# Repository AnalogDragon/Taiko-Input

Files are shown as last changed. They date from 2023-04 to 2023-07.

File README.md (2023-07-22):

# Taiko Input

太鼓输入硬件，usb为HID设备，可以连接2个鼓和8通道的数字量输入。  
文中所提到的太鼓-虹相关的软件，皆下载自互联网。

- [English Version](./README_EN.md)

## [硬件工程](./HW/)
## [USB 单片机](./USB-MCU/)
## [采样单片机](./Sampling-MCU/)
## [上位机](./QT-APP/)
## [文档](./TEXT/)

## 工程结构：
```
|—— HW
    |—— taiko-io
    |—— taiko-io-mini
|—— USB-MCU
    |—— TK_usb_CH552
    |—— TK_usb_CH552_mini
|—— Sampling-MCU
    |—— 8chV3_WithCH552
|—— QT-APP
    |—— APP1_Taiko_IO_Setting
|—— TEXT
```

## HW 硬件工程

硬件工程位于此目录下。  

`taiko-io/`目录内的是双鼓的工程，可用于两个鼓的使用环境（街机），工程使用KICAD设计。  
此项目硬件包含8路模拟输入和8路数字量输入，板载配置接口，单usb供电。  

`taiko-io-mini/`目录内的是单鼓的工程，一般用于一个鼓的使用环境，工程使用LCEDA设计。  
此项目硬件包含4路模拟输入和4个按键，需要测试点配置，单usb供电。  

## USB-MCU USB单片机

USB单片机的软件工程位于此目录下。包含两个软件，根据硬件不同，适配的软件工程也不同。  
使用的单片机为 CH552/CH554，是一款USB 8位单片机。  

`TK_usb_CH552/`目录内的软件适配双鼓硬件（街机），能枚举成为一个USB-HID键盘。  

`TK_usb_CH552_mini/`目录内的软件适配单鼓硬件，可以枚举成不同的USB设备。比如说USB-HID键盘或n******o switch适用的手柄设备。  

软件使用keil 4编译，编译前根据宏可以关闭/打开相关的软件功能。  

## Sampling-MCU 采样单片机

采样单片机的软件工程位于此目录下。软件使用宏区分两款硬件。  
使用的单片机为 STM32G030。  

软件使用keil 5编译，编译前根据宏可以关闭/打开相关的软件功能，切换硬件版本。  

## QT-APP 上位机

上位机的软件工程位于此目录下。上位机可以用于配置硬件的相关参数。  

使用的UI框架为QT 5  

## TEXT 文档

一些中间文档和输出文档位于此目录下。  

# 系统框图
详见[硬件工程](./HW/)  

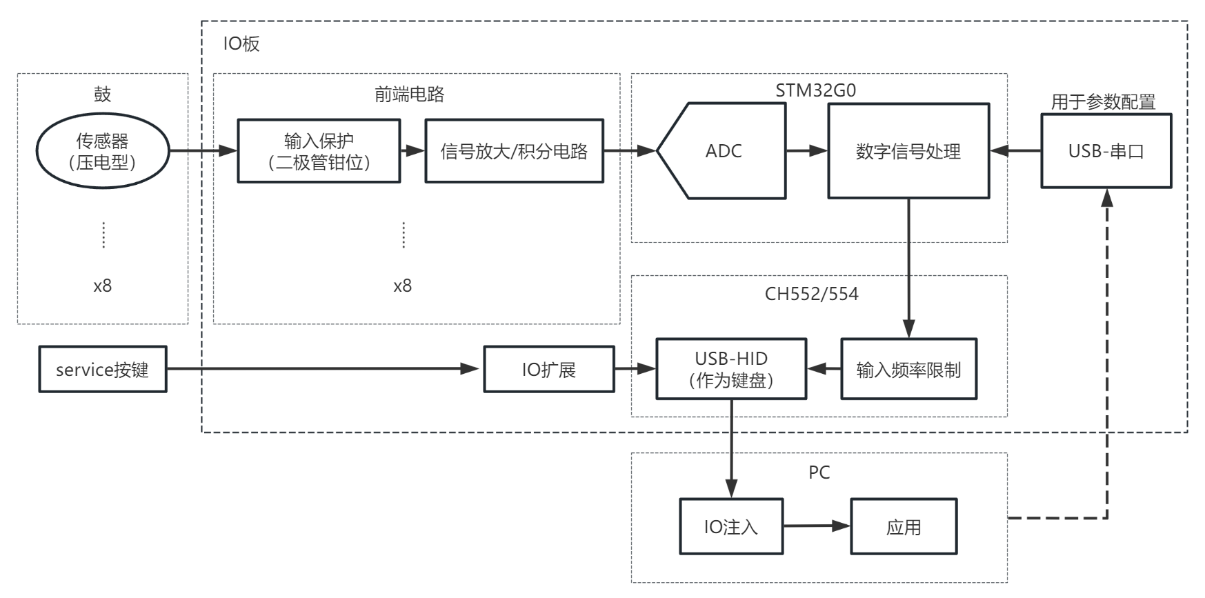
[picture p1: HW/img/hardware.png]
系统框图
  
系统框图  

# 做的一些裂开设计

    主要是通过观察游戏运行的特征，去做体验上的优化。可能合理也可能不合理。

## 游戏软件运行的观察
- 输入频率限制：ns平台的游戏与虹均有输入频率限制。经过测试，每个player独立的。同一个玩家，单个通道限制最高30次每秒，四个通道一起限制60次每秒。超过这个频率的输入会被扔掉。  
也就是说如果只敲左咚或者右咚，则最多30打每秒，而如果左右咚交替输入，能提高到60打每秒。  

- ns平台本身的硬件限制：按键输入会有一个很长的滤波，且按下与松开均需要保持一段时间才能生效。  
在ns游戏内，这个一段时间需要大于20ms。但是主页上则要远大于20ms甚至要到100ms，可能是ns支持可变滤波时间。  

- 虹的数据注入：

## 输出交叉分配

功能实现放在了[USB 单片机](./USB-MCU/)

由于机能或软件运行方式，不同的软件支持的输入最大频率不同，分配输出主要原因是为了能使输入频率达到这台设备的上限。  
表现就是在触发频率高的时候，同一个通道的输入会分配到另一个通道，不同的设备采取的方案不相同。  
- ns：按键消抖做的比较激进，直接在有高频输入的时候，优先分配给同侧的两个按键。
- 虹：游戏软件限制了全局输入的最高频率和单个通道输入的最高频率，可能是为了方便计算图像，这边限制了单一个通道的输入频率，且将同为“咚”的输入分配给空闲的通道。
- PC的其他应用（比如说Open Taiko等）：软件没有做输入频率限制，所以不需要做分配。  

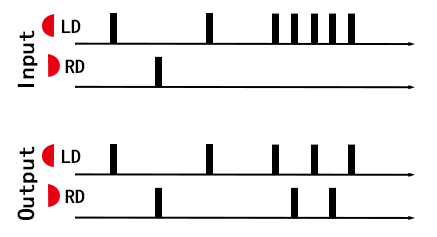
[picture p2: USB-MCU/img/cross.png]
交叉分配
  
适配虹的交叉分配示意图  

## 信号触发与串音检测

多路信号同时输入的时候，会选择触发幅值更高的通道。  
鼓的传感器被固定在几块相对独立的木板上。通常情况下，直接敲击木板得到的信号，强度是远大于受震动干扰或串扰带来的信号。  

这里的做法是，在首次触发后做微小的延时等待其他通道触发。如果在这期间有多个通道被触发，则输出这里面最强信号的通道。  

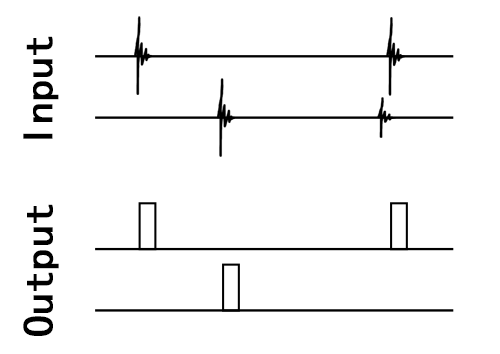
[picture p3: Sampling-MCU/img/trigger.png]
触发

触发示意图  

    如果怎么调都会串音，需要考虑是鼓的结构导致的。检查鼓是不是传感器脱落，木板是不是调节的高度不合适等。

# 外观

详见[硬件工程](./HW/) 

## 双鼓硬件（街机/两个鼓场景）

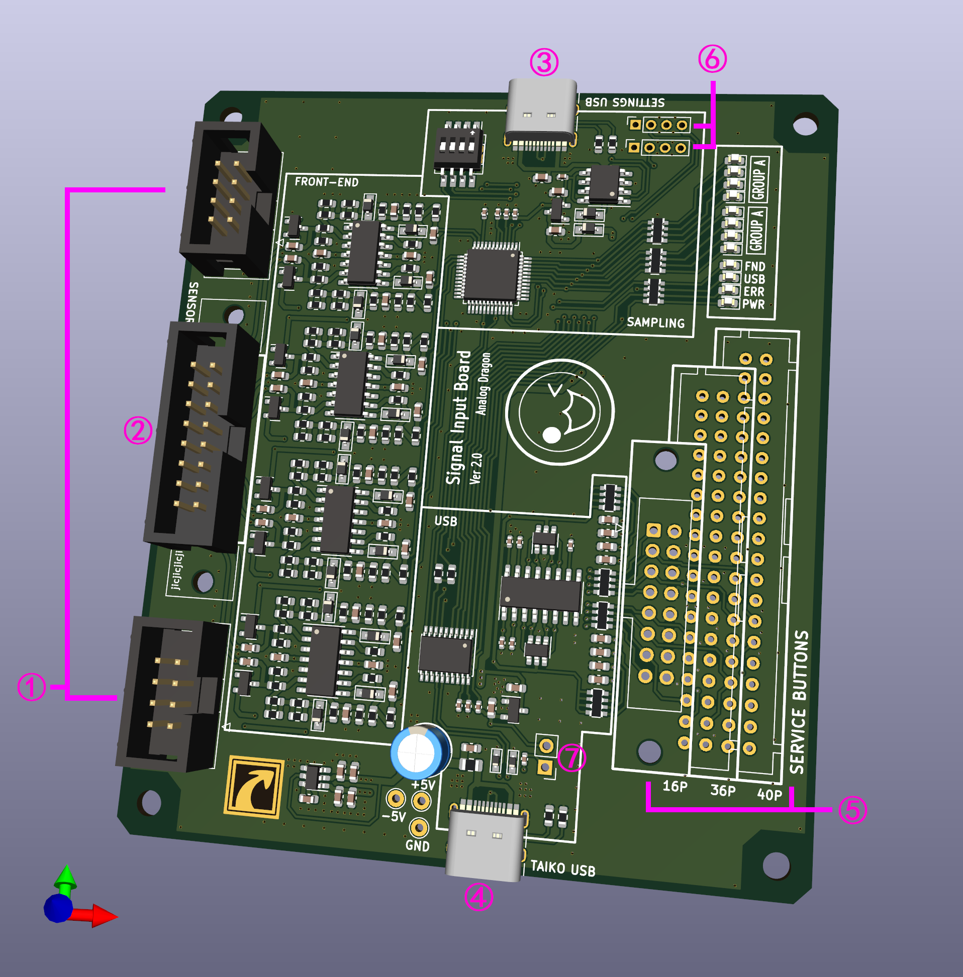
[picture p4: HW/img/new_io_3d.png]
双鼓的硬件3d图

双鼓的硬件3d图  

## 单鼓硬件（自己玩）

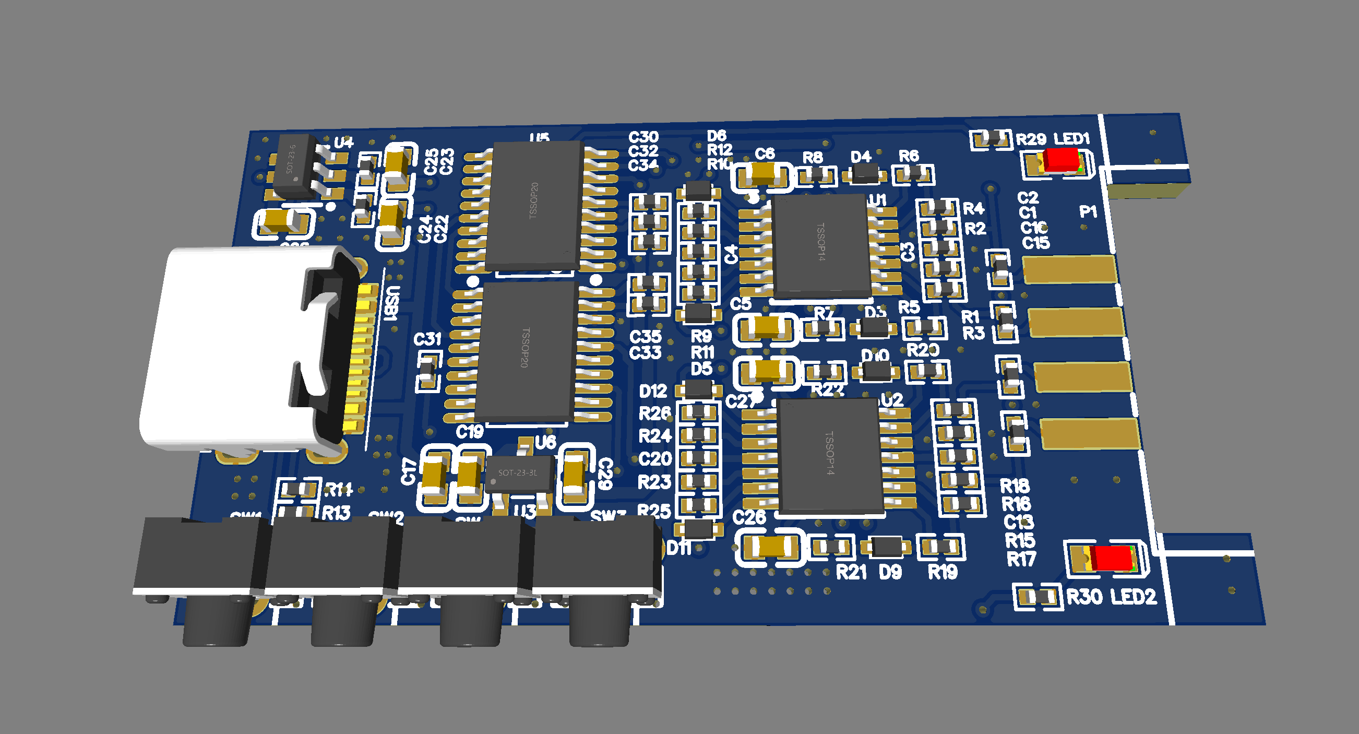
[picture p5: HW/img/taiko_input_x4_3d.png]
单鼓的硬件3d图
  
单鼓的硬件3d图

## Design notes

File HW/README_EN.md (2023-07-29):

# Taiko Input Hardware

Taiko Input Hardware

There are dual taiko and single taiko hardware options. The dual taiko design is intended for arcade or two-taiko setups, while the single taiko hardware is a simplified version of the dual taiko hardware with half of the input frontend removed. There are no significant differences between the two in terms of hardware.

[中文版](./README.md)

[Home](../)

## Hardware Structure

The entire system is composed of sensors (taiko), frontend, sampling, USB, and PC. The frontend, sampling, and USB are located on the input hardware. In addition, there are other components such as power supply and filtering circuitry not shown in the structural diagram.

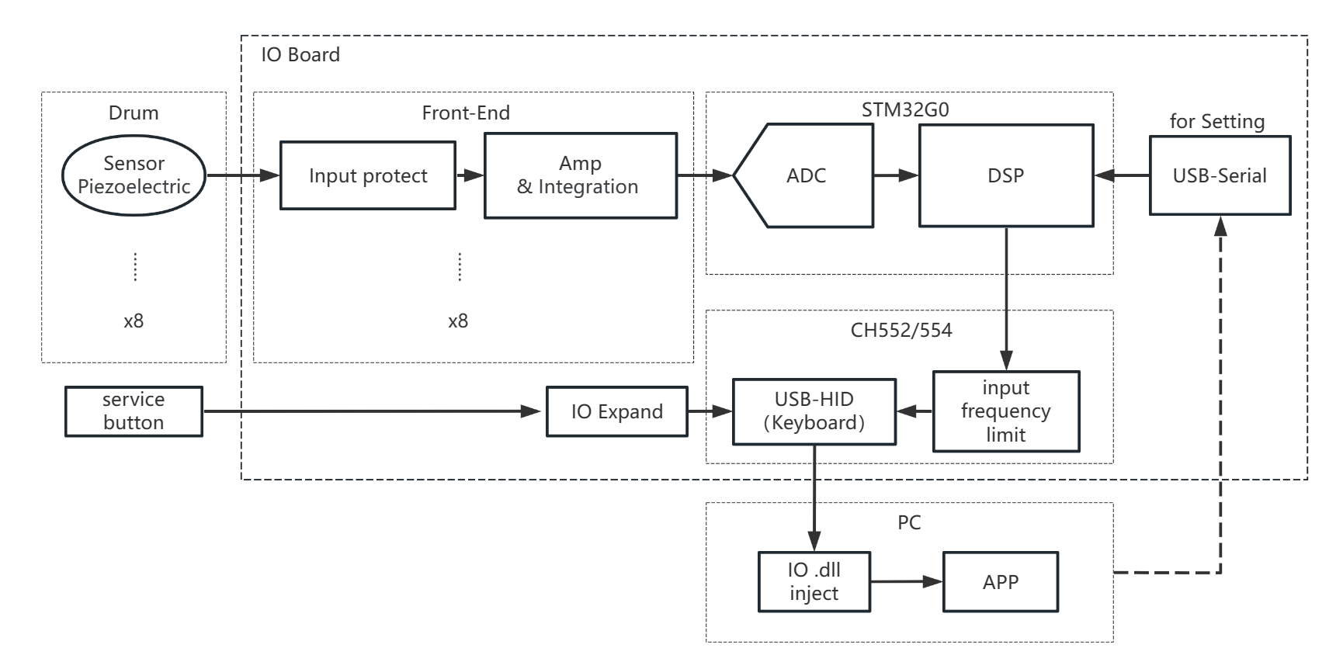
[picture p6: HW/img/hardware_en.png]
Hardware Structure Diagram

Hardware Structure

## Frontend Circuitry

The frontend circuitry adopts a design similar to the SIF Board, amplifying and integrating the signal before limiting the output.

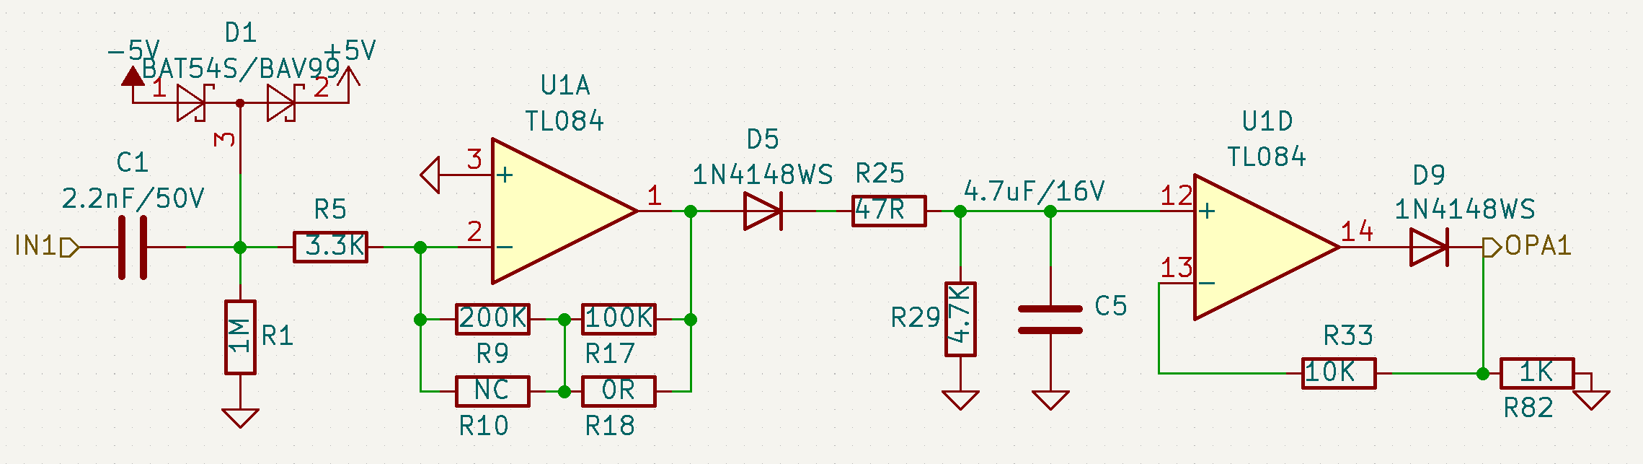
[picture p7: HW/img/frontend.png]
Frontend Circuitry

One of the frontend circuitry paths

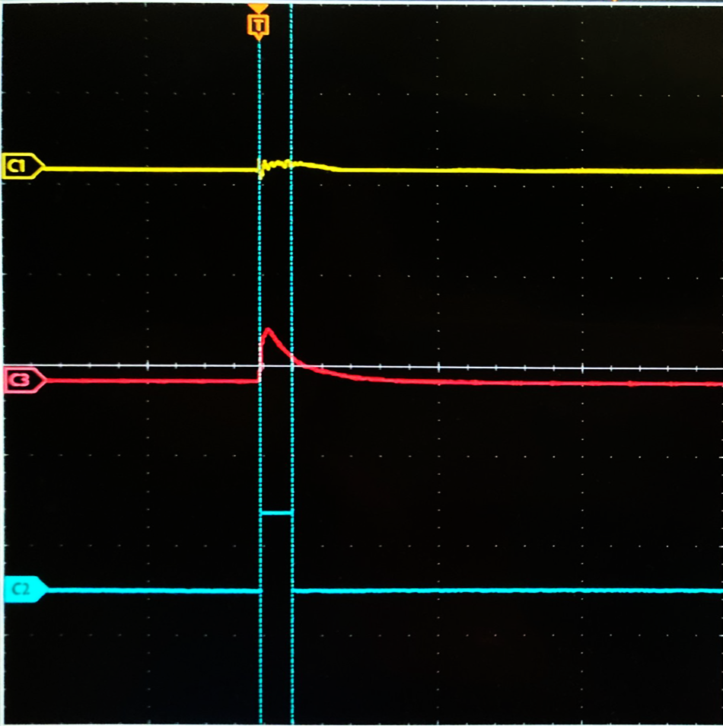
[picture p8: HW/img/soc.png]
Frontend Circuitry Test Signal

Signal waveform

Due to the high bandwidth and small signal amplitude from the piezoelectric sensors, direct sampling is not suitable. The frontend circuitry processes the input signal into a form that is suitable for sampling. In the oscilloscope screenshot, C1 (yellow) represents the sensor output, C3 (red) represents the signal after frontend processing, and C2 (blue) represents the output after program recognition.

# Hardware

The hardware consists of dual taiko hardware and single taiko hardware. The dual taiko hardware is the complete version, suitable for arcade environments. The single taiko hardware is a modified version of the dual taiko hardware with half of the input circuit removed, and it is compatible with more single-player scenarios in software.

## Dual Taiko Hardware

[Hardware Engineering](./taiko-io/)
[Schematic](./taiko-io/new_io.pdf)

3D View of Dual Taiko Hardware
3D view of dual taiko hardware

### Interfaces

- 1 Two single taiko input interfaces, with interface definitions inspired by Taiko Force.
- 2 One dual taiko input interface that can be soldered with an IDC-16P ribbon connector or an XAD connector (B16B-XADSS-N) to accommodate different interfaces of dual taiko.
- 3 Configuration USB interface for configuring the sampling microcontroller.
- 4 Taiko USB interface, when plugged into a computer, it enumerates as a USB-HID keyboard device for receiving taiko data.
- 5 Service button input, soldered with an XAD or IDC connector to connect different button panels. The 16P interface is for custom connections, 36P is for the old(12th) IO board interface(B36B-XADSS-N), and 40P is for newer the frame's IO board interface(B40B-XADSS-N). It can connect up to 8 buttons with common ground.
- 6 STM32 burning interface and configuration serial port.
- 7 CH552/CH554 boot selection switch.

## Single Taiko Hardware
[Hardware Engineering](./taiko-io-mini/)
[Schematic](./taiko-io-mini/Taiko_input_x4.pdf)

3D View of Single Taiko Hardware 3D View of Single Drum Hardware
3D view of single taiko hardware

### Interfaces

- Can only connect 4-channel sensors for a single taiko, with interface definitions inspired by Taiko Force.
- Four buttons for mode selection and other functions.

# Assembly

## Dual Taiko Hardware

The dual taiko hardware does not have an external enclosure. It is assembled directly using screws, following the assembly approach commonly used in arcades.

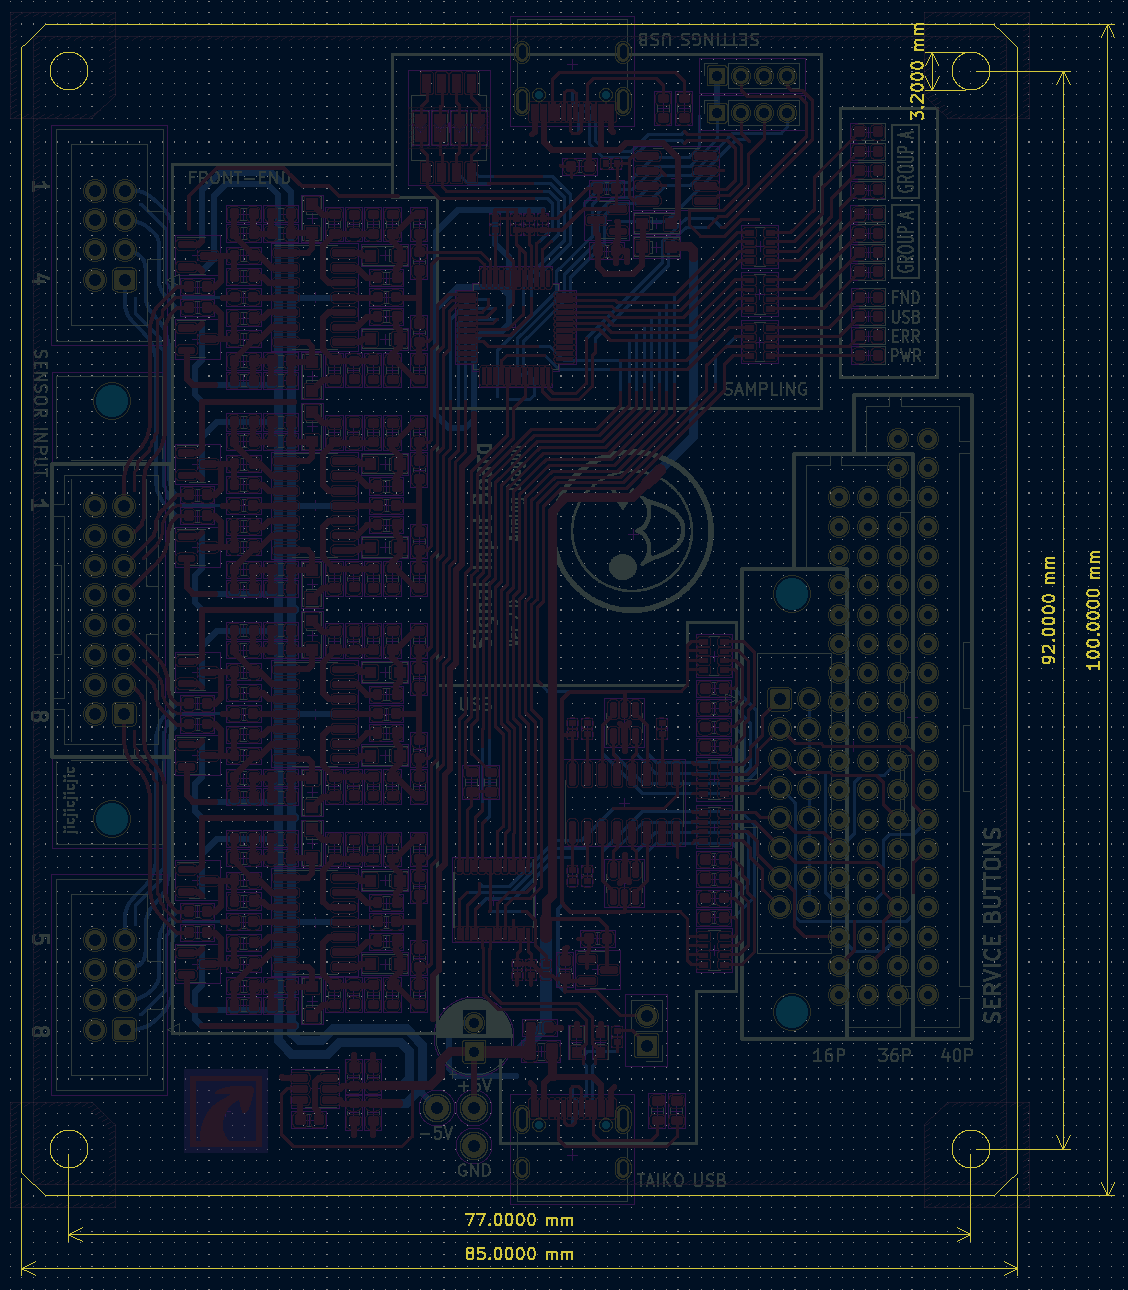
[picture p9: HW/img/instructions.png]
Assembly Dimension Diagram

Assembly Dimension Diagram

## Single Taiko Hardware

The single taiko hardware uses a more common and portable casing, making it easier to carry and connect.

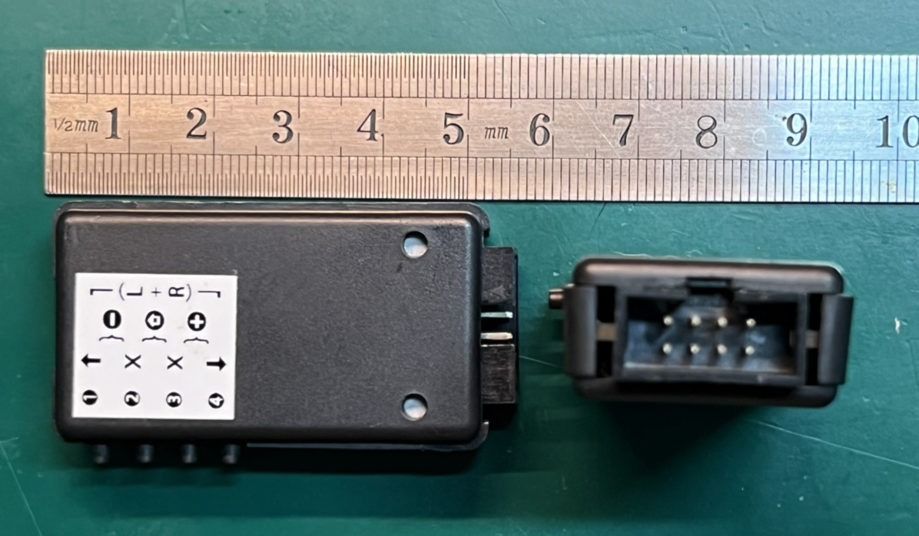
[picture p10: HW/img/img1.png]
Assembly Illustration 1

Assembly Illustration 1  

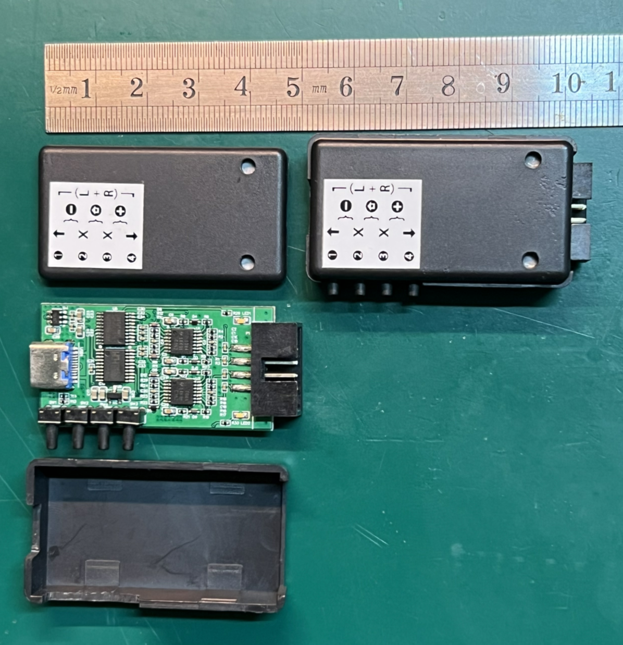
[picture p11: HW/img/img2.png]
Assembly Illustration 2

Assembly Illustration 2  

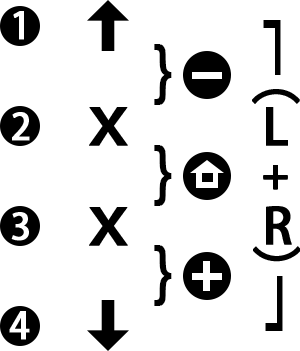
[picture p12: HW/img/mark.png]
tag
  
tag

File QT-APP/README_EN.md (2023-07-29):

# Host Computer
    QT, WIN64
    The host computer software is used to configure the parameters of the sampling microcontroller.

[中文版](./README.md)

[Home](../)

## Instructions

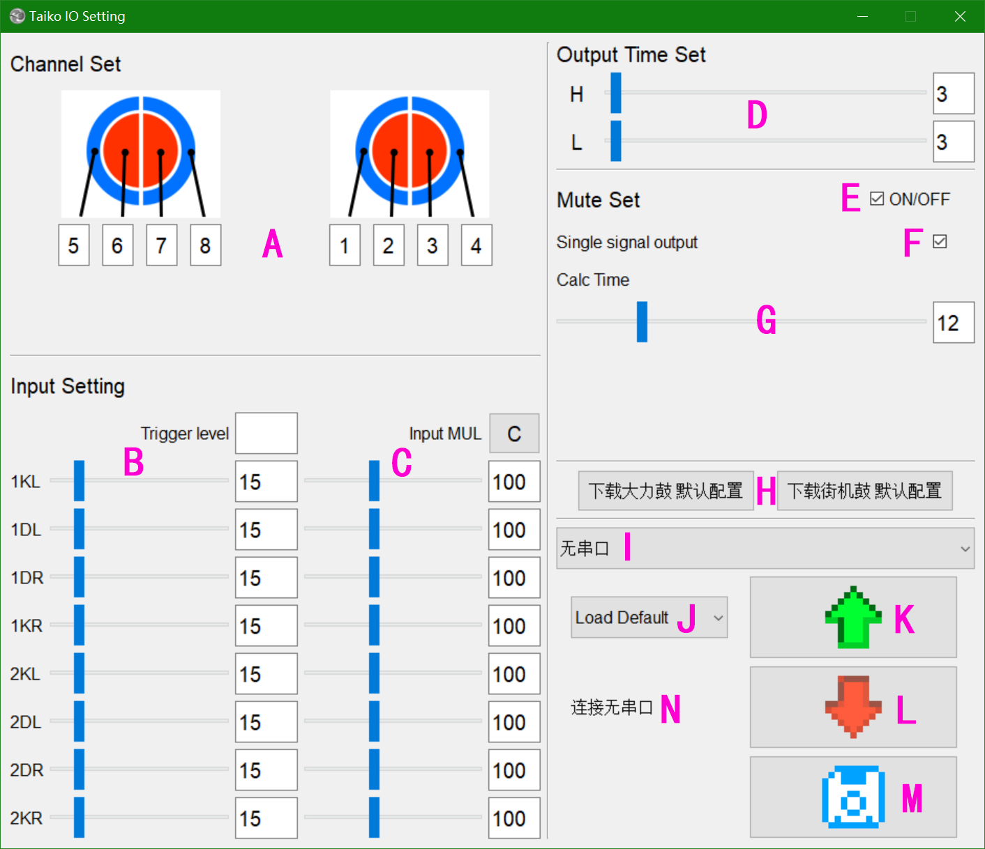
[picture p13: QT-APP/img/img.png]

Screenshot  

### Software Interface

- A-Taiko sensor channel sequence configuration
- B-Input configuration-Trigger threshold (triggering is done in hardware, no obvious effect in software configuration)
- C-Input configuration-Multiplication factor (configure this when a certain sensor is exceptionally sensitive or insensitive, C for reset)
- D-Output time configuration, H for hold time when pressing, L for hold time when releasing, no response to other inputs during hold time
- E-Shielding configuration (used to calculate crosstalk caused by the physical structure of the taiko)
- F-Shielding configuration-Single response (selecting this will trigger only one sensor each time)
- G-Shielding configuration-Calculate rounds (set to 0 to disable calculation, directly trigger according to the fastest speed)
- H-Some default parameters (for Taiko Force and arcade taiko)
- I-Serial port selection
- J-Select the parameter group on the upload board
- K-Upload parameter button
- L-Download parameter button (this step does not store data, data will be lost when the microcontroller is reset)
- M-Save parameter button
- N-Software status

### Configuration Process

- 1 Select the serial port, click upload, and the status will be displayed as `Success` (used to determine if the connection is successful)
- 2 Reset the preset parameters according to your needs or upload old parameters
    - For modifications based on the old parameters, select `Load Saved`, and then press the upload parameter button
    - For modifications based on the default configuration, click the desired default configuration button (the two default configurations only differ in taiko mapping)
- 3 After making modifications, click the download parameter button and confirm if the parameters are reasonable on the taiko
- 4 Click the save parameter button

## Other Instructions
- When using single taiko hardware, the parameters for the second taiko are meaningless
- Default configurations may have issues; you can make fine adjustments based on the default parameters to suit your taiko
- The sensor wire sequence of the taiko can be remapped through this APP.

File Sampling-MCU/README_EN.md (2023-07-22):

# Sampling MCU Project
    Sampling Microcontroller Software
    MCU: stm32g030, IDE: KEIL 5

[中文版](./README.md)  

[Home](../)  

## Dual Taiko Version and Single Taiko Version

Differentiate the software between dual taiko and single taiko hardware using macros in /main.h/.  
It is important to note that the software compiled for single taiko hardware cannot be used on dual taiko hardware due to differences in initialization.  

Single Taiko Version:
```
...
#define IS_4CH_MODE 
...
```

Dual Taiko Version (comment out this line of code):
```
...
//#define IS_4CH_MODE 
...
```

## Digital Signal Processing

Digital signal processing mainly involves trigger handling, debouncing, and determining if there is signal crosstalk.  
Since the taiko contains a physical structure, vibrations can cause signal misfires. Therefore, it is necessary to determine and output the signals received at the same time.  

### Processing Flowchart

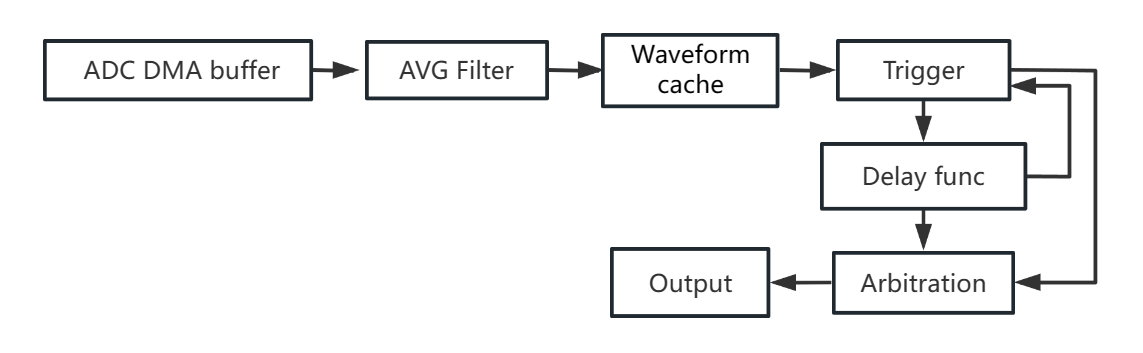
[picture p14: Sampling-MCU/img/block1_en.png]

Data flow diagram  

After the signal is sampled, it is recorded as a waveform array, and a trigger function is used to determine if there is a signal with the expected strength.  
The delayed output ensures that when a signal arrives, it does not miss the trigger of other sensors. If other channels are triggered during the delay, the triggered values will also be recorded.  
The arbitration function determines the maximum strength among the triggered channels during the delay, and then reset the states of other functions.  
The output signal is sent to the USB microcontroller by the output device.  

### Signal Triggering and Crosstalk Detection

When multiple signals are input simultaneously, the channel with the higher amplitude will be triggered.  
The taiko sensors are fixed on several relatively independent boards. Typically, the signal obtained by directly striking the board has a much higher strength than the signals caused by vibration interference or crosstalk.  

The approach here is to wait for a small delay after the initial trigger to allow other channels to trigger. If multiple channels are triggered during this period, then the channel with the strongest signal among them is output.  

Triggering
Triggering illustration  

## Software Flowchart

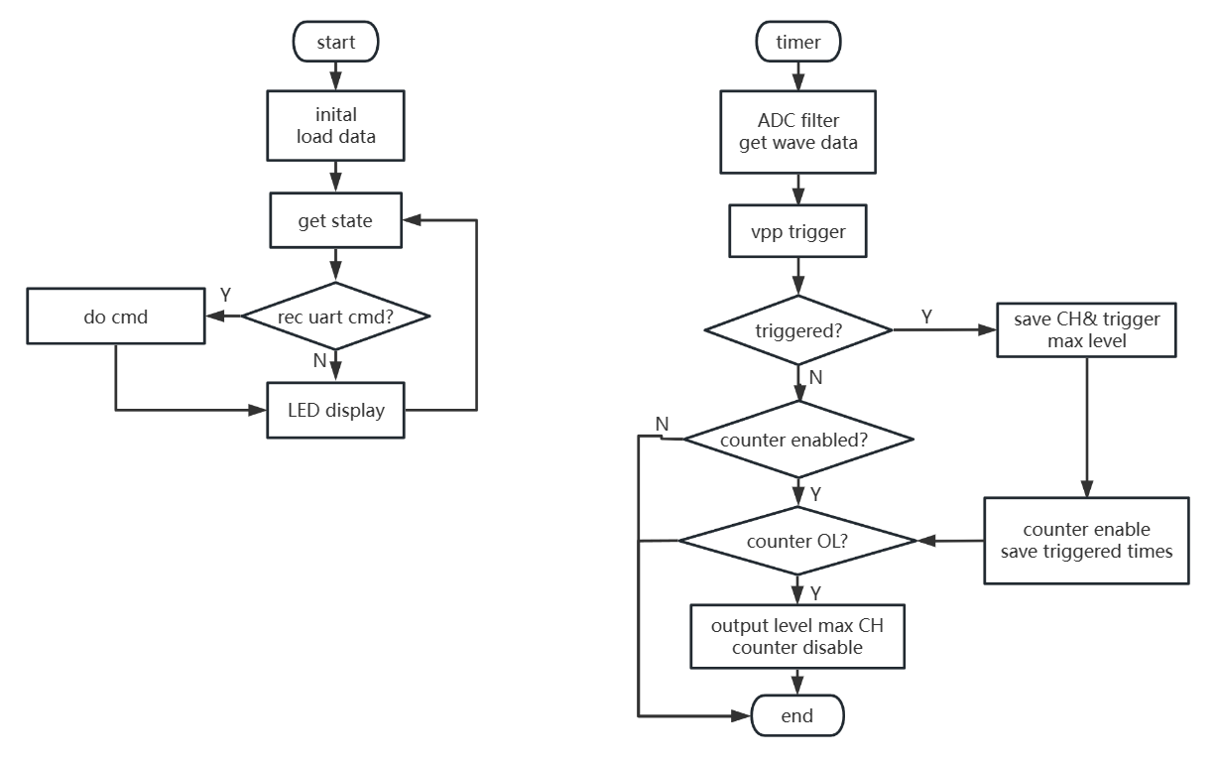
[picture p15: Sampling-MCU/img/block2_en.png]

Data flow diagram  

The software can be configured for speed-priority triggering (setting the period to 0) or maximum peak triggering.  
The longer the number of cycles, the longer the calculated period. When the number of cycles is set to 0, triggering is performed in a speed-priority manner.  

## Configuring Sampling Parameters

Sampling parameters are configured through the upper computer software  

[Upper Computer Software](../QT-APP/)  

## Data Output

Data is sent to the computer using a USB microcontroller  

[USB MCU Software](../USB-MCU/)

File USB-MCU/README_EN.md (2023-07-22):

# USB-MCU Project

[中文版](./README.md)  

[Homepage](../)  

MCU: CH552, IDE: KEIL 4  
Microcontroller's official website: [WCH CH552](https://www.wch.cn/products/CH552.html)  

## Software Flow
The software runs according to the following flow:

```
Input -> Output Frequency Limitation -> Output Assignment -> Key Mapping -> USB
```

### Output Frequency Limitation
The output frequency limitation is mainly due to the hardware or program that receives the data. When it receives data that exceeds its processing capability, packet loss may occur.  
After multiple tests, the software input limitation for ニジイロ is a maximum input frequency of 60Hz for all channels and 30Hz for signals of the one channel.  
The n******o switch limits the input signal filter to 20ms (both press and release are around 20ms; values smaller than this may result in sticky inputs).  
Other game software running on different computers usually doesn't have this convenient limitation, but there is usually a filtering of around 10ms on the selection page.  

### Output Assignment
Due to different device capabilities or software running methods, different software support different maximum input frequencies. The purpose of allocating the output channels is to achieve the input frequency limit of the particular device.  
The behavior observed is that when the triggering frequency is high, inputs from the same channel will be allocated to another channel. Different devices adopt different approaches:
- ns: Aggressive debouncing is performed, and when there are high-frequency inputs, they are allocated primarily to the two adjacent keys on the same side.
- ニジイロ: The game software limits the maximum global input frequency and the maximum input frequency for a single channel. This may be for the convenience of calculating images. Here, the input frequency for a single channel is limited, and inputs of the same type (e.g., same "dong") are allocated to idle channels.
- Other applications on PC (such as Open Taiko): These software programs do not have input frequency limitations, so no allocation is needed.

Cross Assignment  
Cross assignment diagram for compatibility with ニジイロ  

### Key Mapping
- For dual-taiko hardware, taiko inputs are mapped to keyboard inputs DFJK ZXCV, and service key inputs are mapped to keyboard inputs 12345678.
- For single-taiko hardware, there are two modes: NS mode and keyboard mode. For NS mode, the input keys are shown in the image below. For keyboard mode, you can set the inputs as DFJK or ZXCV through the buttons, with DFJK being the default.

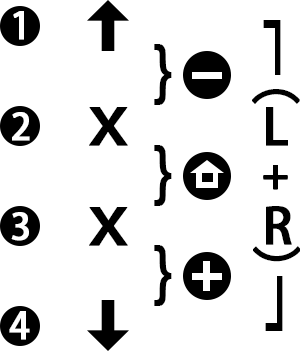
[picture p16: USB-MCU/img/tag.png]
Tags
  
Tags for single-taiko hardware  

## Modifying the Program

### Dual-taiko Software

- To disable the output assignment feature, modify the `WITHOUT_OUTPUT_ASSIGN` macro inside `CompatibilityHID.C` by uncommenting it.
- To modify the parameters related to output frequency limitation, modify the `EXCHANGE_DATA` macro inside `CompatibilityHID.C`.
- To change the key values, modify the array inside the `Enp2BlukIn` function in `CompatibilityHID.C`.

### Single-taiko Software
The single-taiko software integrates three modes: NS mode (using HORI's PID/VID, where NS only verifies the PID/VID without any further encryption); keyboard mode compatible with ニジイロ (60Hz input lock); and keyboard mode compatible with other taiko taiko software (unlock the limitations and disable the output assignment).

- To change the default startup mode, modify the `MODE_STARTUP` macro inside `CompatibilityHID.C`.
- To switch modes during startup within 1 second, use the following button combinations:
```
...
if(!KEY1)start_up_mode = MODE_NS_GP;
if(!KEY2)start_up_mode = MODE_KEYBOARD;
if(!KEY3)start_up_mode = MODE_KB_LMT;
if(!KEY4)start_up_mode = MODE_STARTUP;
...
```
- During runtime, holding down buttons 1 to 4 will trigger a reset, allowing you to switch modes again.

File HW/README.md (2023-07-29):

# Taiko Input 硬件

Taiko Input 硬件

分为双鼓与单鼓硬件，双鼓设计用于街机或两个鼓的场景，单鼓的硬件则是双鼓硬件简单地切去一半输入前端设计的，在硬件上两者并无很大的差异。

[English Version](./README_EN.md)  

[主页](../)  

## 硬件结构

    整体系统分为传感器（鼓）、前端、采样、USB、PC，其中前端、采样、USB三部分位于input硬件上。
    除此之外还，有电源、滤波电路等未在结构图中体现。

硬件结构图
硬件结构  

## 前端电路

    前端电路采用了与SIF Board近似的设计，先进行信号的放大与积分，再限制输出。

前端电路
其中一路前端电路    

前端电路测试信号
信号的波形

由于来自压电传感器的信号带宽高且信号幅值小，不宜直接进行采样。前端电路将输入信号处理成便于采样的信号。  
在示波器截图中，C1(黄色)为传感器输出，C3（红色）为经过前端电路处理后的信号，C2（蓝色）为程序识别后的输出。  

# 硬件

    硬件分为双鼓硬件和单鼓硬件，双鼓硬件为完整版的硬件，可以用于街机环境。  
    单鼓硬件为双鼓硬件删去一半输入电路的硬件，软件上兼容了更多的单人应用场景。  

## 双鼓硬件

[硬件工程](./taiko-io/)  
[原理图](./taiko-io/new_io.pdf)  

双鼓的硬件3d图  
双鼓的硬件3d图  

### 接口

- ① 两个单鼓输入的接口，接口定义借鉴了大力鼓（Taiko Force）。
- ② 一个双鼓的输入接口，可以焊接IDC-16P牛角连接器，或者焊接XAD连接器（B16B-XADSS-N）以兼容不同接口的双太鼓。
- ③ 配置USB接口，用于配置采样单片机。
- ④ 太鼓usb接口，插入电脑会枚举成一个USB-HID键盘设备，用于接收太鼓的数据。
- ⑤ service按键输入，焊接XAD连接器或IDC连接器，以连接不同的按键面板。其中16P接口用于自定义的连接，36P用于12亚的IO板接口（B36B-XADSS-N），40P用于更新框体的IO板接口（B40B-XADSS-N）。可以连接最多8个接地始能的按键。
- ⑥ stm32烧录接口和配置串口。
- ⑦ CH552/CH554的boot选择开关。

## 单鼓硬件
[硬件工程](./taiko-io-mini/)  
[原理图](./taiko-io-mini/Taiko_input_x4.pdf)  

单鼓的硬件3d图  
单鼓的硬件3d图  

### 接口

- 只能连接一个鼓的4路传感器，接口定义借鉴了大力鼓（Taiko Force）的接口。
- 四个按键用于启动的模式选择和其他按键。

# 装配

## 双鼓硬件

    双鼓硬件不设计外盒，借鉴街机的装配方式为使用螺柱直接装配。

装配尺寸图  
装配尺寸图  

## 单鼓硬件

    单鼓的硬件使用了一款较通用的胶盒，可以较为方便的携带和连接。

装配示意图1  
装配示意图1  

装配示意图2  
装配示意图2  

标签  
标签

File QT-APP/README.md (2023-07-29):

# 上位机
    QT，WIN64  
    上位机软件用于配置采样单片机的参数。  

[English Version](./README_EN.md)  

[主页](../)  

## 使用说明

软件截图
软件截图  

### 软件界面

- A-鼓传感器通道顺序配置
- B-输入配置-触发阈值（硬件上做了触发，软件配置这里没有很明显的效果）
- C-输入配置-倍率（当某一路传感器异常灵敏或不灵敏时配置这里，C为复位）
- D-输出时间配置，H为按下保持时间，L为松开保持时间，保持时间内不响应其他输入
- E-屏蔽配置（用于计算鼓的物理结构带来的串音影响）
- F-屏蔽配置-单次响应（选择后每次只会触发一个传感器）
- G-屏蔽配置-计算回合数（设置为0时不计算，直接按照速度最快触发）
- H-一些默认参数（大力鼓和街机鼓）
- I-串口选择
- J-选择上载板上的参数组
- K-上载参数键
- L-下载参数键（这一步不会存储，复位单片机会丢失数据）
- M-保存参数键
- N-软件状态

### 配置流程

- 1 选择串口，点击上载后，显示状态为`Success`（用于判断是否连接成功）
- 2 根据需求重置预设参数，或上载旧的参数
    - 需要在旧参数的基础上修改的，选择`Load Saved`，再按上载参数键
    - 需要在默认配置基础上修改的，直接点按需要的默认配置按钮（两种默认配置只有鼓的映射不同）
- 3 修改后，点击下载参数键后，在鼓上确认参数是否合理
- 4 点击保存参数键

## 其他说明
- 使用单鼓硬件时，第二套鼓的参数无意义
- 默认配置可能会存在问题，可以在默认参数的基础上进行微调以适应你的鼓
- 鼓的传感器线顺序可以通过本上位机进行重映射

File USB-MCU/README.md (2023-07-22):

# USB-MCU工程

[English Version](./README_EN.md)  

[主页](../)  

MCU：CH552，IDE：KEIL 4  
单片机官网：[沁恒CH552](https://www.wch.cn/products/CH552.html)  

## 软件流程
软件按照如下流程运行  

```
输入 -> 输出频率限制 -> 分配输出 -> 键值映射 -> USB
```

### 输出频率限制
对输出进行频率限制主要是因为接收数据的硬件或程序，收到了超过其处理能力的数据时，会产生丢包的现象。  
经过多次测试，虹的软件输入限制为所有通道输入频率最高为60Hz，相同颜色的信号最高为30Hz。  
n******o switch限制输入信号的时间为20ms（按下与抬起都为20ms左右，小于这个值可能会导致输入与上一个输入粘连）  
其他电脑上运行的自治软件，通常无这方便的限制，但是在选择页面会有10ms左右的滤波。  

### 分配输出
由于机能或软件运行方式，不同的软件支持的输入最大频率不同，分配输出主要原因是为了能使输入频率达到这台设备的上限。  
表现就是在触发频率高的时候，同一个通道的输入会分配到另一个通道，不同的设备采取的方案不相同。  
- ns：按键消抖做的比较激进，直接在有高频输入的时候，优先分配给同侧的两个按键。
- 虹：游戏软件限制了全局输入的最高频率和单个通道输入的最高频率，可能是为了方便计算图像，这边限制了单一个通道的输入频率，且将同为“咚”的输入分配给空闲的通道。
- PC的其他应用（比如说Open Taiko等）：软件没有做输入频率限制，所以不需要做分配。  

交叉分配  
适配虹的交叉分配示意图  

### 键值映射
- 双鼓硬件，鼓的输入映射为键盘输入的DFJK ZXCV，服务按键映射为键盘输入的12345678。
- 单鼓硬件，分为ns和键盘输入，其中ns输入键位见下图，键盘输入可以通过按键设置为DFJK或ZXCV，默认为DFJK。

标签  
单鼓硬件的标签  

## 程序的修改

### 双鼓软件

- 关闭分配输出功能，则需修改将位于`CompatibilityHID.C`内的宏`WITHOUT_OUTPUT_ASSIGN`取消注释。
- 修改输出频率限制相关的参数，修改位于`CompatibilityHID.C`内的宏`EXCHANGE_DATA`。
- 修改键值，则修改位于`CompatibilityHID.C`内的`Enp2BlukIn`函数的数组。

### 单鼓软件
单鼓软件内，集成了三种模式，分别是ns模式（借用了HORI的PID/VID，ns只校验了PID/VID，没做其他加密），适配虹的键盘模式（输出锁60Hz输入），适配其他太鼓软件的键盘模式（解锁限制并关闭分配输出）三种。  

- 修改`CompatibilityHID.C`内的宏`MODE_STARTUP`，则可以修改启动时候默认的模式。  
- 启动前1s内按如下按键，则可以切换模式
```
...
if(!KEY1)start_up_mode = MODE_NS_GP;
if(!KEY2)start_up_mode = MODE_KEYBOARD;
if(!KEY3)start_up_mode = MODE_KB_LMT;
if(!KEY4)start_up_mode = MODE_STARTUP;
...
```
- 运行时，按住1~4所有的按键，则可以进行复位，以重新切换模式。

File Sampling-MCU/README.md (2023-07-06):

# Sampling MCU工程
    采样单片机软件
    MCU：stm32g030，IDE：KEIL 5

[English Version](./README_EN.md)  

[主页](../)  

## 双鼓版本与单鼓版本

根据/main.h/内的宏区分软件双鼓与单鼓硬件。  
值得注意的是编译为单鼓的软件放在双鼓的硬件上是不能使用的，原因是初始化不相同。  

单鼓版本：
```
…
#define IS_4CH_MODE 
…
```

双鼓版本（注释这一行代码）：
```
…
//#define IS_4CH_MODE 
…
```

## 数字信号处理

数字信号处理主要需要处理触发、消抖和判断是否信号串扰。  
由于鼓是包含物理结构的，震动的串扰可以导致信号被误触发。所以需要对同一时间收到的信号进行判断再输出。  

### 处理框图

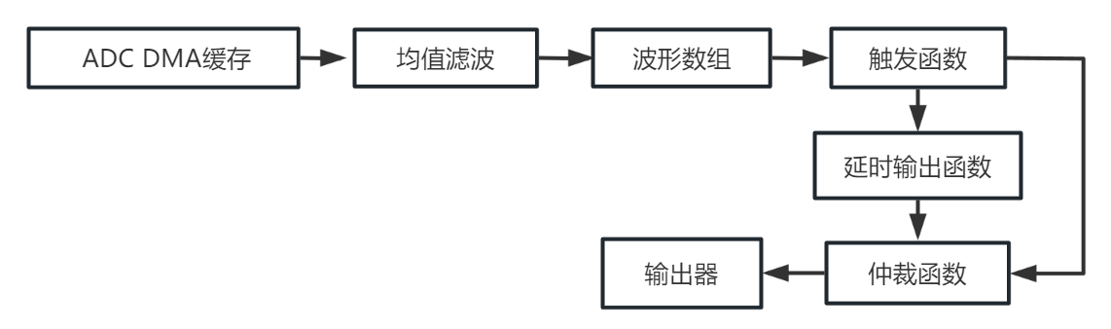
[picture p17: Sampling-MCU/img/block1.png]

数据流向图  

信号被采样后，记录成一个波形数组，通过触发函数来判断是否有符合预期强度的信号。  
通过延时输出来确保信号到来时，不会漏掉其他传感器的触发。当有其他通道在延时期间被触发，则也会记录被触发的值。  
仲裁函数用来判断延时这段时间内，被触发的几个通道中强度最大的值。同时用于复位其他函数的状态。  
输出的信号由输出器输出给USB单片机。  

### 信号触发与串音检测

多路信号同时输入的时候，会选择触发幅值更高的通道。  
鼓的传感器被固定在几块相对独立的木板上。通常情况下，直接敲击木板得到的信号，强度是远大于受震动干扰或串扰带来的信号。  

这里的做法是，在首次触发后做微小的延时等待其他通道触发。如果在这期间有多个通道被触发，则输出这里面最强信号的通道。  

触发
触发示意图  

## 软件流程图

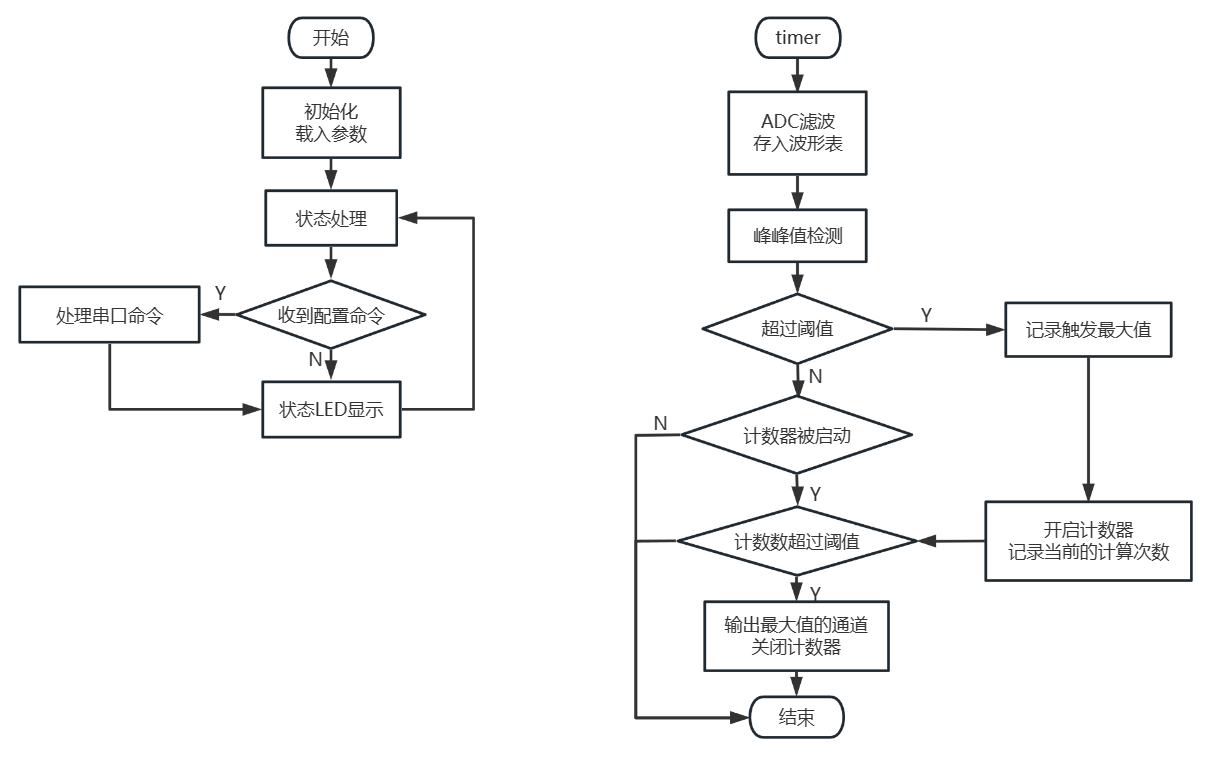
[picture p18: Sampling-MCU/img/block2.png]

数据流向图  

软件可以配置为速度优先触发（周期设置为0）或峰值最大触发。  
回合数越大，则计算的周期越长，当回合数设置为0时，则以速度优先的方式进行触发。  

## 配置采样参数

采样参数通过上位机配置  

[上位机软件](../QT-APP/)  

## 数据输出

数据通过USB单片机发送给电脑  

[USB MCU软件](../USB-MCU/)

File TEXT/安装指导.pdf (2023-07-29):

# 安装指导

### 1. 安装尺寸和出线：

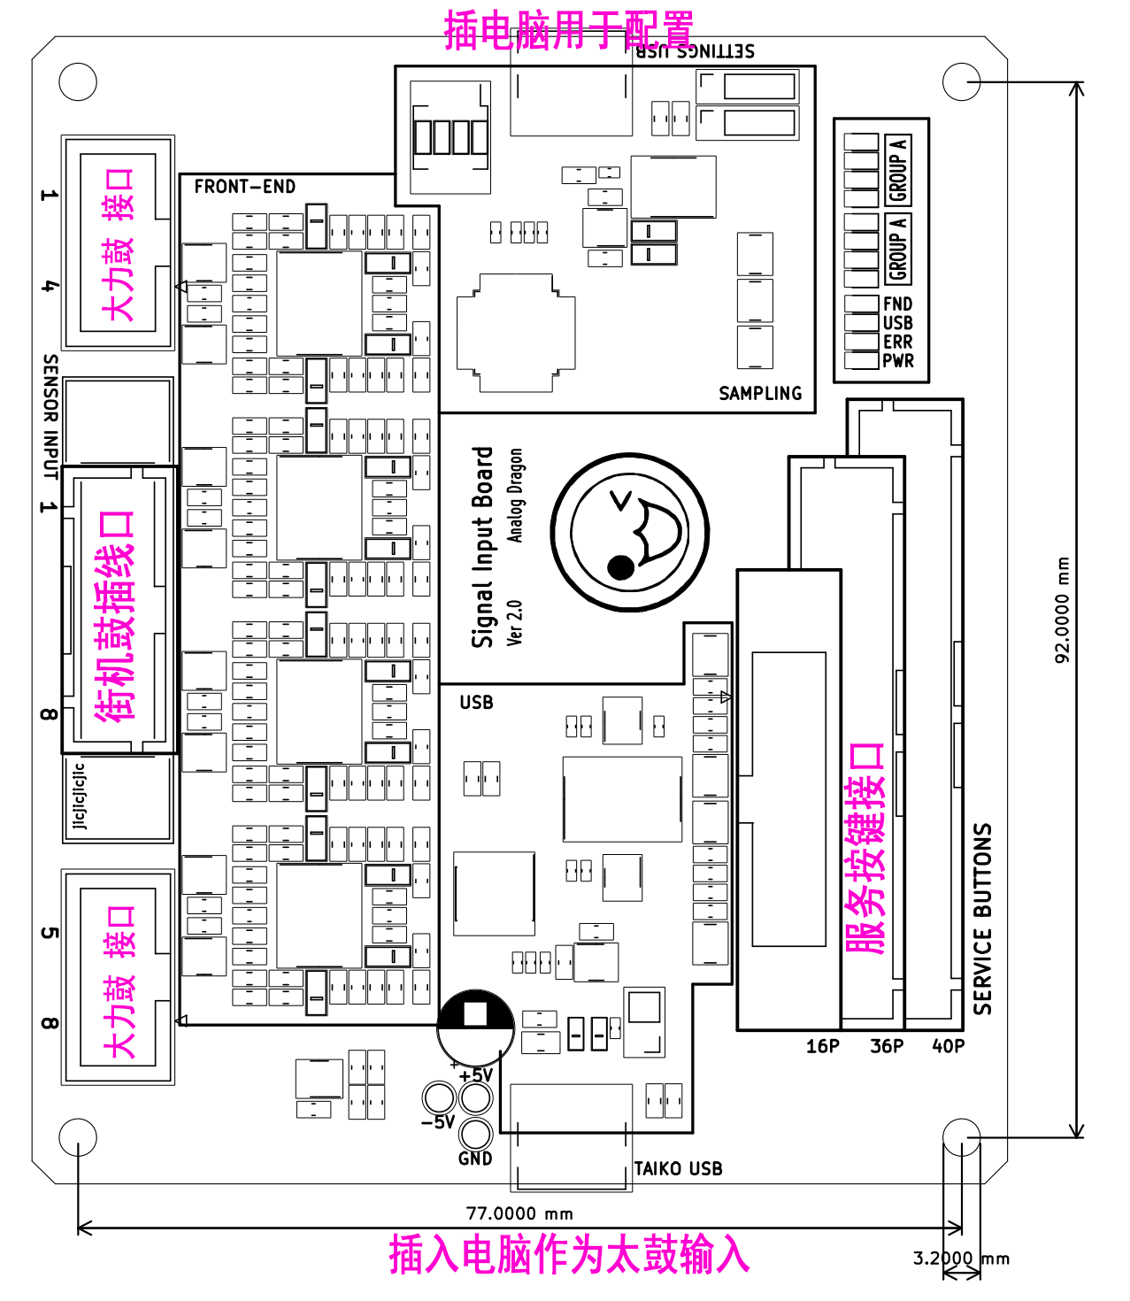
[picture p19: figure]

鼓的连接：
1、 大力鼓：个人使用可以直接将大力鼓线插在大力鼓插口上。
2、 街机鼓：将连接到放大板的鼓线连接到街机鼓接口。可以焊接 IDC-16P 或者 B16B-XADSS-N，以兼容不同的框体。
无论是哪种鼓，都需要配置输入通道后使用。

服务面板的连接：
1、 个人使用：通常无需安装此接口，如果需要使用面板，需要专门准备按键板。 2、 街机使用：12 亚 需要焊接 36P 的连接器（），新框需要焊接 40P 的连接器（），如果是 自制转接线，则焊接 16P 的 IDC 插头。连接后要在程序里设置按键映射，使数字 1~8 映 射到正确的功能。

### 2. 安装注意事项

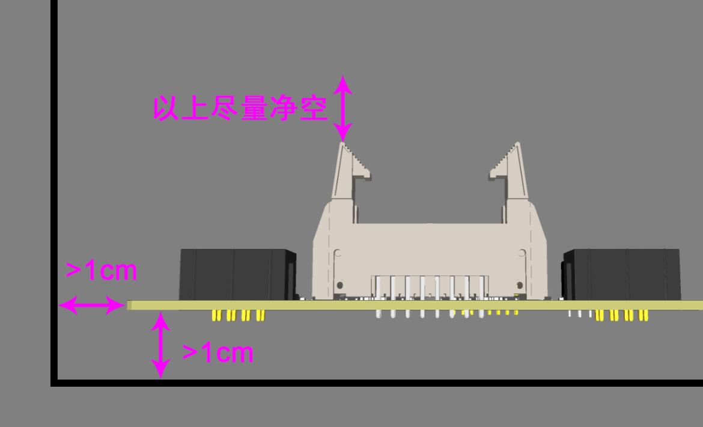
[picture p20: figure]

注意出线方向和净空，并尽量按照上图要求保留安全距离。

安装时不要用手或工具等硬物碰触板上的元器件。

实在没有安装条件时，可以使用纸盒保护（使用合适大小的飞机盒做保护，在盒子相应出线 位置开洞，将线缆伸出来后关闭盒盖即可）。

运行时有一定温度上升是正常现象，但是不要用手去摸。

### 3. 大力接口的注意事项

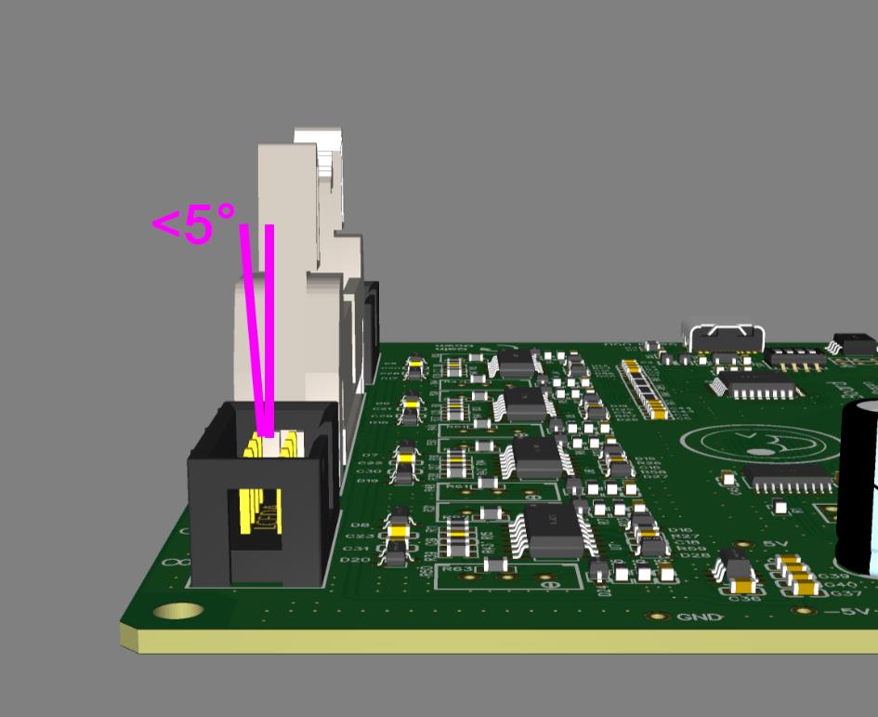
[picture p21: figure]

此接口并非牢固接口，安装后需要严格注意线缆的受力问题。

线缆安装后需要防止晃动，晃动角度不能大于±5°。并且长期处于晃动状态，会降低接口寿 命。
出线方向不能过于歪斜，减少线缆对 IO 板的力。

可以通过大力转接板防止出线应力问题。

# 使用说明

硬件

插入电脑后会枚举成 HID Keyboard，使用键盘模拟输入。 太鼓输入为字母 DFJK-ZXCV，服务按键为数字 1~8。

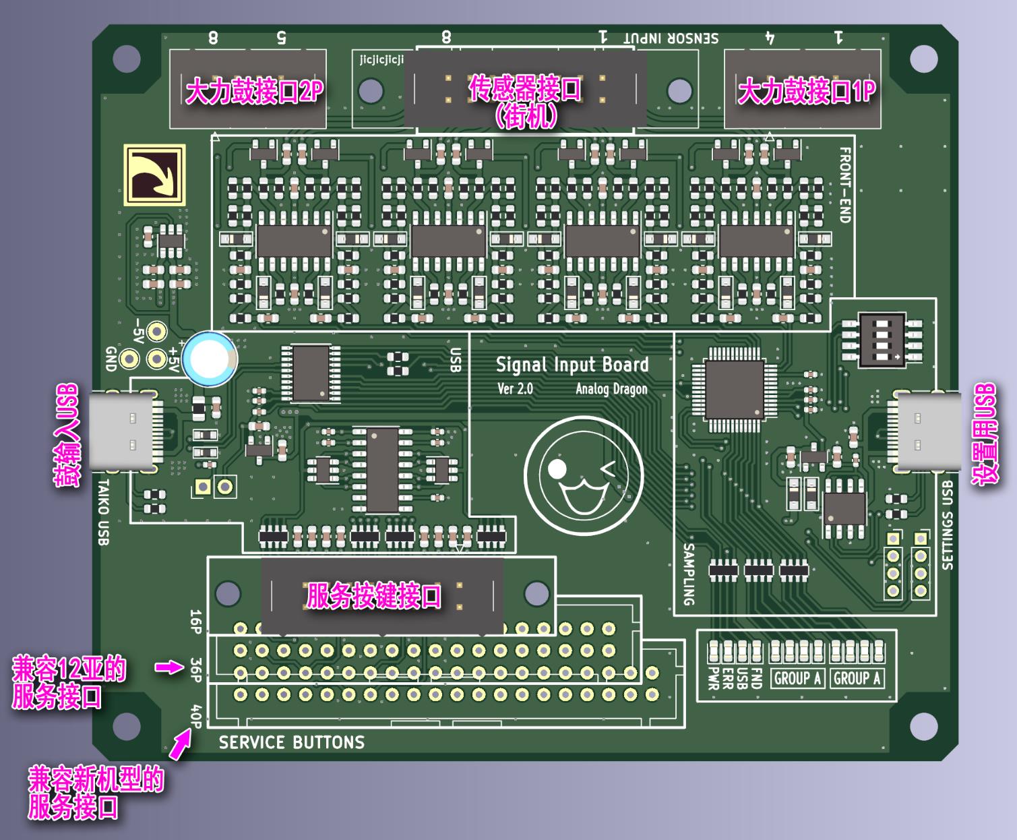
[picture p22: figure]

### 1. 连接传感器(鼓)

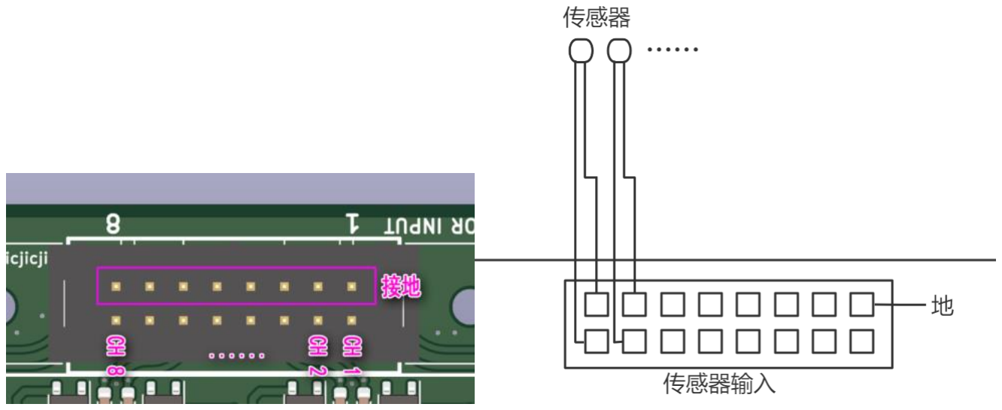
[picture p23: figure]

传感器接口用于连接鼓，接地端子接每个传感器的屏蔽层或者负极，CH1~8 接传感器输出 或者正极。

### 2. 连接服务按键 IO

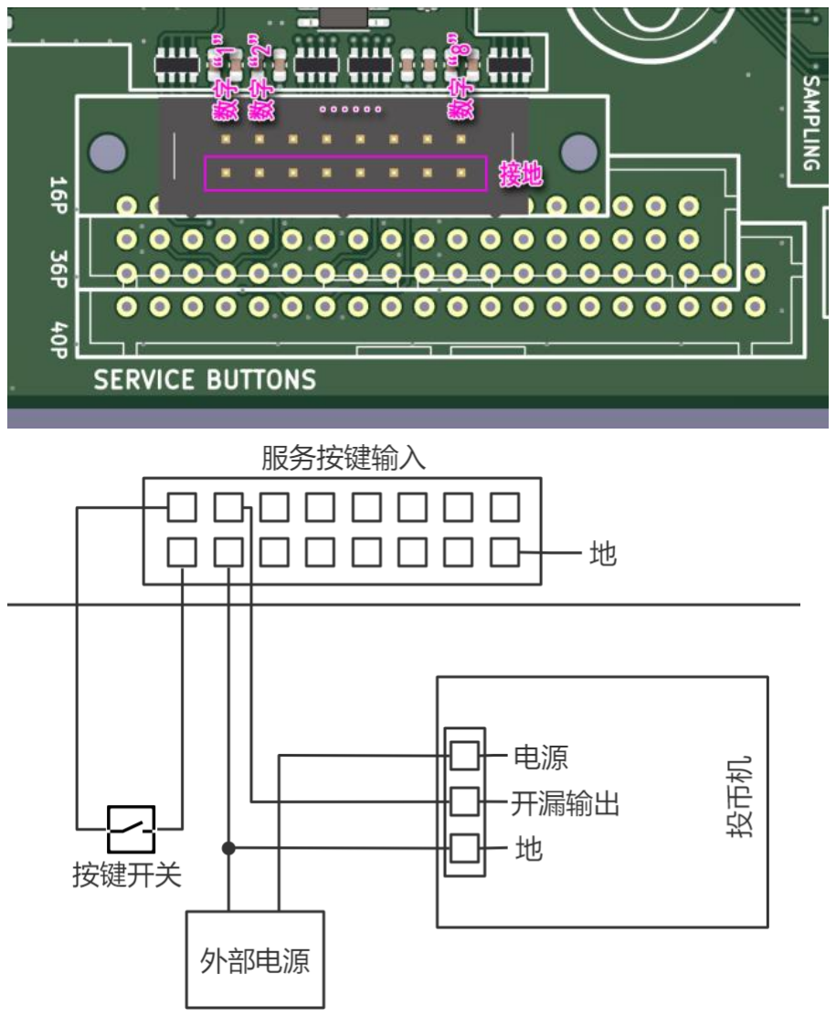
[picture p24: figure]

服务按键指的是 投币、进入设置、上下导航键等按键。

### 3. 连接电脑

准备 USB-A to USB-C 线，连接电脑；
连接电脑后，FND 闪烁，POW、USB 长亮。

设置

### 1. 软件界面


- A-鼓传感器通道顺序配置
- B-输入配置-触发阈值（硬件上做了触发，软件配置这里没有很明显的效果）
- C-输入配置-倍率（当某一路传感器异常灵敏或不灵敏时配置这里，C 为复位）
- D-输出时间配置，H 为按下保持时间，L 为松开保持时间，保持时间内不响应其他输入
- E-屏蔽配置（用于计算鼓的物理结构带来的串音影响）
- F-屏蔽配置-单次响应（选择后每次只会触发一个传感器）
- G-屏蔽配置-计算回合数（设置为 0 时不计算，直接按照速度最快触发）
- H-一些默认参数（大力鼓和街机鼓）
- I-串口选择
- J-选择上载板上的参数组
- K-上载参数键
- L-下载参数键（这一步不会存储，复位单片机会丢失数据）
- M-保存参数键
- N-软件状态

### 2. 配置流程

- 1 选择串口，点击上载后，显示状态为`Success`（用于判断是否连接成功）
- 2 根据需求重置预设参数，或上载旧的参数
- 需要在旧参数的基础上修改的，选择`Load Saved`，再按上载参数键
- 需要在默认配置基础上修改的，直接点按需要的默认配置按钮（两种默认配置只有鼓 的映射不同）
- 修改后，点击下载参数键后，在鼓上确认参数是否合理
- 点击保存参数键

### 3. 其他说明

- 使用单鼓硬件时，第二套鼓的参数无意义
- 默认配置可能会存在问题，可以在默认参数的基础上进行微调以适应你的鼓
- 鼓的传感器线顺序可以通过本上位机进行重映射
- IO 参数大多已经确定，开始配置前先调用默认配置，之后只需要配置传感器输入重映射即 可。

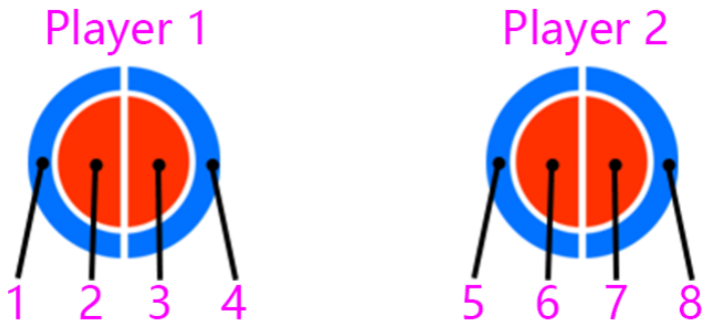
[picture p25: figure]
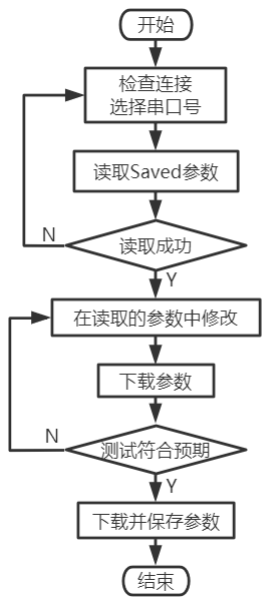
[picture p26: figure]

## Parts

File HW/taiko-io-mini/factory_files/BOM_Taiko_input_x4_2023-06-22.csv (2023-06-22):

ID | Name | Designator | Footprint | Quantity | Manufacturer Part | Manufacturer | Supplier | Supplier Part | Price
1 | 1k | R31,R32,R33,R34,R39,R40,R41,R42,R29,R30 | R0402 | 10
2 | BAT54SWFILM | D1,D8,D2,D7 | SOT-23-3_L2.9-W1.3-P1.90-LS2.4-BR | 4 | BAT54SWFILM | STMicroelectronics | LCSC | C472583 | 0.5158
3 | 10k | R27,R11,R12,R25,R26 | R0402 | 5
4 | NC | R28 | R0603 | 1
5 | 0.01u | C7,C8,C9,C10 | R0402 | 4
6 | 100nF | C31,C30,C33,C34,C35 | R0402 | 5
7 | K2-1109DE-C4SW-01 | SW1,SW2,SW3,SW4 | KEY-TH_K2-1109DE-CXXW-XX | 4 | K2-1109DE-C4SW-01 | HRO | LCSC | C136732 | 0.552
8 | 1N4148WS T4 | D3,D5,D10,D12,D4,D6,D9,D11 | SOD-523F_L1.2-W0.8-LS1.7-RD | 8 | 1N4148WS T4 | CJ | LCSC | C2128 | 0.0661
9 | LED-0603_R | LED1,LED2 | LED0603_RED | 2 | 19-217/R6C-AL1M2VY/3T | EVERLIGHT(台湾亿光) | LCSC | C72044 | 0.1041
10 | 47 | R7,R8,R21,R22 | R0402 | 4
11 | 222 | C1,C2,C15,C16 | R0402 | 4
12 | 100nF | C3,C4,C18,C20 | R0402 | 4 | 06035C104J4Z2A | AVX | LCSC | C597193 | 0.4363
13 | 4.7u | C5,C6,C26,C27,C28 | C0603 | 5
14 | 22u | C17,C19,C29 | C0603 | 3
15 | 10u | C22,C23 | C0603 | 2
16 | 0.1u | C24,C25 | R0402 | 2
17 | 1u | C32 | R0402 | 1
18 | 1M | R1,R2,R15,R16 | R0402 | 4
19 | 3K3 | R3,R4,R17,R18 | R0402 | 4
20 | 200K | R5,R6,R19,R20 | R0402 | 4
21 | 4.7k | R9,R10,R23,R24 | R0402 | 4
22 | 5.1k | R13,R14 | R0402 | 2
23 | TL084CN | U1,U2 | TSSOP-14_L5.0-W4.4-P0.65-LS6.4-TL | 2 | STMicroelectronics | TL084CN | LCSC | C5163 | 1.82
24 | XC6206P332MR | U3 | SOT-23-3_L2.9-W1.6-P1.90-LS2.8-BR | 1 | XC6206P332MR | TOREX | LCSC | C5446 | 0.6654
25 | SGM3204YN6G/TR | U4 | SOT-23-6_L2.9-W1.6-P0.95-LS2.8-BR | 1 | SGM3204YN6G/TR | SG Micro | LCSC | C194031 | 5.96
26 | STM32G030F6P6 | U5 | TSSOP-20_L6.5-W4.4-P0.65-LS6.4-BL | 1 | STM32G030F6P6 | STMicroelectronics | LCSC | C724040 | 3.18
27 | CH552T | U6 | TSSOP-20_L6.5-W4.4-P0.65-LS6.4-BL | 1 | CH552T | WCH | LCSC | C111367 | 3.6
28 | HDR-IDC-2.54-2X4P | P1 | IDC 8P | 1 | HDR-IDC-2.54-2X4P | EasyEDA | EasyEDA | E9135
29 | TYPE-C16PIN | USB1 | USB-C-SMD_TYPE-C16PIN | 1 | TYPE-C16PIN | SHOU HAN | LCSC | C393939 | 1.3293

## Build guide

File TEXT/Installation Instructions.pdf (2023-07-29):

# Installation Instructions

### 1. Installation dimensions and wiring:

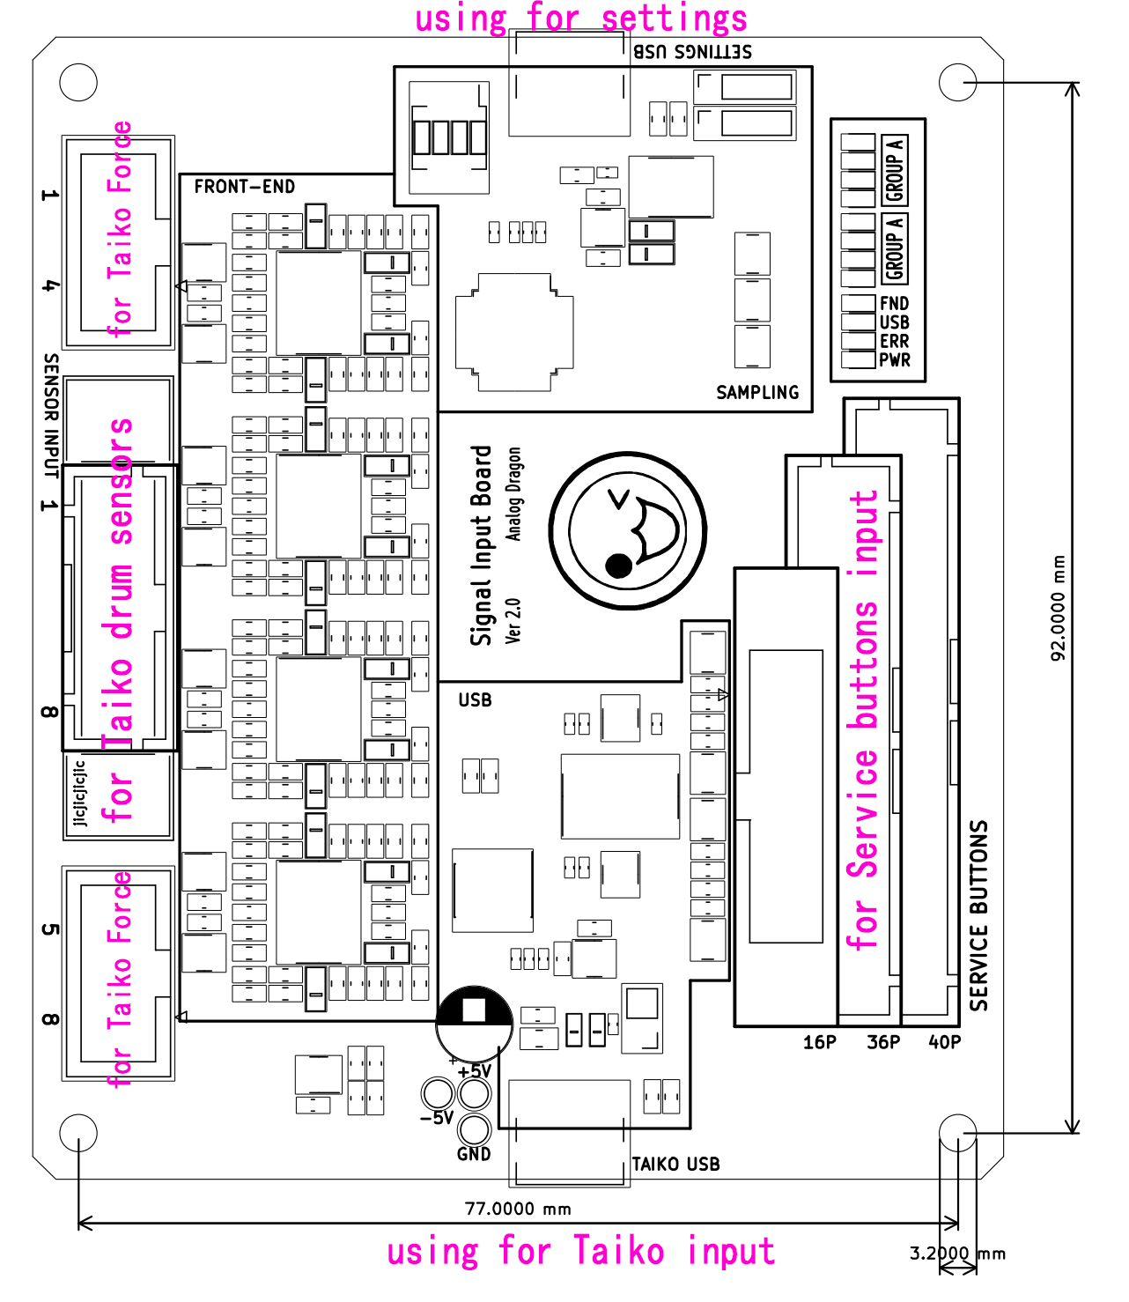
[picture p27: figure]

Drum connection:

Connection of the drums:
1. For Taiko Force: For personal use, you can directly plug the large drum cable into the Taiko Force port.
2. For arcade drums: Connect the drum cable, which is connected to the amplifier board, to the arcade drum interface. You can solder either an IDC-16P connector or a B16B-XADSS-N connector to ensure compatibility with different arcade.
Regardless of the type of Taiko, it is necessary to configure the input channel before using it.

Connection of the service panel:

1. For personal use: Usually, there is no need to install this interface. If you require a control panel, you will need to specifically prepare a button board.
2. For arcade use: For 12th, you need to solder a 36P connector (B36B-XADSS-N); for Newer, you need to solder a 40P connector (B40B-XADSS-N). If you are using a DIY adapter cable, solder a 16P IDC connector. After connecting the connector, you need to set the button mapping in the program to ensure that numbers 1 to 8 are mapped to the correct functions.

### 2. Installation precautions

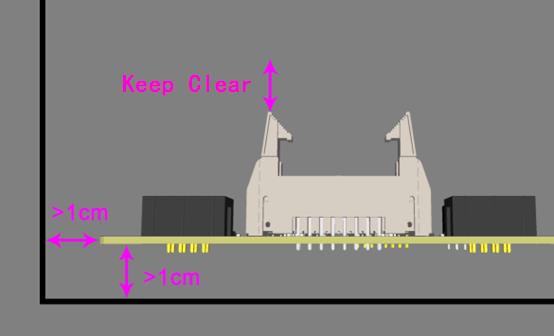
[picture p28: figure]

Pay attention to the direction of the wiring and ensure sufficient clearance, following the requirements shown in the diagram as much as possible.

When installing, do not touch the components on the board with your hands or tools.

If there are no installation conditions available, you can use a cardboard box for protection. (Use an appropriately sized box, create a hole at the corresponding outlet position, extend the cables out, and close the box cover.)

A certain temperature increase during operation is normal, but do not touch it with your hands.

### 3. Precautions for the Taiko Force interface


This interface is not a firm one, so strict attention should be paid to cable stress after installation.

After the cable is installed, it needs to be prevented from shaking. The shaking angle should not exceed ±5°. Prolonged shaking will reduce the interface's lifespan. The direction of the outlet should not be too skewed to reduce the force the cable exerts on the IO board.

You can use a Taiko Force adapter board to alleviate the stress on the cable.

# User Manual

## User Manual

When connected to a computer, the device will be recognized as an HID Keyboard and can be used for keyboard simulation input.

Drum input is mapped to the keys: DFJK-ZXCV. And the service buttons are mapped to the number 1 to 8 on the keyboard.

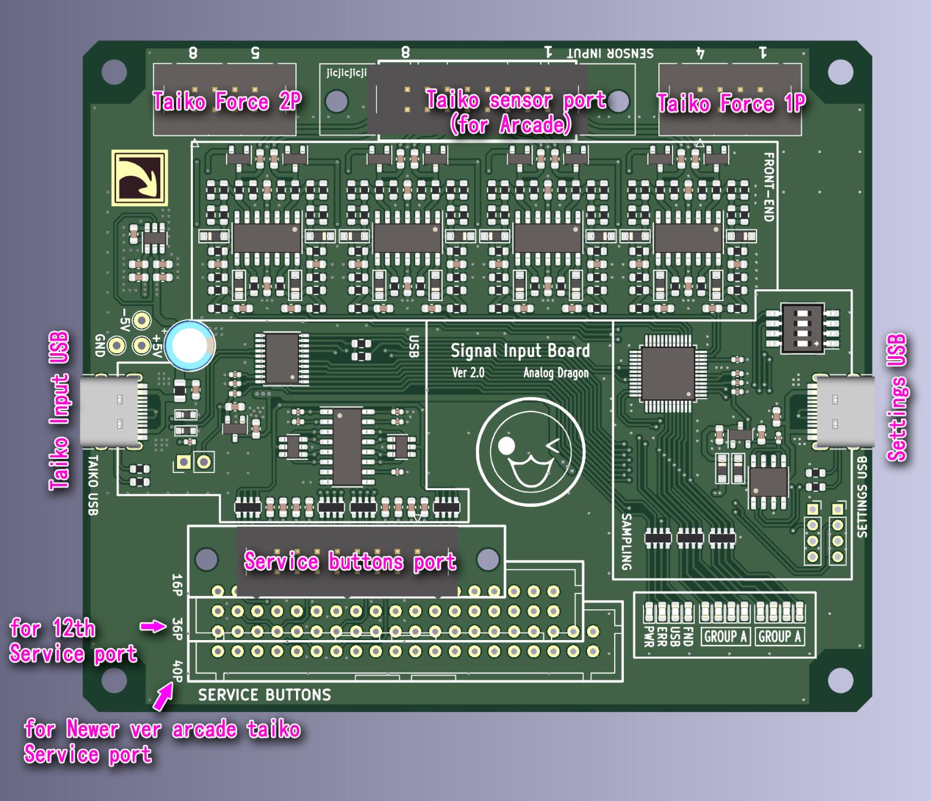
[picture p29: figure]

### 1. Connect to sensor (Taiko)

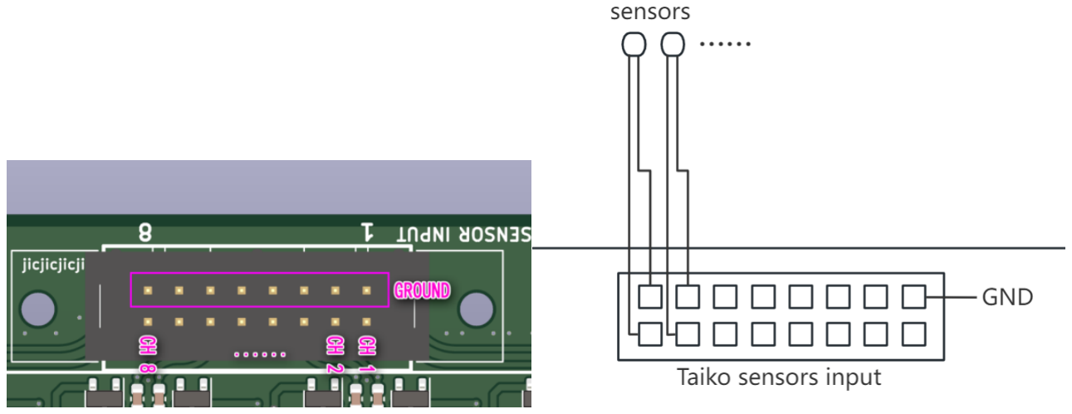
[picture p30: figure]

The sensor interface is used to connect the Taiko. The ground terminal should be connected to the shield layer or negative terminal of each sensor. CH1~CH8 should be connected to the sensor outputs or positive terminals.

### 2. Connect to Service Buttons

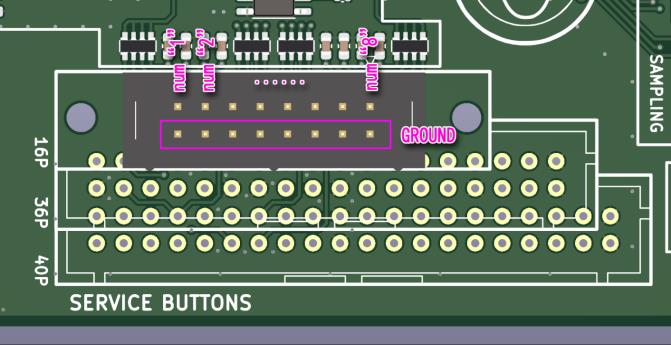
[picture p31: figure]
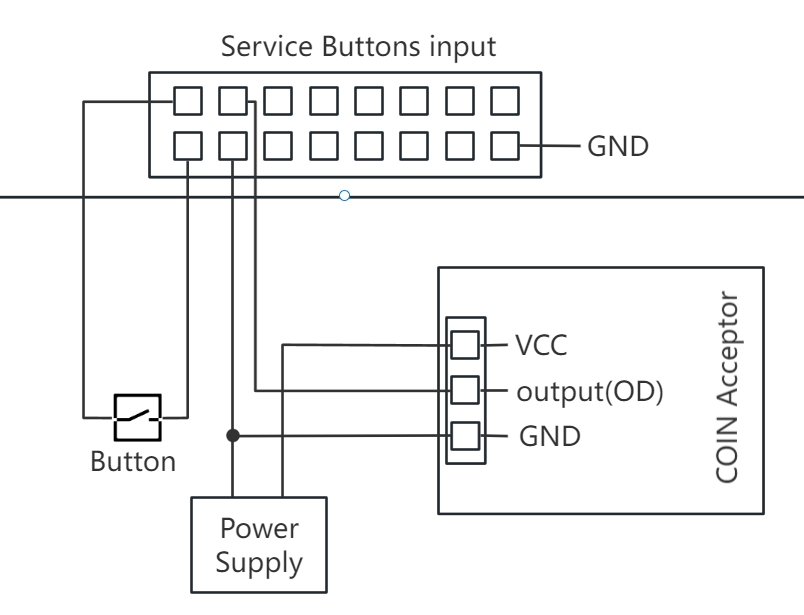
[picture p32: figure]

Service buttons means ”coin”, “test”, “service”, “up” and “down” buttons in arcade.

### 3. Connecting to your computer:

Prepare a USB-A to USB-C cable and connect it to your computer.

Once connected, the FND led will flash, the POW and USB led will keep bright.

## Settings

### 1. Software Interface


- A-Taiko sensor channel sequence configuration
- B-Input configuration-Trigger threshold (triggering is done in hardware, no obvious effect in software configuration)
- C-Input configuration-Multiplication factor (configure this when a certain sensor is exceptionally sensitive or insensitive, C for reset)
- D-Output time configuration, H for hold time when pressing, L for hold time when releasing, no response to other inputs during hold time
- E-Shielding configuration (used to calculate crosstalk caused by the physical structure of the taiko)
- F-Shielding configuration-Single response (selecting this will trigger only one sensor each time)
- G-Shielding configuration-Calculate rounds (set to 0 to disable calculation, directly trigger according to the fastest speed)
- H-Some default parameters (for Taiko Force and arcade taiko)
- I-Serial port selection

- J-Select the parameter group on the upload board
- K-Upload parameter button
- L-Download parameter button (this step does not store data, data will be lost when the microcontroller is reset)
- M-Save parameter button
- N-Software status

### 2. Configuration Process

- 1 Select the serial port, click upload, and the status will be displayed as `Success` (used to determine if the connection is successful)
- 2 Reset the preset parameters according to your needs or upload old parameters
- For modifications based on the old parameters, select `Load Saved`, and then press the upload parameter button
- For modifications based on the default configuration, click the desired default configuration button (the two default configurations only differ in taiko mapping)
- 3 After making modifications, click the download parameter button and confirm if the parameters are reasonable on the taiko
- 4 Click the save parameter button

### 3. Other Instructions

- When using single taiko hardware, the parameters for the second taiko are meaningless
- Default configurations may have issues; you can make fine adjustments based on the default parameters to suit your taiko
- The sensor wire sequence of the taiko can be remapped through this APP.
- Most of the IO parameters are already determined, It is recommended to first apply the default configuration before proceeding with the sensor input remapping. And then, you only need to configure the remapping of the sensor inputs.

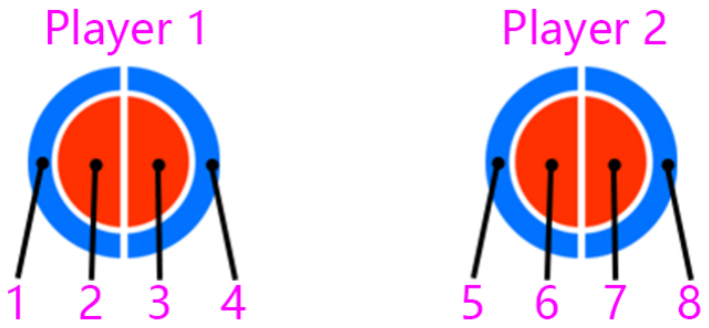
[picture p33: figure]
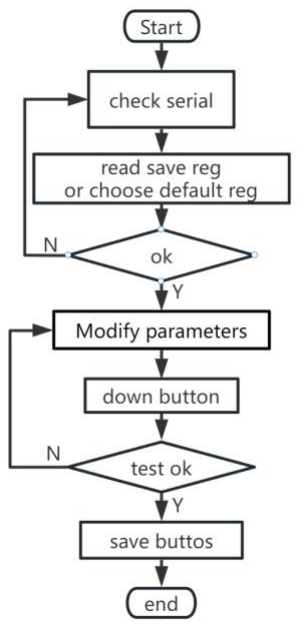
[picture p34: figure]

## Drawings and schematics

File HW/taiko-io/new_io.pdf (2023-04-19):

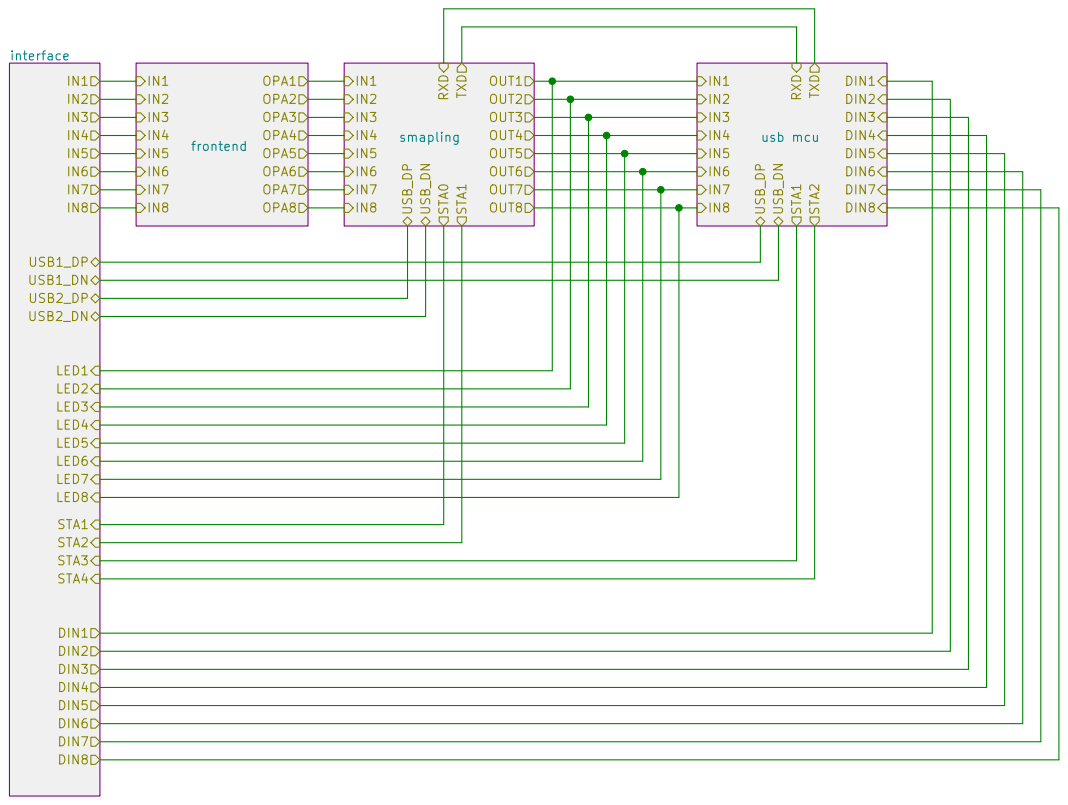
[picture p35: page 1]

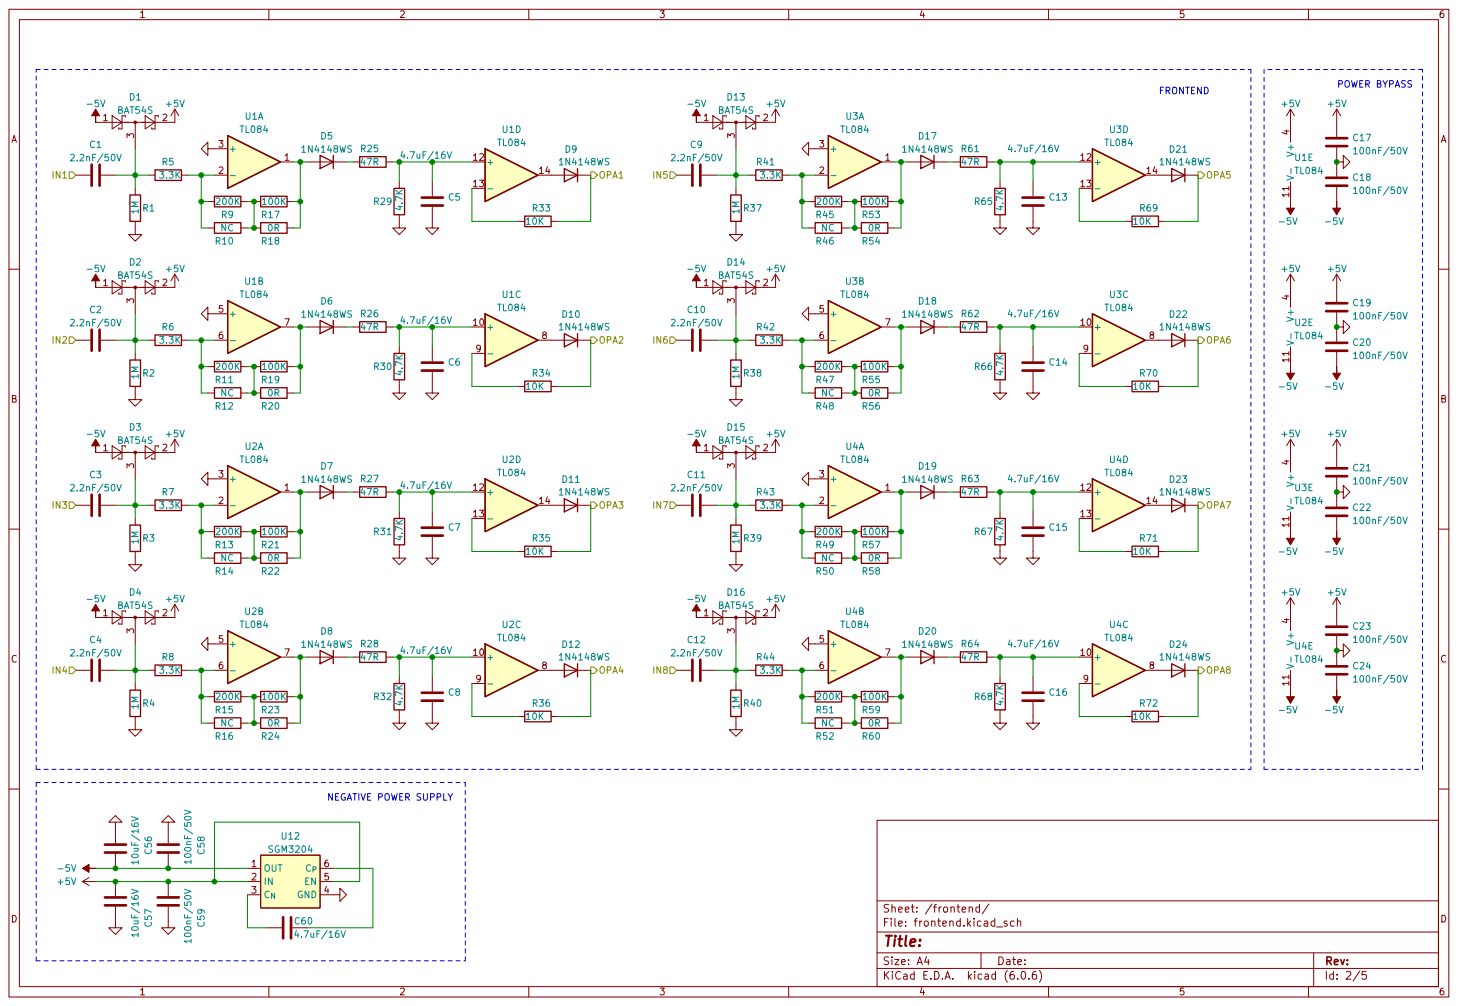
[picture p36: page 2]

File: frontend.kicad_sch Sheet: /frontend/
Id: 2/5 Title:

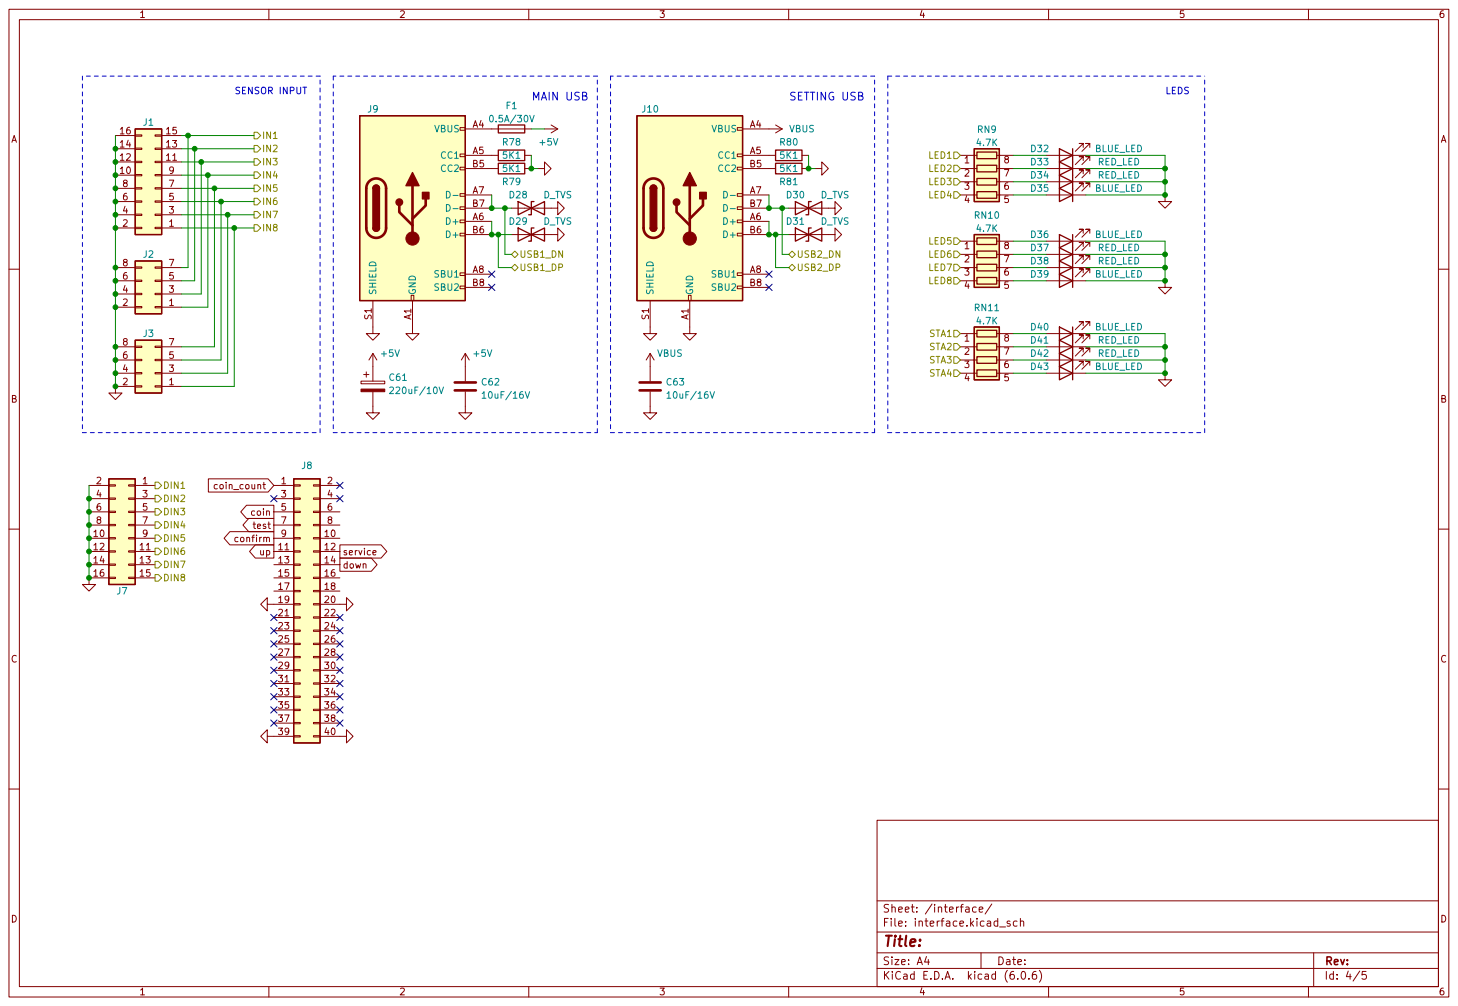
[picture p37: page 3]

D33 | RED_LED
7 D34 | RED_LED

D37 | RED_LED
7 D38 | RED_LED

File: interface.kicad_sch Sheet: /interface/
Id: 4/5 Title:

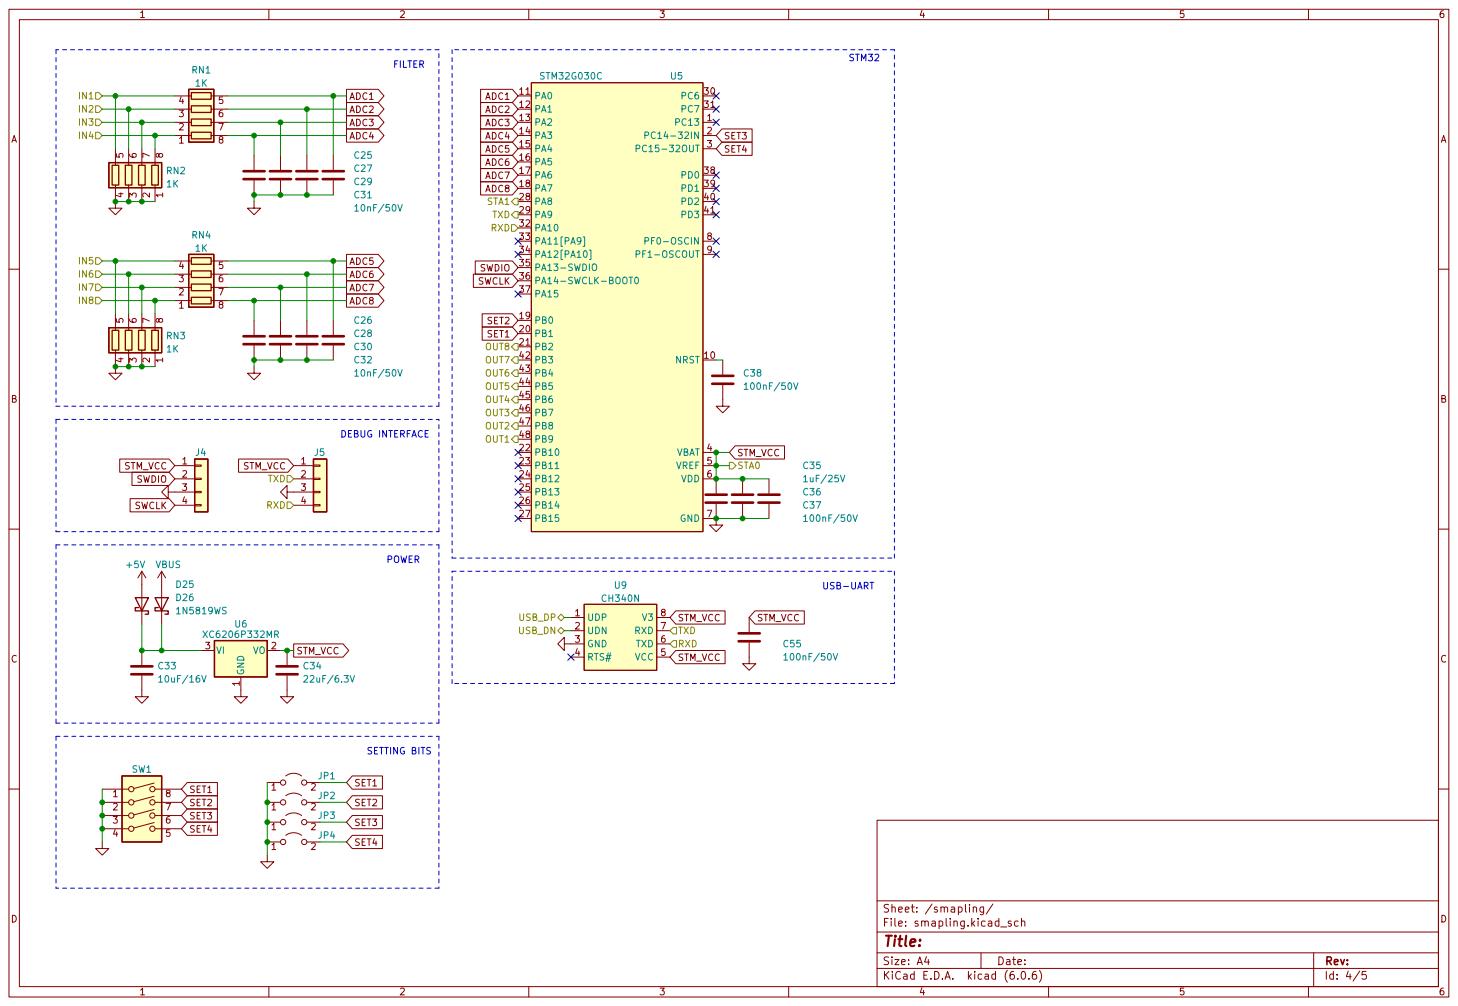
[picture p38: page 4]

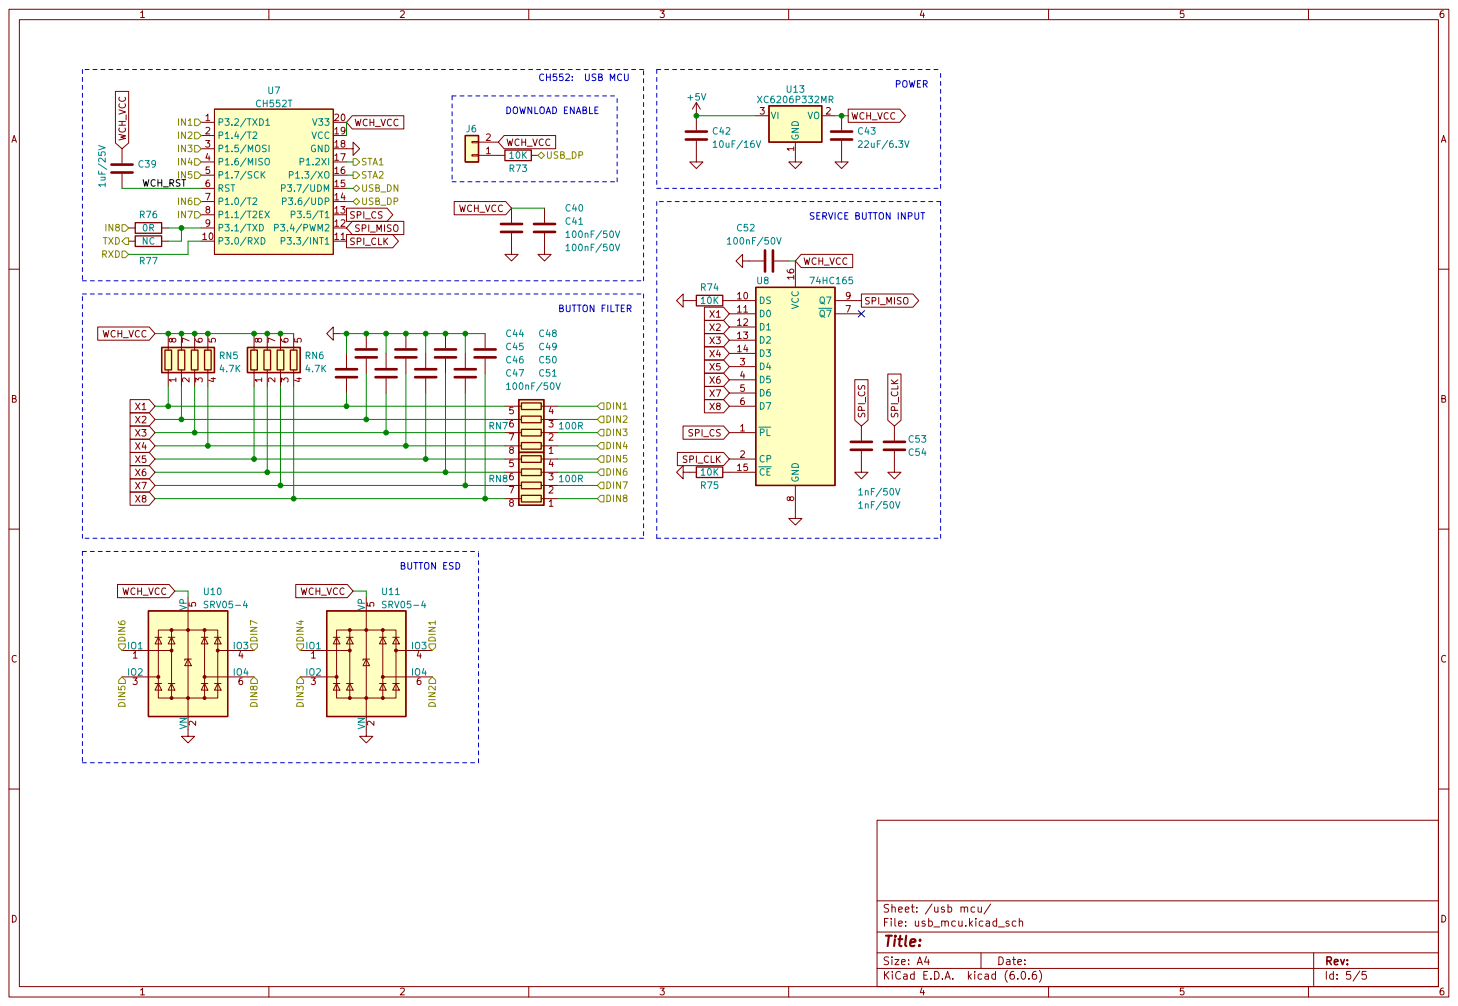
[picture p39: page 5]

SERVICE BUTTON INPUT BUTTON ESD

File: usb_mcu.kicad_sch Sheet: /usb mcu/
Id: 5/5 Title:

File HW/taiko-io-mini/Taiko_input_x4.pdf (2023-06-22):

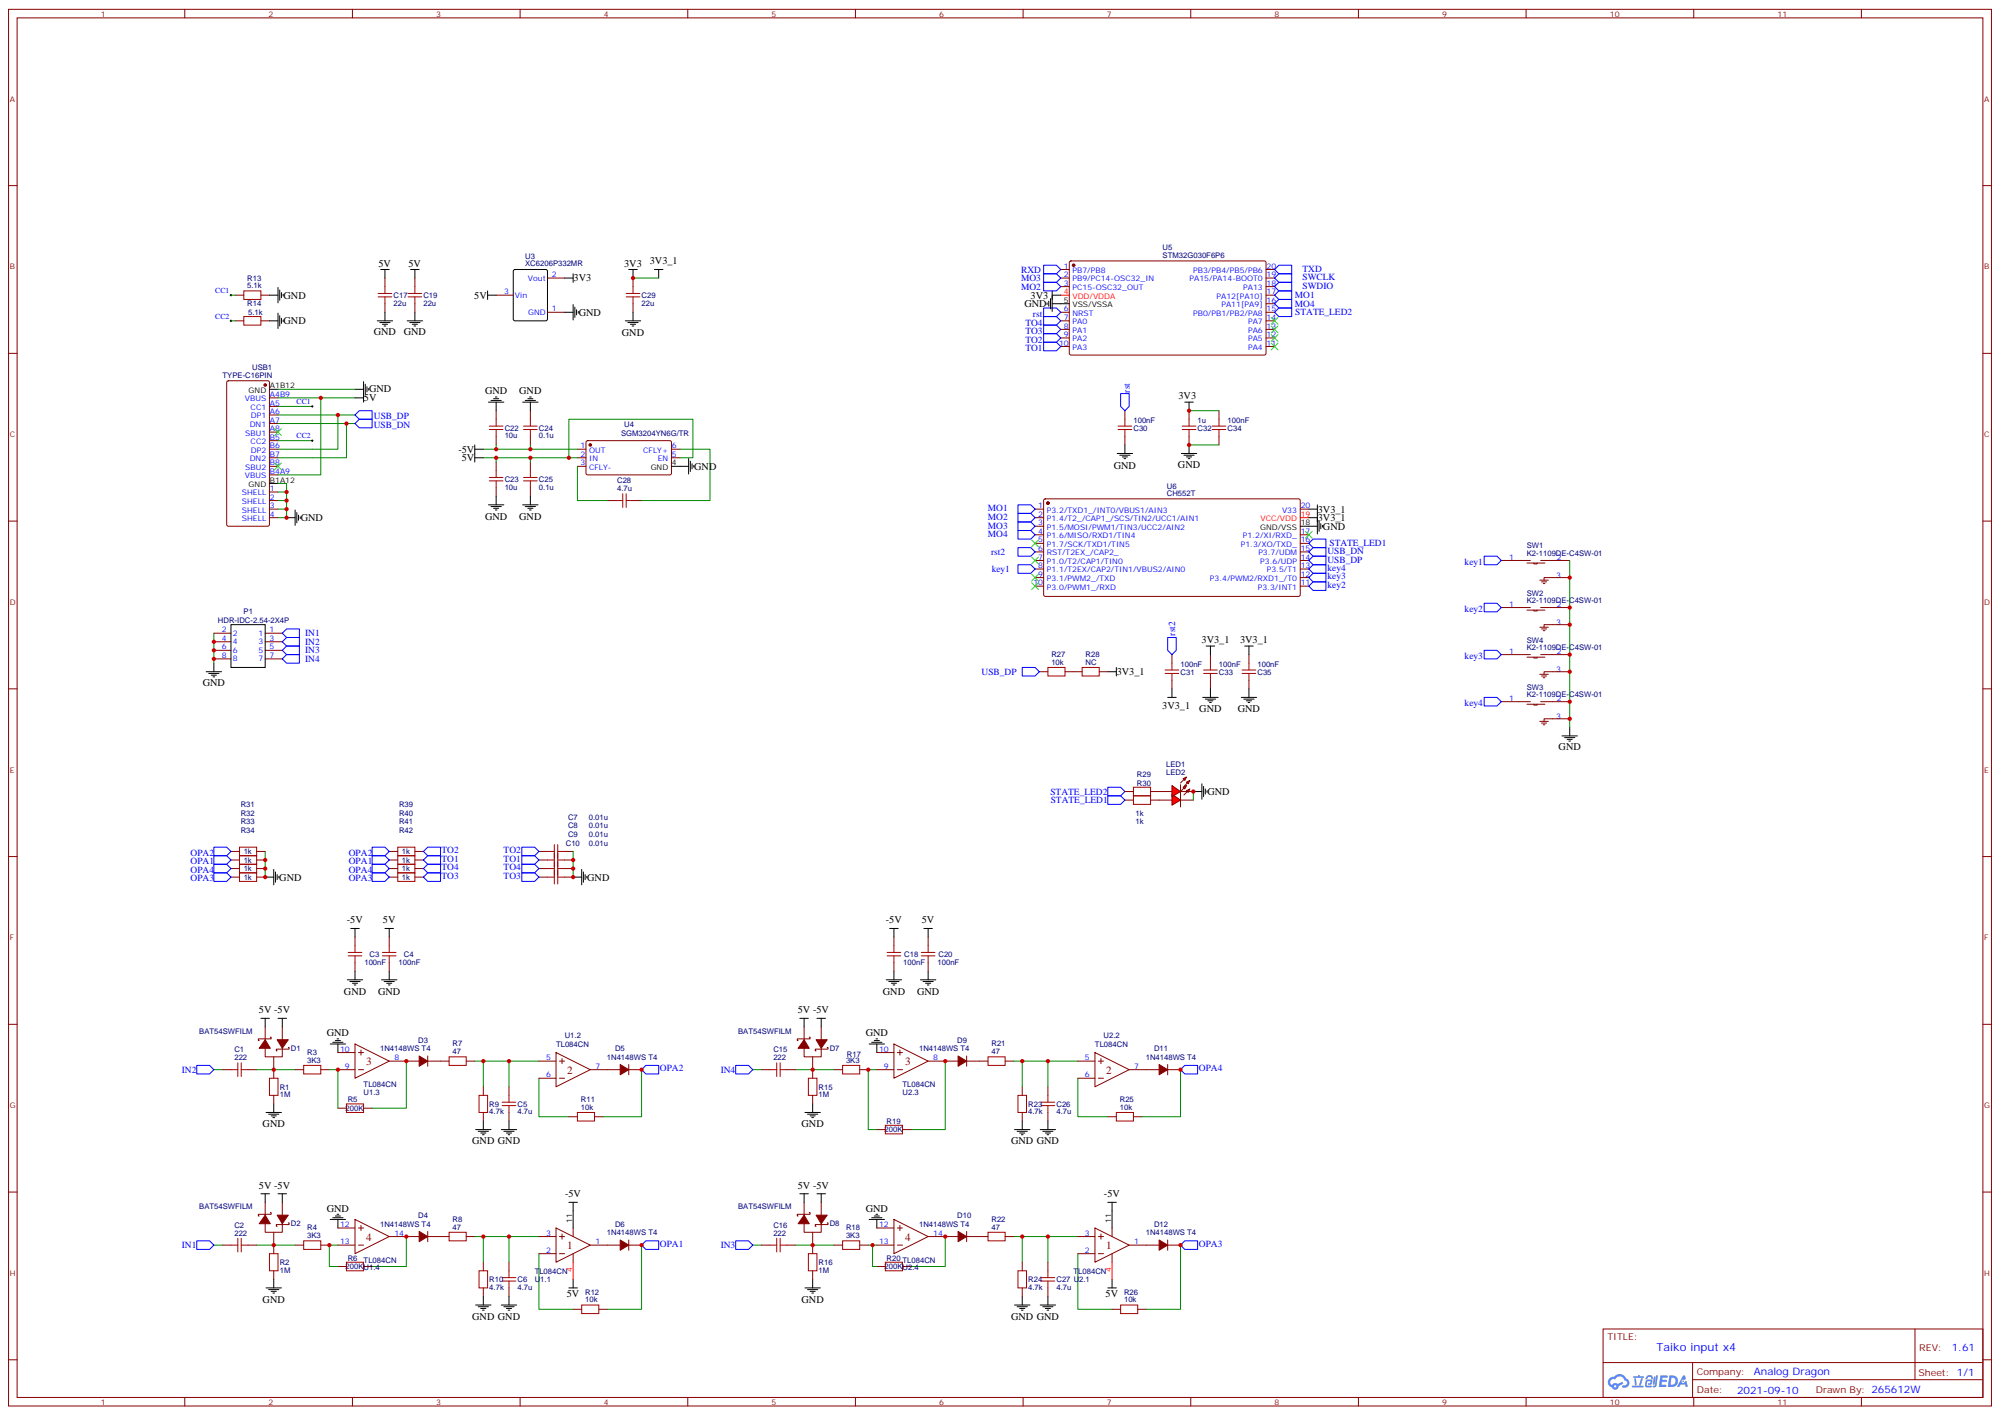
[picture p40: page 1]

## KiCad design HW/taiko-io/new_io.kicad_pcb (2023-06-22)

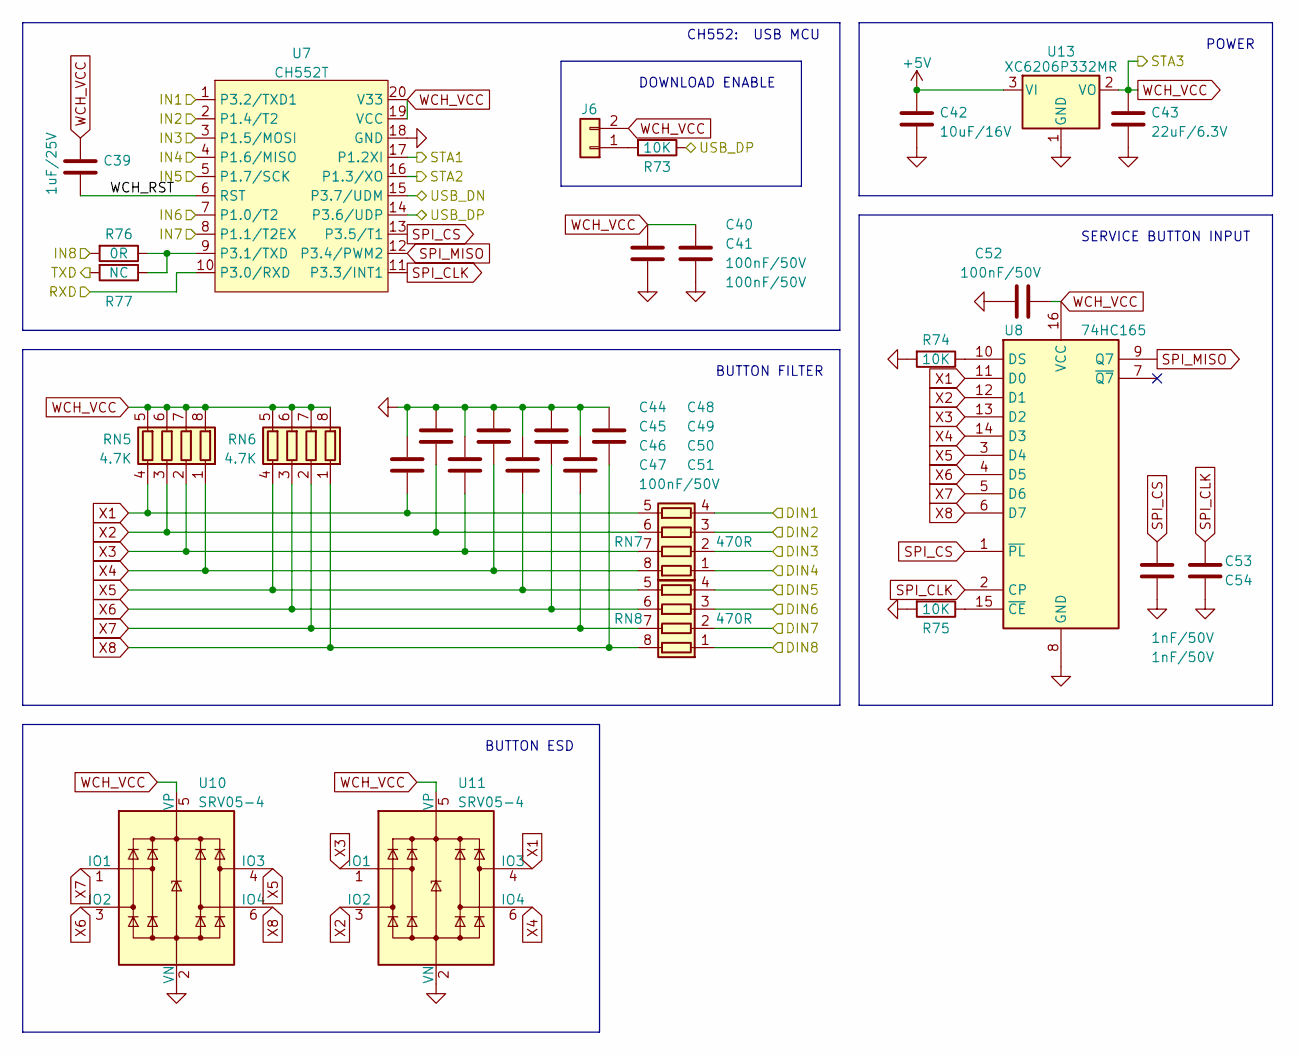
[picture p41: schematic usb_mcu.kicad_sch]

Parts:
C39: 1uF/25V; C_0402_1005Metric
C40, C41, C52: 100nF/50V; C_0402_1005Metric
C42: 10uF/16V; C_0603_1608Metric
C43: 22uF/6.3V; C_0603_1608Metric
C44, C45, C46, C47, C48, C49, C50, C51: 100nF/50V; C_0603_1608Metric
C53, C54: 1nF/50V; C_0402_1005Metric
J6: Conn_01x02; PinHeader_1x02_P2.54mm_Vertical
R73, R74, R75: 10K; C_0402_1005Metric
R76: 0R; R_0603_1608Metric
R77: NC; R_0603_1608Metric
RN5, RN6: 4.7K; R_Array_Convex_4x0603
RN7, RN8: 470R; R_Array_Convex_4x0603
U7: CH552T; SSOP-20_4.4x6.5mm_P0.65mm
U8: 74HC165; SOIC-16_3.9x9.9mm_P1.27mm
U10, U11: SRV05-4; SOT-23-6
U13: XC6206P332MR; SOT-23

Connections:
+5V: C42.1, U13.3 (VI); also elsewhere on the board
/interface/DIN1: RN7.4 (R4.1); also elsewhere on the board
/interface/DIN8: RN8.1 (R1.1); also elsewhere on the board
/interface/LED1: U7.1 (P3.2/TXD1); also elsewhere on the board
/interface/LED2: U7.2 (P1.4/T2); also elsewhere on the board
/interface/LED3: U7.3 (P1.5/MOSI); also elsewhere on the board
/interface/LED4: U7.4 (P1.6/MISO); also elsewhere on the board
/interface/LED5: U7.5 (P1.7/SCK); also elsewhere on the board
/interface/LED6: U7.7 (P1.0/T2); also elsewhere on the board
/interface/LED7: U7.8 (P1.1/T2EX); also elsewhere on the board
/interface/LED8: R76.2; also elsewhere on the board
/interface/STA2: U7.17 (P1.2XI); also elsewhere on the board
/interface/STA3: U7.16 (P1.3/XO); also elsewhere on the board
/interface/USB1_DN: U7.15 (P3.7/UDM); also elsewhere on the board
/interface/USB1_DP: R73.1, U7.14 (P3.6/UDP); also elsewhere on the board
/smapling/RXD: R77.2; also elsewhere on the board
/smapling/TXD: U7.10 (P3.0/RXD); also elsewhere on the board
/usb mcu/WCH_RST: C39.2, U7.6 (RST)
unnamed: J6.1, R73.2
unnamed: R76.1, R77.1, U7.9 (P3.1/TXD)
unnamed: R74.1, U8.10 (DS)
unnamed: R75.1, U8.15 (~CE)
SPI_CLK: C54.2, U7.11 (P3.3/INT1), U8.2 (CP)
SPI_CS: C53.2, U7.13 (P3.5/T1), U8.1 (~PL)
SPI_MISO: U7.12 (P3.4/PWM2), U8.9 (Q7)
WCH_VCC: C39.1, C40.1, C41.1, C43.1, C52.2, J6.2, RN5.5 (R4.2), RN5.6 (R3.2), RN5.7 (R2.2), RN5.8 (R1.2), RN6.5 (R4.2), RN6.6 (R3.2), RN6.7 (R2.2), RN6.8 (R1.2), U7.19 (VCC), U7.20 (V33), U8.16 (VCC), U10.5 (VP), U11.5 (VP), U13.2 (VO); also elsewhere on the board
X1: C44.2, RN5.4 (R4.1), RN7.5 (R4.2), U8.11 (D0), U11.4 (IO3)
X2: C45.2, RN5.3 (R3.1), RN7.6 (R3.2), U8.12 (D1), U11.3 (IO2)
X3: C46.2, RN5.2 (R2.1), RN7.7 (R2.2), U8.13 (D2), U11.1 (IO1)
X4: C47.2, RN5.1 (R1.1), RN7.8 (R1.2), U8.14 (D3), U11.6 (IO4)
X5: C48.2, RN6.4 (R4.1), RN8.5 (R4.2), U8.3 (D4), U10.4 (IO3)
X6: C49.2, RN6.3 (R3.1), RN8.6 (R3.2), U8.4 (D5), U10.3 (IO2)
X7: C50.2, RN6.2 (R2.1), RN8.7 (R2.2), U8.5 (D6), U10.1 (IO1)
X8: C51.2, RN6.1 (R1.1), RN8.8 (R1.2), U8.6 (D7), U10.6 (IO4)
coin: RN8.2 (R2.1); also elsewhere on the board
down: RN7.3 (R3.1); also elsewhere on the board
enter: RN8.4 (R4.1); also elsewhere on the board
service: RN7.1 (R1.1); also elsewhere on the board
test: RN8.3 (R3.1); also elsewhere on the board
up: RN7.2 (R2.1); also elsewhere on the board

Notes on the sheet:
SERVICE BUTTON INPUT
DOWNLOAD ENABLE
BUTTON FILTER
POWER
BUTTON ESD
CH552: USB MCU

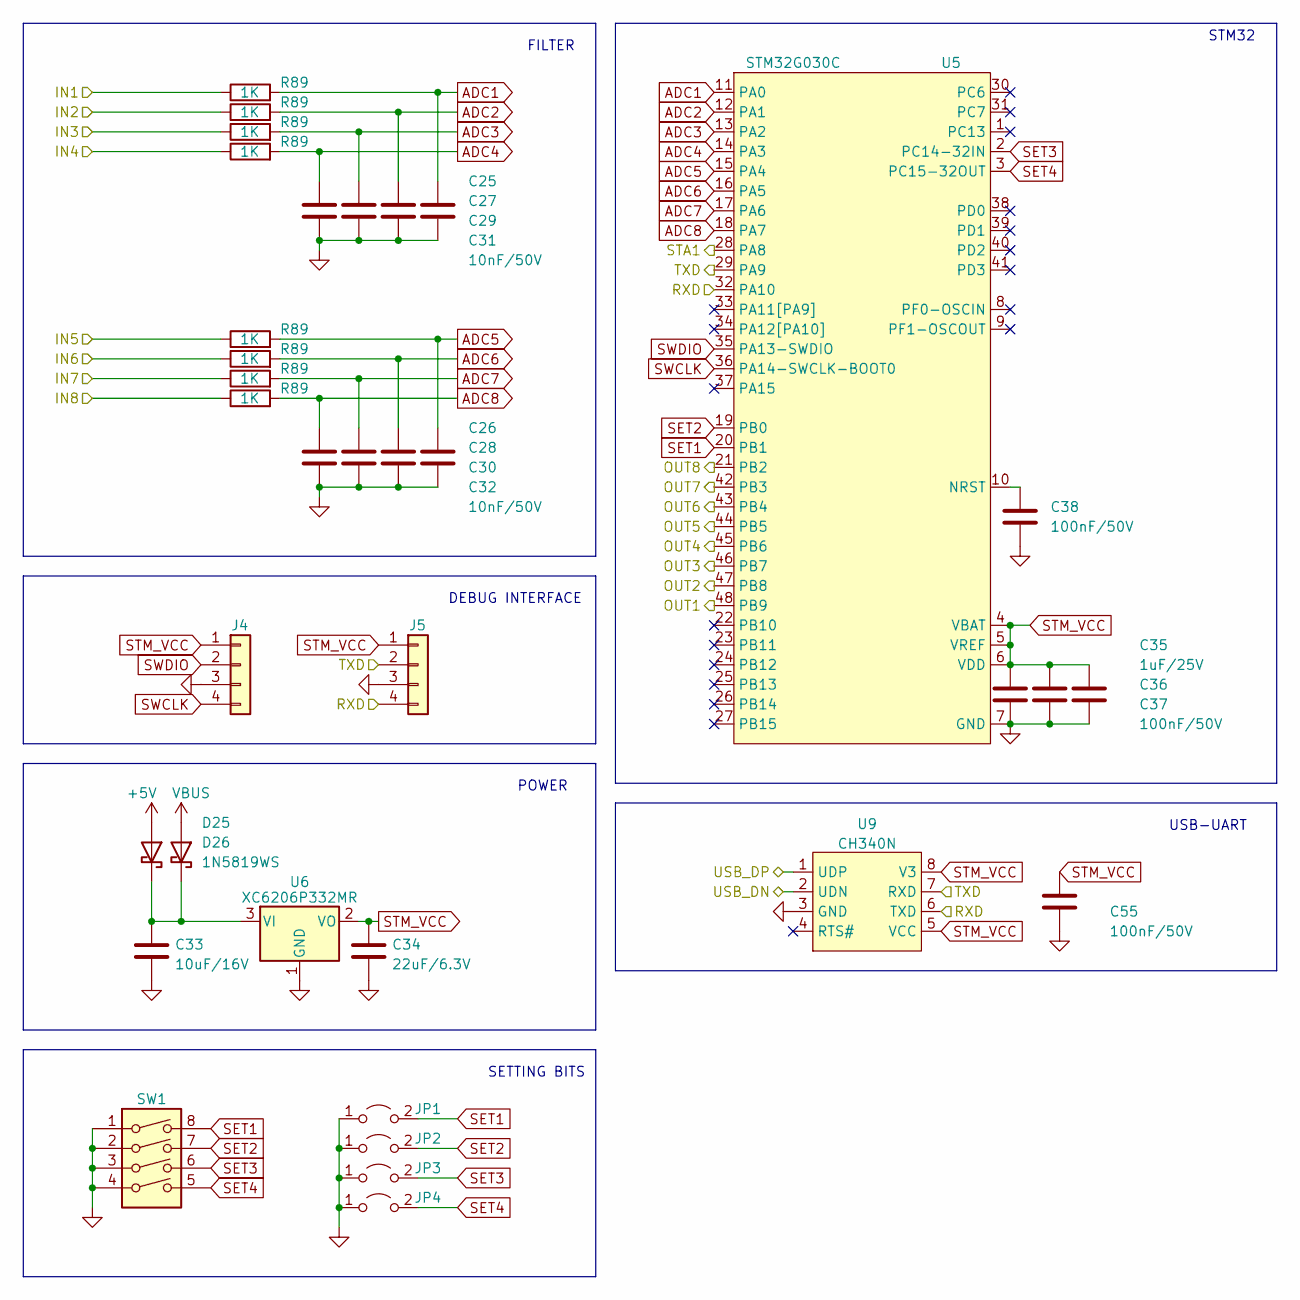
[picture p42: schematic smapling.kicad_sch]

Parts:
C25, C26, C27, C28, C29, C30, C31, C32: 10nF/50V; C_0603_1608Metric
C33: 10uF/16V; C_0603_1608Metric
C34: 22uF/6.3V; C_0603_1608Metric
C35: 1uF/25V; C_0402_1005Metric
C36, C37, C38, C55: 100nF/50V; C_0402_1005Metric
D25, D26: 1N5819WS; SOD_323_1
J4, J5: Conn_01x04; PinSocket_1x04_P2.00mm_Vertical
JP1, JP2, JP3, JP4: Jumper_2_Open; JP_0603
R89: 1K; R_0603_1608Metric
SW1: SW_DIP_x04; SW_DIP_SPSTx04_Slide_Copal_CHS-04B_W7.62mm_P1.27mm
U5: STM32G030C; LQFP-48_7x7mm_P0.5mm
U6: XC6206P332MR; SOT-23
U9: CH340N; SOIC-8_3.9x4.9mm_P1.27mm

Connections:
+5V: D25.2 (A); also elsewhere on the board
/frontend/OPA8: R89.1; also elsewhere on the board
/interface/LED1: U5.48 (PB9); also elsewhere on the board
/interface/LED2: U5.47 (PB8); also elsewhere on the board
/interface/LED3: U5.46 (PB7); also elsewhere on the board
/interface/LED4: U5.45 (PB6); also elsewhere on the board
/interface/LED5: U5.44 (PB5); also elsewhere on the board
/interface/LED6: U5.43 (PB4); also elsewhere on the board
/interface/LED7: U5.42 (PB3); also elsewhere on the board
/interface/LED8: U5.21 (PB2); also elsewhere on the board
/interface/STA1: U5.28 (PA8); also elsewhere on the board
/interface/USB2_DN: U9.2 (UDN); also elsewhere on the board
/interface/USB2_DP: U9.1 (UDP); also elsewhere on the board
/smapling/RXD: J5.4, U5.32 (PA10), U9.6 (TXD); also elsewhere on the board
/smapling/TXD: J5.2, U5.29 (PA9), U9.7 (RXD); also elsewhere on the board
unnamed: C33.1, D25.1 (K), D26.1 (K), U6.3 (VI)
unnamed: C38.1, U5.10 (NRST)
SET1: JP1.2 (B), SW1.8, U5.20 (PB1)
SET2: JP2.2 (B), SW1.7, U5.19 (PB0)
SET3: JP3.2 (B), SW1.6, U5.2 (PC14-32IN)
SET4: JP4.2 (B), SW1.5, U5.3 (PC15-32OUT)
STM_VCC: C34.1, C35.1, C36.1, C37.1, C55.1, J4.1, J5.1, U5.4 (VBAT), U5.5 (VREF), U5.6 (VDD), U6.2 (VO), U9.5 (VCC), U9.8 (V3)
SWCLK: J4.4, U5.36 (PA14-SWCLK-BOOT0)
SWDIO: J4.2, U5.35 (PA13-SWDIO)
VBUS: D26.2 (A); also elsewhere on the board

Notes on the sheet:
USB-UART
FILTER
SETTING BITS
DEBUG INTERFACE
STM32
POWER

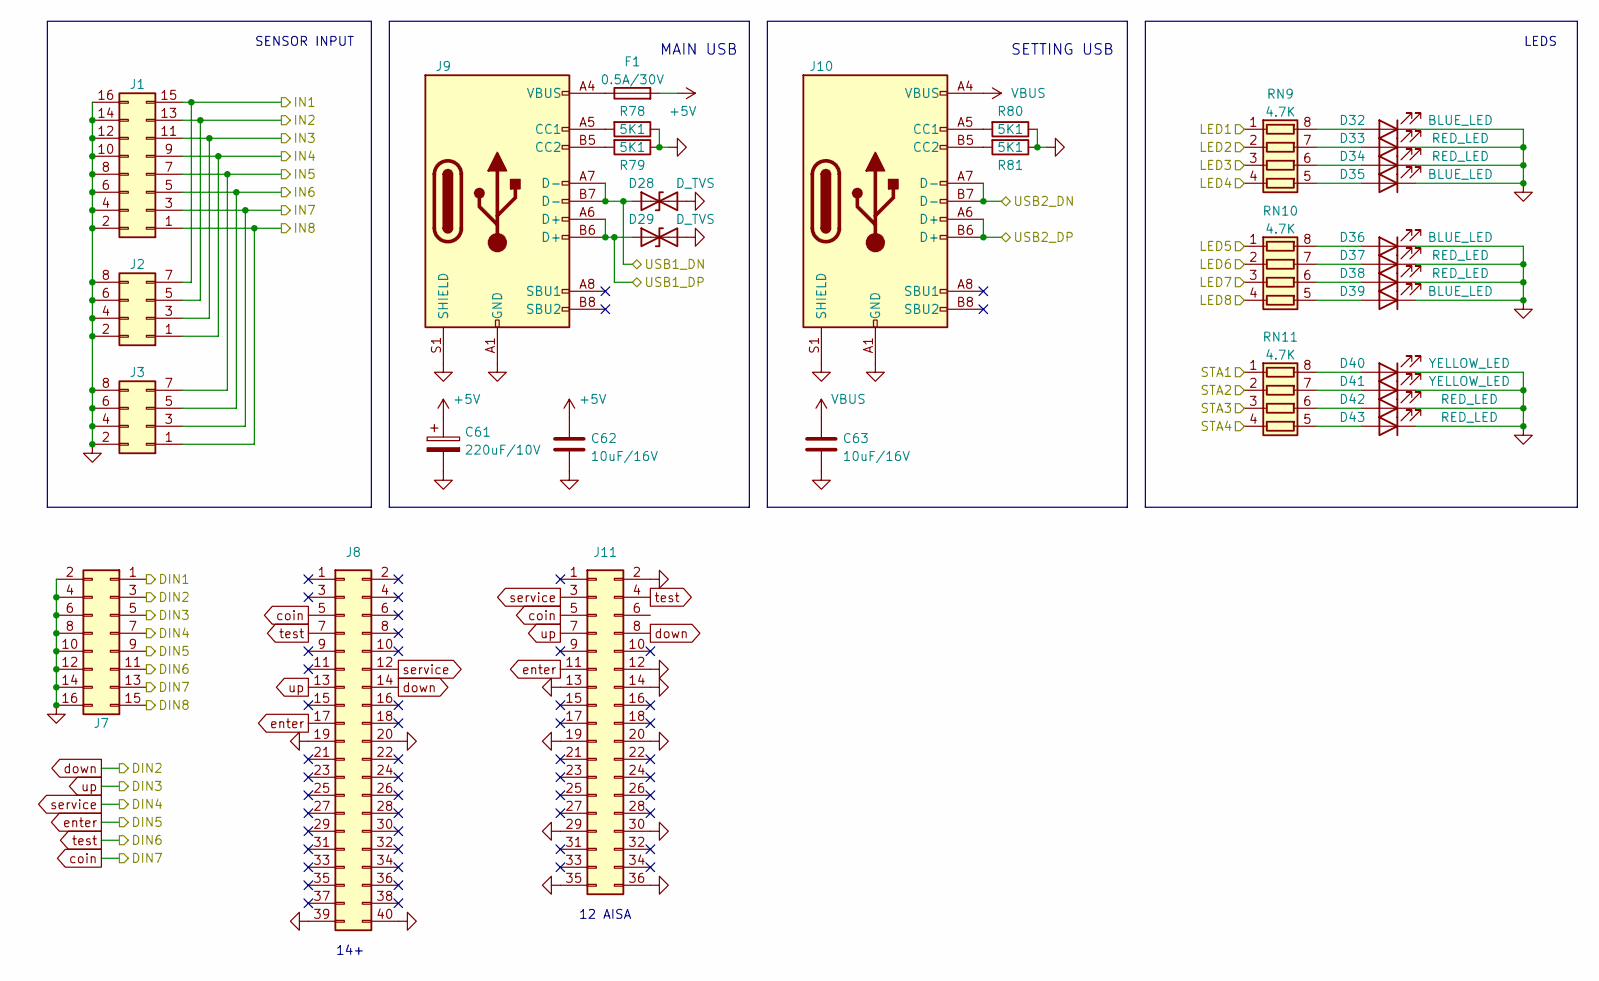
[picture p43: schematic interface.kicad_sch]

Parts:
C61: 220uF/10V; CP_Radial_D6.3mm_P2.50mm
C62, C63: 10uF/16V; C_0603_1608Metric
D28, D29: D_TVS; SOD_523_1
D32, D35, D36, D39: BLUE_LED; LED_0603_1608Metric
D33, D34, D37, D38, D42, D43: RED_LED; LED_0603_1608Metric
D40, D41: YELLOW_LED; LED_0603_1608Metric
F1: 0.5A/30V; Fuse_0805_2012Metric
J1, J7: Conn_02x08_Odd_Even; IDC-Header_2x08-1MP_P2.54mm_Latch6.5mm_Vertical
J2, J3: Conn_02x04_Odd_Even; IDC-Header_2x04_P2.54mm_Vertical
J8: Conn_02x20_Odd_Even; B40B-XADSS-N-A
J9, J10: USB_C_Receptacle_USB2.0; USB_C_Receptacle_HRO_TYPE-C-31-M-12
J11: Conn_02x18_Odd_Even; B36B-XADSS-N-A
R78, R79, R80, R81: 5K1; R_0603_1608Metric
RN9, RN10, RN11: 4.7K; R_Array_Convex_4x0603

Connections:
+5V: C61.1, C62.1, F1.2; also elsewhere on the board
/frontend/IN1: J1.15, J2.7; also elsewhere on the board
/frontend/IN2: J1.13, J2.5; also elsewhere on the board
/frontend/IN3: J1.11, J2.3; also elsewhere on the board
/frontend/IN4: J1.9, J2.1; also elsewhere on the board
/frontend/IN5: J1.7, J3.7; also elsewhere on the board
/frontend/IN6: J1.5, J3.5; also elsewhere on the board
/frontend/IN7: J1.3, J3.3; also elsewhere on the board
/frontend/IN8: J1.1, J3.1; also elsewhere on the board
/interface/DIN1: J7.1; also elsewhere on the board
/interface/DIN8: J7.15; also elsewhere on the board
/interface/LED1: RN9.1 (R1.1); also elsewhere on the board
/interface/LED2: RN9.2 (R2.1); also elsewhere on the board
/interface/LED3: RN9.3 (R3.1); also elsewhere on the board
/interface/LED4: RN9.4 (R4.1); also elsewhere on the board
/interface/LED5: RN10.1 (R1.1); also elsewhere on the board
/interface/LED6: RN10.2 (R2.1); also elsewhere on the board
/interface/LED7: RN10.3 (R3.1); also elsewhere on the board
/interface/LED8: RN10.4 (R4.1); also elsewhere on the board
/interface/STA1: RN11.1 (R1.1); also elsewhere on the board
/interface/STA2: RN11.2 (R2.1); also elsewhere on the board
/interface/STA3: RN11.3 (R3.1); also elsewhere on the board
/interface/USB1_DN: D28.1 (A1), J9.A7 (D-), J9.B7 (D-); also elsewhere on the board
/interface/USB1_DP: D29.1 (A1), J9.A6 (D+), J9.B6 (D+); also elsewhere on the board
/interface/USB2_DN: J10.A7 (D-), J10.B7 (D-); also elsewhere on the board
/interface/USB2_DP: J10.A6 (D+), J10.B6 (D+); also elsewhere on the board
unnamed: D32.2 (A), RN9.8 (R1.2)
unnamed: D33.2 (A), RN9.7 (R2.2)
unnamed: D34.2 (A), RN9.6 (R3.2)
unnamed: D35.2 (A), RN9.5 (R4.2)
unnamed: D36.2 (A), RN10.8 (R1.2)
unnamed: D37.2 (A), RN10.7 (R2.2)
unnamed: D38.2 (A), RN10.6 (R3.2)
unnamed: D39.2 (A), RN10.5 (R4.2)
unnamed: D40.2 (A), RN11.8 (R1.2)
unnamed: D41.2 (A), RN11.7 (R2.2)
unnamed: D42.2 (A), RN11.6 (R3.2)
unnamed: D43.2 (A), RN11.5 (R4.2)
unnamed: F1.1, J9.A4 (VBUS), J9.A9 (VBUS), J9.B4 (VBUS), J9.B9 (VBUS)
unnamed: J9.A5 (CC1), R78.2
unnamed: J9.B5 (CC2), R79.2
unnamed: J10.A5 (CC1), R80.2
unnamed: J10.B5 (CC2), R81.2
VBUS: C63.1, J10.A4 (VBUS), J10.A9 (VBUS), J10.B4 (VBUS), J10.B9 (VBUS); also elsewhere on the board
WCH_VCC: RN11.4 (R4.1); also elsewhere on the board
coin: J7.13, J8.5, J11.5; also elsewhere on the board
down: J7.3, J8.14, J11.8; also elsewhere on the board
enter: J7.9, J8.17, J11.11; also elsewhere on the board
service: J7.7, J8.12, J11.3; also elsewhere on the board
test: J7.11, J8.7, J11.4; also elsewhere on the board
up: J7.5, J8.13, J11.7; also elsewhere on the board

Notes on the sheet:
LEDS
SETTING USB
12 AISA
14+
SENSOR INPUT
MAIN USB

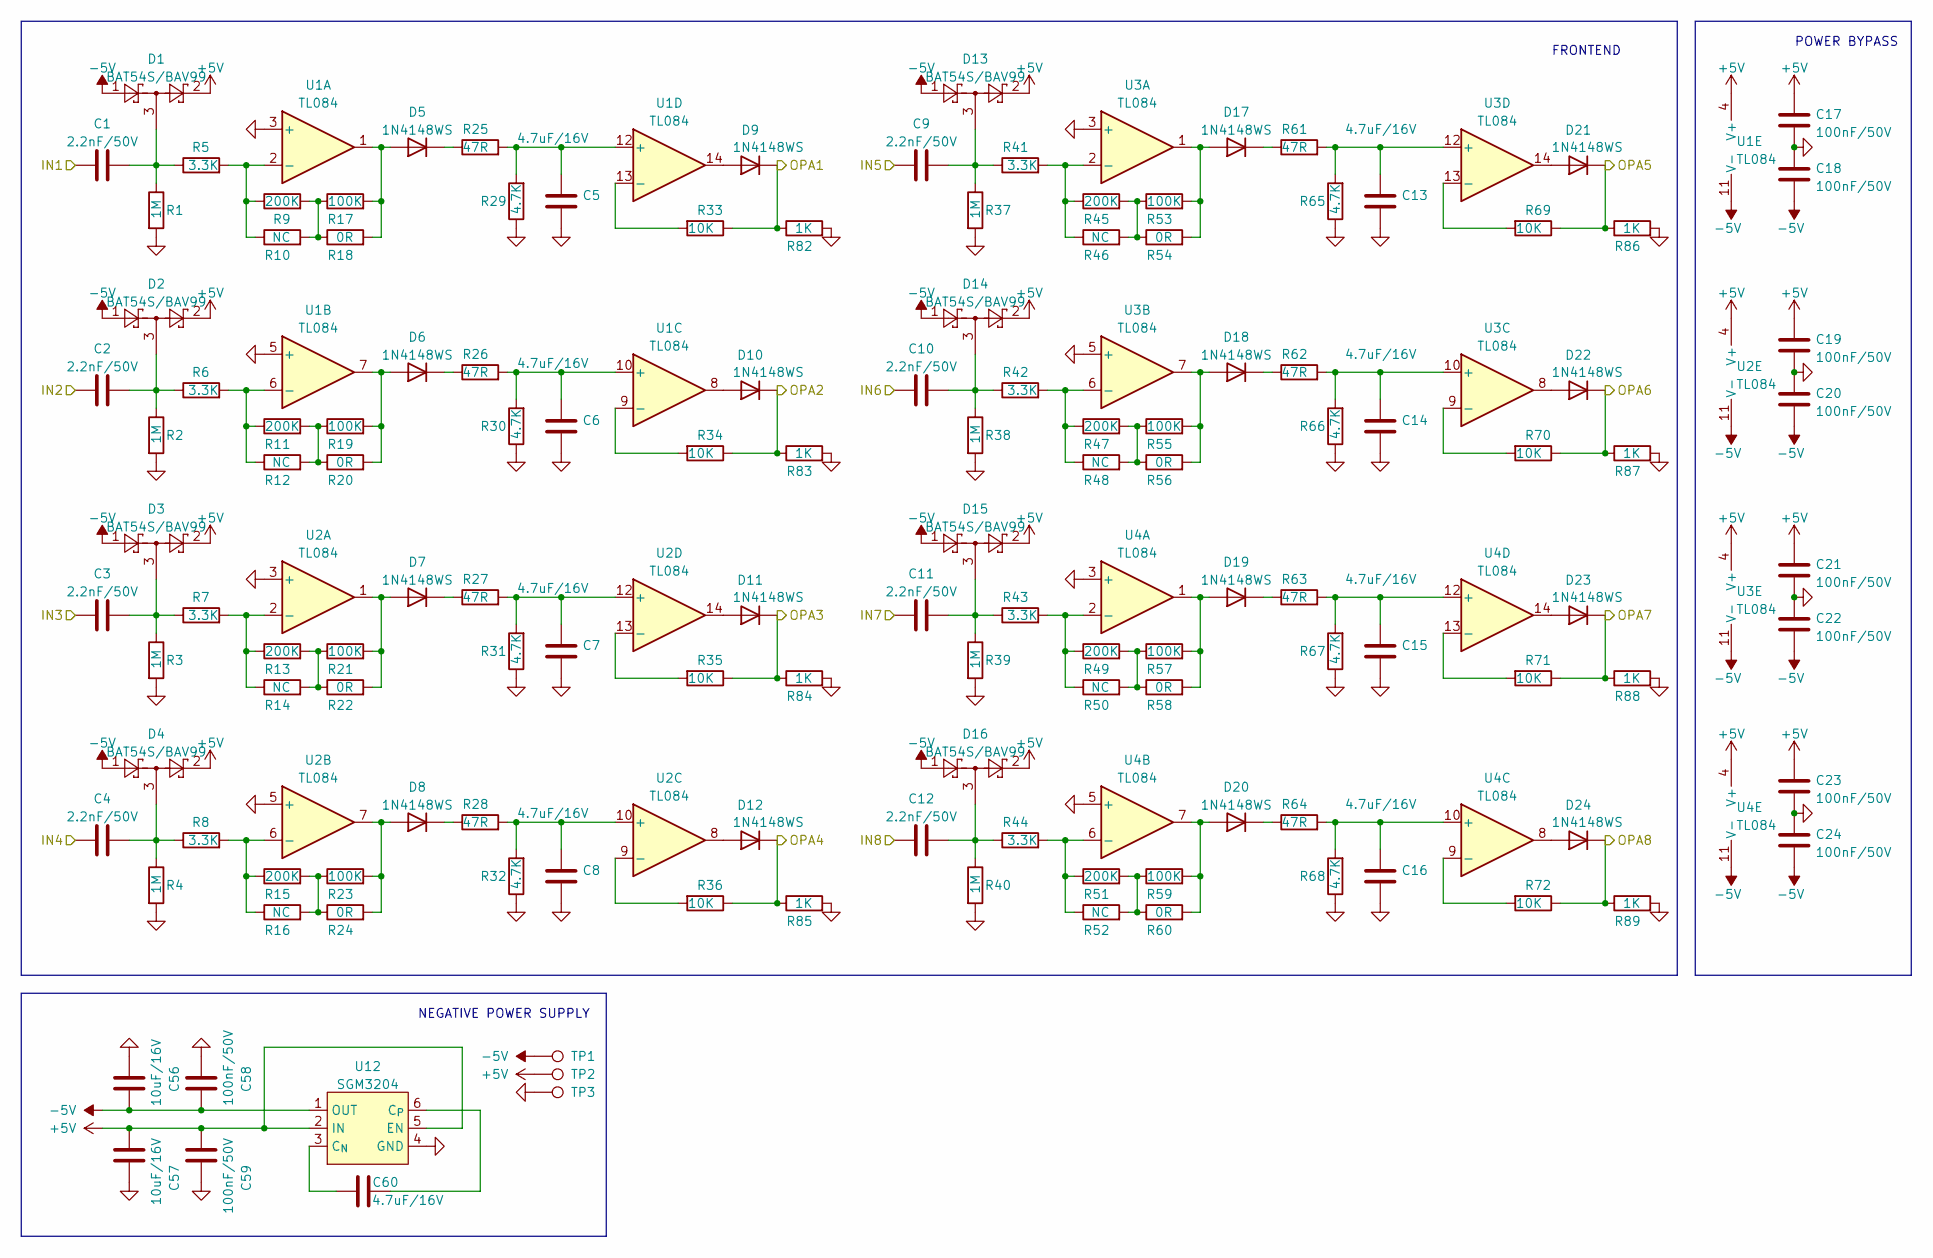
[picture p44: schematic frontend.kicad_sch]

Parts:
C1, C2, C3, C4, C9, C10, C11, C12: 2.2nF/50V; C_0603_1608Metric
C5, C6, C7, C8, C13, C14, C15, C16, C60: 4.7uF/16V; C_0603_1608Metric
C17, C18, C19, C20, C21, C22, C23, C24, C58, C59: 100nF/50V; C_0603_1608Metric
C56, C57: 10uF/16V; C_0603_1608Metric
D1, D2, D3, D4, D13, D14, D15, D16: BAT54S/BAV99; SOT-23
D5, D6, D7, D8, D9, D10, D11, D12, D17, D18, D19, D20, D21, D22, D23, D24: 1N4148WS; SOD_323_1
R1, R2, R3, R4, R37, R38, R39, R40: 1M; R_0603_1608Metric
R5, R6, R7, R8, R41, R42, R43, R44: 3.3K; R_0603_1608Metric
R9, R11, R13, R15, R45, R47, R49, R51: 200K; R_0603_1608Metric
R10, R12, R14, R16, R46, R48, R50, R52: NC; R_0603_1608Metric
R17, R19, R21, R23, R53, R55, R57, R59: 100K; R_0603_1608Metric
R18, R20, R22, R24, R54, R56, R58, R60: 0R; R_0603_1608Metric
R25, R26, R27, R28, R61, R62, R63, R64: 47R; R_0603_1608Metric
R29, R30, R31, R32, R65, R66, R67, R68: 4.7K; R_0603_1608Metric
R33, R34, R35, R36, R69, R70, R71, R72: 10K; R_0603_1608Metric
R82, R83, R84, R85, R86, R87, R88, R89: 1K; R_0603_1608Metric
TP1, TP2, TP3: TestPoint; TestPoint_THTPad_D2.0mm_Drill1.0mm
U1, U2, U3, U4: TL084; SOIC-14_3.9x8.7mm_P1.27mm
U12: SGM3204; SOT-23-6

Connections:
+5V: C17.2, C19.2, C21.2, C23.2, C57.1, C59.1, D1.2, D2.2, D3.2, D4.2, D13.2, D14.2, D15.2, D16.2, TP2.1, U1.4 (V+), U2.4 (V+), U3.4 (V+), U4.4 (V+), U12.2 (IN), U12.5 (EN); also elsewhere on the board
-5V: C18.1, C20.1, C22.1, C24.1, C56.2, C58.2, D1.1, D2.1, D3.1, D4.1, D13.1, D14.1, D15.1, D16.1, TP1.1, U1.11 (V-), U2.11 (V-), U3.11 (V-), U4.11 (V-), U12.1 (OUT)
/frontend/IN1: C1.1; also elsewhere on the board
/frontend/IN2: C2.1; also elsewhere on the board
/frontend/IN3: C3.1; also elsewhere on the board
/frontend/IN4: C4.1; also elsewhere on the board
/frontend/IN5: C9.1; also elsewhere on the board
/frontend/IN6: C10.1; also elsewhere on the board
/frontend/IN7: C11.1; also elsewhere on the board
/frontend/IN8: C12.1; also elsewhere on the board
/frontend/OPA1: D9.1 (K), R33.1, R82.1; also elsewhere on the board
/frontend/OPA2: D10.1 (K), R34.1, R83.1; also elsewhere on the board
/frontend/OPA3: D11.1 (K), R35.1, R84.1; also elsewhere on the board
/frontend/OPA4: D12.1 (K), R36.1, R85.1; also elsewhere on the board
/frontend/OPA5: D21.1 (K), R69.1, R86.1; also elsewhere on the board
/frontend/OPA6: D22.1 (K), R70.1, R87.1; also elsewhere on the board
/frontend/OPA7: D23.1 (K), R71.1, R88.1; also elsewhere on the board
/frontend/OPA8: D24.1 (K), R72.1, R89.1; also elsewhere on the board
unnamed: C1.2, D1.3, R1.1, R5.1
unnamed: C2.2, D2.3, R2.1, R6.1
unnamed: C3.2, D3.3, R3.1, R7.1
unnamed: C4.2, D4.3, R4.1, R8.1
unnamed: C9.2, D13.3, R37.1, R41.1
unnamed: C10.2, D14.3, R38.1, R42.1
unnamed: C11.2, D15.3, R39.1, R43.1
unnamed: C12.2, D16.3, R40.1, R44.1
unnamed: D5.2 (A), R17.2, R18.2, U1.1
unnamed: D5.1 (K), R25.1
unnamed: D6.2 (A), R19.2, R20.2, U1.7
unnamed: D6.1 (K), R26.1
unnamed: D7.2 (A), R21.2, R22.2, U2.1
unnamed: D7.1 (K), R27.1
unnamed: D8.2 (A), R23.2, R24.2, U2.7
unnamed: D8.1 (K), R28.1
unnamed: D9.2 (A), U1.14
unnamed: D10.2 (A), U1.8
unnamed: D11.2 (A), U2.14
unnamed: D12.2 (A), U2.8
unnamed: D17.2 (A), R53.2, R54.2, U3.1
unnamed: D17.1 (K), R61.1
unnamed: D18.2 (A), R55.2, R56.2, U3.7
unnamed: D18.1 (K), R62.1
unnamed: D19.2 (A), R57.2, R58.2, U4.1
unnamed: D19.1 (K), R63.1
unnamed: D20.2 (A), R59.2, R60.2, U4.7
unnamed: D20.1 (K), R64.1
unnamed: D21.2 (A), U3.14
unnamed: D22.2 (A), U3.8
unnamed: D23.2 (A), U4.14
unnamed: D24.2 (A), U4.8
unnamed: R9.2, R10.2, R17.1, R18.1
unnamed: R11.2, R12.2, R19.1, R20.1
unnamed: R13.2, R14.2, R21.1, R22.1
unnamed: R15.2, R16.2, R23.1, R24.1
unnamed: R45.2, R46.2, R53.1, R54.1
unnamed: R47.2, R48.2, R55.1, R56.1
unnamed: R49.2, R50.2, R57.1, R58.1
unnamed: R51.2, R52.2, R59.1, R60.1
unnamed: R5.2, R9.1, R10.1, U1.2 (-)
unnamed: R6.2, R11.1, R12.1, U1.6 (-)
unnamed: C6.2, R26.2, R30.2, U1.10 (+)
unnamed: R34.2, U1.9 (-)
unnamed: C5.2, R25.2, R29.2, U1.12 (+)
unnamed: R33.2, U1.13 (-)
unnamed: R7.2, R13.1, R14.1, U2.2 (-)
unnamed: R8.2, R15.1, R16.1, U2.6 (-)
unnamed: C8.2, R28.2, R32.2, U2.10 (+)
unnamed: R36.2, U2.9 (-)
unnamed: C7.2, R27.2, R31.2, U2.12 (+)
unnamed: R35.2, U2.13 (-)
unnamed: R41.2, R45.1, R46.1, U3.2 (-)
unnamed: R42.2, R47.1, R48.1, U3.6 (-)
unnamed: C14.2, R62.2, R66.2, U3.10 (+)
unnamed: R70.2, U3.9 (-)
unnamed: C13.2, R61.2, R65.2, U3.12 (+)
unnamed: R69.2, U3.13 (-)
unnamed: R43.2, R49.1, R50.1, U4.2 (-)
unnamed: R44.2, R51.1, R52.1, U4.6 (-)
unnamed: C16.2, R64.2, R68.2, U4.10 (+)
unnamed: R72.2, U4.9 (-)
unnamed: C15.2, R63.2, R67.2, U4.12 (+)
unnamed: R71.2, U4.13 (-)
unnamed: C60.2, U12.3 (C_{N})
unnamed: C60.1, U12.6 (C_{P})

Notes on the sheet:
FRONTEND
POWER BYPASS
NEGATIVE POWER SUPPLY

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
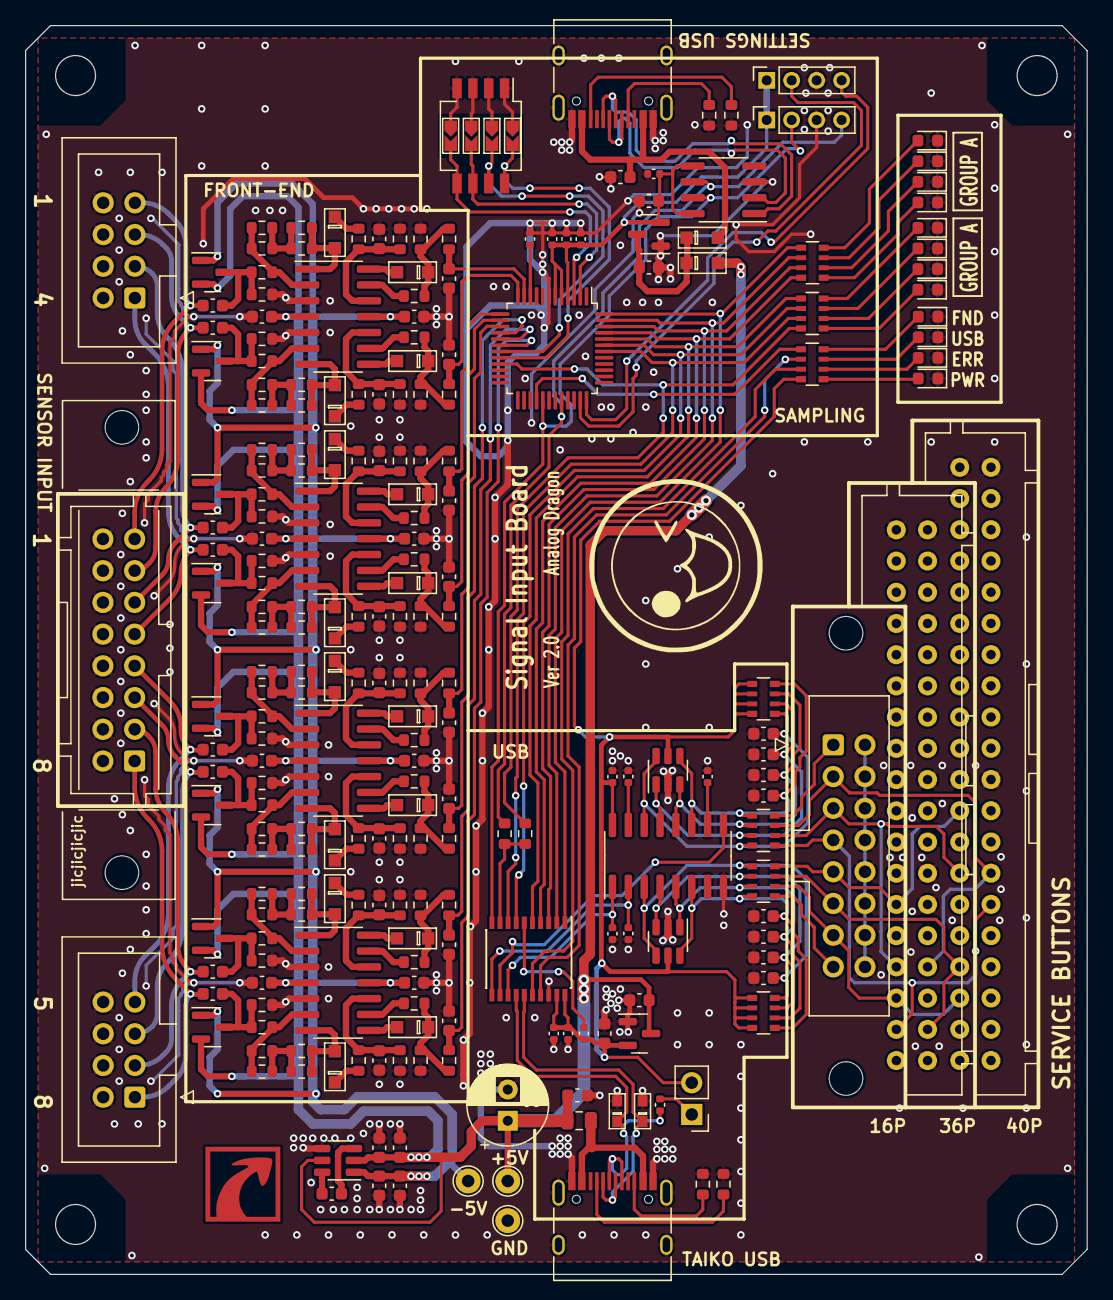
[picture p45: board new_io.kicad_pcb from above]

Board: 2 copper layers, 85.0 x 100.0 mm, 240 parts (0 on the bottom side), 162 nets.

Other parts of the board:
R90, R91, R92, R93, R94, R95, R96, R97: 1K; R_0603_1608Metric

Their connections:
/frontend/OPA1: R90.1; also elsewhere on the board
/frontend/OPA2: R91.1; also elsewhere on the board
/frontend/OPA3: R92.1; also elsewhere on the board
/frontend/OPA4: R93.1; also elsewhere on the board
/frontend/OPA5: R94.1; also elsewhere on the board
/frontend/OPA6: R95.1; also elsewhere on the board
/frontend/OPA7: R96.1; also elsewhere on the board
/frontend/OPA8: R97.1; also elsewhere on the board

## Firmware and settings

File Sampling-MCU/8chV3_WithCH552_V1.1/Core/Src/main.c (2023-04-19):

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
/* Includes ------------------------------------------------------------------*/
#include "main.h"

/* USER CODE BEGIN Includes */
#include "save.h"


/* USER CODE END Includes */

ADC_HandleTypeDef hadc1;
DMA_HandleTypeDef hdma_adc1;

IWDG_HandleTypeDef hiwdg;

TIM_HandleTypeDef htim14;

UART_HandleTypeDef huart1;
DMA_HandleTypeDef hdma_usart1_tx;

void SystemClock_Config(void);
static void MX_GPIO_Init(void);
static void MX_IWDG_Init(void);
static void MX_DMA_Init(void);
static void MX_USART1_UART_Init(void);
static void MX_TIM14_Init(void);
static void MX_ADC1_Init(void);
/* USER CODE BEGIN 0 */

#ifdef IS_4CH_MODE

#define ADC_BUFFER_SIZE     10
#define ADC_LIST_SIZE       6
#define ADC_CHANNEL_NUM     8
#define CHANNEL_NUM     		4

#else

#define ADC_BUFFER_SIZE     10
#define ADC_LIST_SIZE       6
#define ADC_CHANNEL_NUM     8
#define CHANNEL_NUM     		8

#endif


uint8_t POWER_ON_EN = 0;

//
void GPIO_Output(uint8_t IO, uint8_t state){
  switch(IO){
    case 0:if(state)OUT1_GPIO_Port->BSRR = (uint32_t)OUT1_Pin;else OUT1_GPIO_Port->BRR = (uint32_t)OUT1_Pin;break;
    case 1:if(state)OUT2_GPIO_Port->BSRR = (uint32_t)OUT2_Pin;else OUT2_GPIO_Port->BRR = (uint32_t)OUT2_Pin;break;
    case 2:if(state)OUT3_GPIO_Port->BSRR = (uint32_t)OUT3_Pin;else OUT3_GPIO_Port->BRR = (uint32_t)OUT3_Pin;break;
    case 3:if(state)OUT4_GPIO_Port->BSRR = (uint32_t)OUT4_Pin;else OUT4_GPIO_Port->BRR = (uint32_t)OUT4_Pin;break;
#ifndef IS_4CH_MODE
    case 4:if(state)OUT5_GPIO_Port->BSRR = (uint32_t)OUT5_Pin;else OUT5_GPIO_Port->BRR = (uint32_t)OUT5_Pin;break;
    case 5:if(state)OUT6_GPIO_Port->BSRR = (uint32_t)OUT6_Pin;else OUT6_GPIO_Port->BRR = (uint32_t)OUT6_Pin;break;
    case 6:if(state)OUT7_GPIO_Port->BSRR = (uint32_t)OUT7_Pin;else OUT7_GPIO_Port->BRR = (uint32_t)OUT7_Pin;break;
    case 7:if(state)OUT8_GPIO_Port->BSRR = (uint32_t)OUT8_Pin;else OUT8_GPIO_Port->BRR = (uint32_t)OUT8_Pin;break;
#endif
  }
}

uint16_t OutListFerq = 1000; //us

volatile uint16_t I_Buffer = 0;
volatile uint16_t O_Buffer = 0;
volatile uint16_t O_CountDown[CHANNEL_NUM] = {0};

volatile uint16_t ADC_Buffer[ADC_BUFFER_SIZE][ADC_CHANNEL_NUM];
volatile uint16_t ADC_List[ADC_CHANNEL_NUM][ADC_LIST_SIZE];
volatile uint16_t ADC_Now[ADC_CHANNEL_NUM];

volatile uint16_t ADC_Zero[ADC_CHANNEL_NUM] = {0};

volatile uint8_t InputCount[CHANNEL_NUM] = {0};
volatile uint16_t InputLevel_MAX[CHANNEL_NUM] = {0};
volatile uint16_t InputLevel_Now[CHANNEL_NUM] = {0};


uint8_t SystemError = 0;
uint8_t SystemTest = 0;

#ifndef IS_4CH_MODE
uint8_t SET_1 = 0;
uint8_t SET_2 = 0;
uint8_t SET_3 = 0;
uint8_t SET_4 = 0;
#endif
//输出函数
void IO_OutputList(void){
 
  for(uint8_t i = 0; i < CHANNEL_NUM; i ++){
    if(O_Buffer & (1 << i)){
			
      if(POWER_ON_EN)
        GPIO_Output(i, SystemSet.OutLoLength < O_CountDown[i]);
			
      O_CountDown[i]--;
			
      if(O_CountDown[i] == 0){
        O_Buffer &= ~(1 << i);
				I_Buffer &= ~(1 << i);
      }
    }
    else{
      O_CountDown[i] = 0;
      GPIO_Output(i, 0);
    }
  }
}


//清除操作
void DoMute(uint8_t ID){
	I_Buffer &= ~(1 << ID);
	InputCount[ID] = 0;
	InputLevel_MAX[ID] = 0;
}

//操作输出
void DoOutput(uint8_t ID){
  
  UartDebug();
  
	//清除整组异端
  if(SystemSet.ADC_Mute_Side){
    
    if(ID > 3){
      DoMute(4);
      DoMute(5);
      DoMute(6);
      DoMute(7);
    }
    else{
      DoMute(0);
      DoMute(1);
      DoMute(2);
      DoMute(3);
    }
    
  }
  else{
    
    if(ID == 0 || ID == 3){
      DoMute(1);
      DoMute(2);
    }
    else if(ID == 1 || ID == 2){
      DoMute(0);
      DoMute(3);
    }
    else if(ID == 4 || ID == 7){
      DoMute(5);
      DoMute(6);
    }
    else if(ID == 5 || ID == 6){
      DoMute(4);
      DoMute(7);
    }
    else return;
    
    DoMute(ID);
    
  }
	
  //allow output
  O_Buffer |= 1 << ID;
  O_CountDown[ID] = SystemSet.OutHiLength + SystemSet.OutLoLength;
	//here need to make all channel mute
}


void REG_Output(uint8_t ID,uint16_t Level){
	
	//首次登记
	if(((I_Buffer>>ID)&1) == 0){
		I_Buffer |= 1<<ID;
		InputCount[ID] = 0;
	}
	
	//记录最大值
	if(Level > InputLevel_MAX[ID]){
		InputLevel_MAX[ID] = Level;
	}
	
}

//查找最大值，仅用于登记后
uint8_t CheckAdcMax(uint8_t ID, uint16_t* pValueList){
	
  uint16_t ADC_Value = pValueList[ID];
	
  if(SystemSet.ADC_Mute_Side){    
    
    switch(ID){
      //1P
      case 0:
        if(
          ADC_Value < pValueList[1]
         ||ADC_Value < pValueList[2]
         ||ADC_Value < pValueList[3]
          ){
          return 0;
        }
        else{
          return 1;
        }
        
      case 1:
        if(
          ADC_Value < pValueList[0]
         ||ADC_Value < pValueList[2]
         ||ADC_Value < pValueList[3]
          ){
          return 0;
        }
        else{
          return 1;
        }
        
      case 2:
        if(
          ADC_Value < pValueList[1]
         ||ADC_Value < pValueList[0]
         ||ADC_Value < pValueList[3]
          ){
          return 0;
        }
        else{
          return 1;
        }
        
      case 3:
        if(
          ADC_Value < pValueList[1]
         ||ADC_Value < pValueList[2]
         ||ADC_Value < pValueList[0]
          ){
          return 0;
        }
        else{
          return 1;
        }
        
        //2P
      case 4:
        if(
          ADC_Value < pValueList[5]
         ||ADC_Value < pValueList[6]
         ||ADC_Value < pValueList[7]
          ){
          return 0;
        }
        else{
          return 1;
        }
        
      case 5:
        if(
          ADC_Value < pValueList[4]
         ||ADC_Value < pValueList[6]
         ||ADC_Value < pValueList[7]
          ){
          return 0;
        }
        else{
          return 1;
        }
        
      case 6:
        if(
          ADC_Value < pValueList[5]
         ||ADC_Value < pValueList[4]
         ||ADC_Value < pValueList[7]
          ){
          return 0;
        }
        else{
          return 1;
        }
        
      case 7:
        if(
          ADC_Value < pValueList[5]
         ||ADC_Value < pValueList[6]
         ||ADC_Value < pValueList[4]
          ){
          return 0;
        }
        else{
          return 1;
        }
    }

  }
  
  else{    
    
    switch(ID){
      //1P
      case 0:
        if(
          ADC_Value < pValueList[1]
         ||ADC_Value < pValueList[2]
          ){
          return 0;
        }
        else{
          return 1;
        }
        
      case 1:
        if(
          ADC_Value < pValueList[0]
         ||ADC_Value < pValueList[3]
          ){
          return 0;
        }
        else{
          return 1;
        }
        
      case 2:
        if(
         ADC_Value < pValueList[0]
         ||ADC_Value < pValueList[3]
          ){
          return 0;
        }
        else{
          return 1;
        }
        
      case 3:
        if(
          ADC_Value < pValueList[1]
         ||ADC_Value < pValueList[2]
          ){
          return 0;
        }
        else{
          return 1;
        }
        
        //2P
      case 4:
        if(
          ADC_Value < pValueList[5]
         ||ADC_Value < pValueList[6]
          ){
          return 0;
        }
        else{
          return 1;
        }
        
      case 5:
        if(
          ADC_Value < pValueList[4]
         ||ADC_Value < pValueList[7]
          ){
          return 0;
        }
        else{
          return 1;
        }
        
      case 6:
        if(
         ADC_Value < pValueList[4]
         ||ADC_Value < pValueList[7]
          ){
          return 0;
        }
        else{
          return 1;
        }
        
      case 7:
        if(
          ADC_Value < pValueList[5]
         ||ADC_Value < pValueList[6]
          ){
          return 0;
        }
        else{
          return 1;
        }
    }

  }
	
	return 0;
  
}


/*
原理：收到自己被触发后，等待设置时间到
在时间段内有高于自己值的就屏蔽自己
*/

void CalPxMute_V2(uint8_t ID){
	
	//查找组内最大是否为本通道
	if(CheckAdcMax(ID, (uint16_t*)InputLevel_MAX)){
		DoOutput(ID);
	}
	else{
		DoMute(ID);
	}
	
}


#define AUTO_ZERO_LEN		2048

void AutoZero(void){
	static uint32_t ADC_ADD[CHANNEL_NUM] = {0}; 
	static uint16_t Count = 0;
	 
	if(I_Buffer){
		memset(ADC_ADD, 0, sizeof(ADC_ADD));
		Count = 0;
	}
	else{
		for(uint8_t i=0; i<CHANNEL_NUM; i++){
			ADC_ADD[i] += ADC_Now[i];
		}
		Count++;
		
		if(Count >= AUTO_ZERO_LEN){
			for(uint8_t i=0; i<CHANNEL_NUM; i++){
				ADC_Zero[i] = ADC_ADD[i] / Count;
			}
			memset(ADC_ADD, 0, sizeof(ADC_ADD));
			Count = 0;
      if(POWER_ON_EN == 0){
        memset((uint8_t*)InputLevel_MAX, 0, sizeof(InputLevel_MAX));
        POWER_ON_EN = 1;
      }
		}
	}
}


 
void HAL_ADC_ConvHalfCpltCallback(ADC_HandleTypeDef *hadc)
{
  UNUSED(hadc);
  uint32_t temp;
	
	//calc adc value
	for(uint8_t i=0;i<CHANNEL_NUM;i++){

		//move list
		for(uint8_t j=0;j < (ADC_LIST_SIZE - 1);j++){
			ADC_List[i][(ADC_LIST_SIZE - 1) - j] = ADC_List[i][(ADC_LIST_SIZE - 1) - j - 1];
		}
	
		//cal avg
		temp = 0;
		for(uint8_t j=0;j<ADC_BUFFER_SIZE;j++){
			temp += ADC_Buffer[j][SystemSet.ADC_ChannelRemap[i]];
		}
		ADC_Now[i] = (uint16_t)(temp * SystemSet.ADC_Mul[i] / ADC_BUFFER_SIZE / ADC_DIV_DEF);
		
		//Set Zero
		if(ADC_Zero[i] < ADC_Now[i])
			ADC_List[i][0] = ADC_Now[i] - ADC_Zero[i];
		else
			ADC_List[i][0] = 0;
		InputLevel_Now[i] = ADC_List[i][0];
		
	}
  
	
	//cale trigger
  if(SystemSet.MuteEnable == DISABLE){
		//without mute func
    
    for(uint8_t i=0;i<CHANNEL_NUM;i++){
      
      //cal trigger
      for(uint8_t j=0;j<(ADC_LIST_SIZE - 1);j++){
        if(ADC_List[i][0] > (ADC_List[i][j+1] + SystemSet.ADC_Trigger[i])){
          
          //REG OUTPUT
          I_Buffer |= 1<<i;
          if(((O_Buffer>>i)&1) == 0){
						UartDebug();
            O_CountDown[i] = SystemSet.OutHiLength + SystemSet.OutLoLength;
            O_Buffer |= 1 << i;
          }
          
          break;
        }
      }
    }
		
  }
	
	else if(SystemSet.ADC_WaitMuteTime == 0){
		//mute and time first
		uint16_t max_dt = 0;
		uint8_t max_id = 0;
		
		if(O_Buffer == 0){
			for(uint8_t i=0;i<CHANNEL_NUM;i++){
				for(uint8_t j=0;j<(ADC_LIST_SIZE - 1);j++){
					if(ADC_List[i][0] > ADC_List[i][j+1]){
						if(ADC_List[i][0] > (ADC_List[i][j+1] + SystemSet.ADC_Trigger[i])){	//do trigger
							
							if(max_dt < ADC_List[i][0] - ADC_List[i][j+1]){
								max_dt = ADC_List[i][0] - ADC_List[i][j+1];
								max_id = i;
							}
						}
					}
				}
			}
		}
		if(max_dt != 0){
			DoOutput(max_id);
		}
		
		//end of time first
	}
	
	else{
		//With Mute
		
		for(uint8_t i=0;i<CHANNEL_NUM;i++){
			//cal trigger
			if((I_Buffer>>i) & 1){	//This channel has been trigged , GetMax
					REG_Output(i, ADC_List[i][0]);
			}
			else{
				//寻找高脉冲边缘
				for(uint8_t j=0;j<(ADC_LIST_SIZE - 1);j++){
					
					if(ADC_List[i][0] > ADC_List[i][j+1]){
						if(ADC_List[i][0] > (ADC_List[i][j+1] + SystemSet.ADC_Trigger[i])){//do trigger
							
							//REG OUTPUT
							if(CheckAdcMax(i,(uint16_t*)InputLevel_Now))
								if(((O_Buffer>>i) & 1) == 0)  //This channel no output Now
									REG_Output(i, ADC_List[i][0]);//GetMax
								
						}
					}
					
				}
			}
		}
		
		//calculate output
		for(uint8_t i=0;i<CHANNEL_NUM;i++){
			if((I_Buffer >> i) & 1){
				InputCount[i]++;
				if(InputCount[i] >= SystemSet.ADC_WaitMuteTime){
					//time out
					CalPxMute_V2(i);
				}
			}
		}
		
		//end of mute
		
	}
	
	AutoZero();
	
  
}

#ifndef IS_4CH_MODE
 
void ReadSet(void){
  SET_1 = HAL_GPIO_ReadPin(SET1_GPIO_Port,SET1_Pin) == 0; //Debug EN
  SET_2 = HAL_GPIO_ReadPin(SET2_GPIO_Port,SET2_Pin) == 0; //load Set = Default
  SET_3 = HAL_GPIO_ReadPin(SET3_GPIO_Port,SET3_Pin) == 0; //Test IO
  SET_4 = HAL_GPIO_ReadPin(SET4_GPIO_Port,SET4_Pin) == 0; //timebase 2X
}

#endif



uint8_t SciBuffer[200];
uint8_t SciLength = 0;
uint8_t SciCount = 0;
uint8_t SciTime = 0;

void UsartStartRec(void){
  HAL_UART_AbortReceive_IT(&huart1);
  HAL_UART_Receive_IT(&huart1, SciBuffer, sizeof(SciBuffer));
}


uint8_t SciCheck(uint8_t* data, uint8_t len){
  if(len < 3)return 1;
  uint16_t CRCData1;
  uint16_t CRCData2;
  
  CRCData1 = CRCCheck(data, len-2);
  CRCData2 = data[len-1] | (data[len-2]<<8);
  
  if(CRCData1 == CRCData2)return 0;
  return 1;
}



void GetSciData(UART_HandleTypeDef *huart){
  
  SciCount++;
  SciLength = huart->RxXferSize - huart->RxXferCount;
  
  if(0 == SciCheck(SciBuffer,SciLength)){
    //check data cplt
    //do cmd
    SciDoCMD(SciBuffer, SciLength);
  }
  
  UsartStartRec();
}

void HAL_UART_RxCpltCallback(UART_HandleTypeDef *huart)
{
  GetSciData(huart);
}


uint8_t CloseIrqAndSave(void){
  uint8_t temp;
	
  HAL_TIM_Base_Stop_IT(&htim14);
  HAL_ADC_Stop_DMA(&hadc1);
	HAL_Delay(5);
	
  temp = DoSave();
	
  HAL_TIM_Base_Start_IT(&htim14);
  HAL_ADC_Start_DMA(&hadc1,(uint32_t *)ADC_Buffer,ADC_BUFFER_SIZE*ADC_CHANNEL_NUM);
	
  return temp;
}

//改为软件断帧
#define UART_FREAM_TIME		2

void UsartTask(void){
  static uint16_t RxXferCount_buf = 0xFF;
  
  if(huart1.RxXferCount != huart1.RxXferSize){
    
    if(RxXferCount_buf != huart1.RxXferCount){
      RxXferCount_buf = huart1.RxXferCount;
      SciTime = 0;
    }
    else{
      SciTime ++;
      if(SciTime > UART_FREAM_TIME){
        GetSciData(&huart1);
        SciTime = 0;
        RxXferCount_buf = 0xFF;
      }
    }
  }
  
}


//开机动画
void ON_Play(void){
  for(uint8_t i = 0; i < CHANNEL_NUM; i ++){
    GPIO_Output(i, 1);
    HAL_Delay(30);
  }
  for(uint8_t i = 0; i < CHANNEL_NUM; i ++){
    GPIO_Output(i, 0);
    HAL_Delay(30);
  }
}


/* USER CODE END 0 */

/**
  * @brief  The application entry point.
  * @retval int
  */
int main(void)
{
  /* USER CODE BEGIN 1 */
  uint16_t time = 0;
  /* USER CODE END 1 */

  /* MCU Configuration--------------------------------------------------------*/

  /* Reset of all peripherals, Initializes the Flash interface and the Systick. */
  HAL_Init();

  /* Configure the system clock */
  SystemClock_Config();

  /* Initialize all configured peripherals */
  MX_GPIO_Init();
  MX_IWDG_Init();
  MX_DMA_Init();
  MX_USART1_UART_Init();
  MX_TIM14_Init();
  MX_ADC1_Init();
  /* USER CODE BEGIN 2 */
  
  HAL_FLASH_Lock();
	
  HAL_Delay(10);
	
#ifdef IS_4CH_MODE

  SaveInit();
	
#else

  ReadSet();
  
  if(SET_4){
    OutListFerq = 2000;
    MX_TIM14_Init();
  }
  
  if(SET_2){
    SystemSet = SystemSetDefault;
  }
  else{
    SaveInit();
  }
	
#endif

	
#ifndef IS_4CH_MODE
	
	if(SET_3)
	{
		SystemSet = SystemSetTest;
		SystemTest = 1;
	}
	
#endif
	
  HAL_IWDG_Refresh(&hiwdg);
  ON_Play();
	
	HAL_ADCEx_Calibration_Start(&hadc1);
  HAL_TIM_Base_Start_IT(&htim14);
  HAL_ADC_Start_DMA(&hadc1,(uint32_t *)ADC_Buffer,ADC_BUFFER_SIZE*ADC_CHANNEL_NUM);
  HAL_Delay(500);

#ifndef IS_4CH_MODE
  if(SET_1)
#endif
	{
    HAL_UART_Transmit_DMA(&huart1, (uint8_t*)"Power On\r\n",sizeof("Power On\r\n")-1);
    UsartStartRec();
  }
	
  /* USER CODE END 2 */

  /* Infinite loop */
  /* USER CODE BEGIN WHILE */
  while (1)
  {
    
    HAL_IWDG_Refresh(&hiwdg);
    UsartTask();
    
    time++;
    if(time >= 100){
      time = 0;
      if(!SystemError && POWER_ON_EN){
				//开机自检成功闪灯
        HAL_GPIO_TogglePin(LED_STA_GPIO_Port,LED_STA_Pin);
      }
      else{
        HAL_GPIO_WritePin(LED_STA_GPIO_Port,LED_STA_Pin,GPIO_PIN_SET);
      }
    }
    
    HAL_Delay(1);
    /* USER CODE END WHILE */

    /* USER CODE BEGIN 3 */
  }
  /* USER CODE END 3 */
}

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
/* USER CODE BEGIN 4 */

#ifndef IS_4CH_MODE

/**
  * @brief GPIO Initialization Function
  * @param None
  * @retval None
  */
static void MX_GPIO_Init(void)
{
  GPIO_InitTypeDef GPIO_InitStruct = {0};

  /* GPIO Ports Clock Enable */
  __HAL_RCC_GPIOB_CLK_ENABLE();
  __HAL_RCC_GPIOC_CLK_ENABLE();
  __HAL_RCC_GPIOA_CLK_ENABLE();

  /*Configure GPIO pin Output Level */
  HAL_GPIO_WritePin(GPIOB, OUT1_Pin|OUT8_Pin|OUT7_Pin|OUT6_Pin
                          |OUT5_Pin|OUT4_Pin|OUT3_Pin|OUT2_Pin, GPIO_PIN_RESET);

  /*Configure GPIO pin Output Level */
  HAL_GPIO_WritePin(LED_STA_GPIO_Port, LED_STA_Pin, GPIO_PIN_RESET);

  /*Configure GPIO pins : OUT1_Pin OUT8_Pin OUT7_Pin OUT6_Pin
                           OUT5_Pin OUT4_Pin OUT3_Pin OUT2_Pin */
  GPIO_InitStruct.Pin = OUT1_Pin|OUT8_Pin|OUT7_Pin|OUT6_Pin
                          |OUT5_Pin|OUT4_Pin|OUT3_Pin|OUT2_Pin;
  GPIO_InitStruct.Mode = GPIO_MODE_OUTPUT_PP;
  GPIO_InitStruct.Pull = GPIO_NOPULL;
  GPIO_InitStruct.Speed = GPIO_SPEED_FREQ_LOW;
  HAL_GPIO_Init(GPIOB, &GPIO_InitStruct);

  /*Configure GPIO pins : SET3_Pin SET4_Pin */
  GPIO_InitStruct.Pin = SET3_Pin|SET4_Pin;
  GPIO_InitStruct.Mode = GPIO_MODE_INPUT;
  GPIO_InitStruct.Pull = GPIO_PULLUP;
  HAL_GPIO_Init(GPIOC, &GPIO_InitStruct);

  /*Configure GPIO pins : SET2_Pin SET1_Pin */
  GPIO_InitStruct.Pin = SET2_Pin|SET1_Pin;
  GPIO_InitStruct.Mode = GPIO_MODE_INPUT;
  GPIO_InitStruct.Pull = GPIO_PULLUP;
  HAL_GPIO_Init(GPIOB, &GPIO_InitStruct);

  /*Configure GPIO pin : LED_STA_Pin */
  GPIO_InitStruct.Pin = LED_STA_Pin;
  GPIO_InitStruct.Mode = GPIO_MODE_OUTPUT_PP;
  GPIO_InitStruct.Pull = GPIO_NOPULL;
  GPIO_InitStruct.Speed = GPIO_SPEED_FREQ_LOW;
  HAL_GPIO_Init(LED_STA_GPIO_Port, &GPIO_InitStruct);

}

#else

static void MX_GPIO_Init(void)
{
  GPIO_InitTypeDef GPIO_InitStruct = {0};

  /* GPIO Ports Clock Enable */
  __HAL_RCC_GPIOB_CLK_ENABLE();
  __HAL_RCC_GPIOC_CLK_ENABLE();
  __HAL_RCC_GPIOA_CLK_ENABLE();

  /*Configure GPIO pin Output Level */
  HAL_GPIO_WritePin(GPIOC, OUT2_Pin|OUT3_Pin, GPIO_PIN_RESET);

  /*Configure GPIO pin Output Level */
  HAL_GPIO_WritePin(GPIOA, LED_STA_Pin|OUT1_Pin|OUT4_Pin, GPIO_PIN_RESET);

  /*Configure GPIO pins : OUT2_Pin OUT3_Pin */
  GPIO_InitStruct.Pin = OUT2_Pin|OUT3_Pin;
  GPIO_InitStruct.Mode = GPIO_MODE_OUTPUT_PP;
  GPIO_InitStruct.Pull = GPIO_NOPULL;
  GPIO_InitStruct.Speed = GPIO_SPEED_FREQ_LOW;
  HAL_GPIO_Init(GPIOC, &GPIO_InitStruct);

  /*Configure GPIO pins : LED_STA_Pin OUT1_Pin OUT4_Pin */
  GPIO_InitStruct.Pin = LED_STA_Pin|OUT1_Pin|OUT4_Pin;
  GPIO_InitStruct.Mode = GPIO_MODE_OUTPUT_PP;
  GPIO_InitStruct.Pull = GPIO_NOPULL;
  GPIO_InitStruct.Speed = GPIO_SPEED_FREQ_LOW;
  HAL_GPIO_Init(GPIOA, &GPIO_InitStruct);

}

#endif


/* USER CODE END 4 */
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


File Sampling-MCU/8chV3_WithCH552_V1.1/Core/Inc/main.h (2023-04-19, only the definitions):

#define OUT2_Pin GPIO_PIN_14
#define OUT2_GPIO_Port GPIOC
#define OUT3_Pin GPIO_PIN_15
#define OUT3_GPIO_Port GPIOC
#define IN1_Pin GPIO_PIN_0
#define IN1_GPIO_Port GPIOA
#define IN2_Pin GPIO_PIN_1
#define IN2_GPIO_Port GPIOA
#define IN3_Pin GPIO_PIN_2
#define IN3_GPIO_Port GPIOA
#define IN4_Pin GPIO_PIN_3
#define IN4_GPIO_Port GPIOA
#define IN5_Pin GPIO_PIN_4
#define IN5_GPIO_Port GPIOA
#define IN6_Pin GPIO_PIN_5
#define IN6_GPIO_Port GPIOA
#define IN7_Pin GPIO_PIN_6
#define IN7_GPIO_Port GPIOA
#define IN8_Pin GPIO_PIN_7
#define IN8_GPIO_Port GPIOA
#define LED_STA_Pin GPIO_PIN_8
#define LED_STA_GPIO_Port GPIOA
#define OUT1_Pin GPIO_PIN_11
#define OUT1_GPIO_Port GPIOA
#define OUT4_Pin GPIO_PIN_12
#define OUT4_GPIO_Port GPIOA
#define SWDIO_Pin GPIO_PIN_13
#define SWDIO_GPIO_Port GPIOA
#define SWCLK_Pin GPIO_PIN_14
#define SWCLK_GPIO_Port GPIOA
#define OUT1_Pin GPIO_PIN_9
#define OUT1_GPIO_Port GPIOB
#define SET3_Pin GPIO_PIN_14
#define SET3_GPIO_Port GPIOC
#define SET4_Pin GPIO_PIN_15
#define SET4_GPIO_Port GPIOC
#define IN1_Pin GPIO_PIN_0
#define IN1_GPIO_Port GPIOA
#define IN2_Pin GPIO_PIN_1
#define IN2_GPIO_Port GPIOA
#define IN3_Pin GPIO_PIN_2
#define IN3_GPIO_Port GPIOA
#define IN4_Pin GPIO_PIN_3
#define IN4_GPIO_Port GPIOA
#define IN5_Pin GPIO_PIN_4
#define IN5_GPIO_Port GPIOA
#define IN6_Pin GPIO_PIN_5
#define IN6_GPIO_Port GPIOA
#define IN7_Pin GPIO_PIN_6
#define IN7_GPIO_Port GPIOA
#define IN8_Pin GPIO_PIN_7
#define IN8_GPIO_Port GPIOA
#define SET2_Pin GPIO_PIN_0
#define SET2_GPIO_Port GPIOB
#define SET1_Pin GPIO_PIN_1
#define SET1_GPIO_Port GPIOB
#define OUT8_Pin GPIO_PIN_2
#define OUT8_GPIO_Port GPIOB
#define LED_STA_Pin GPIO_PIN_8
#define LED_STA_GPIO_Port GPIOA
#define SWDIO_Pin GPIO_PIN_13
#define SWDIO_GPIO_Port GPIOA
#define SWCLK_Pin GPIO_PIN_14
#define SWCLK_GPIO_Port GPIOA
#define OUT7_Pin GPIO_PIN_3
#define OUT7_GPIO_Port GPIOB
#define OUT6_Pin GPIO_PIN_4
#define OUT6_GPIO_Port GPIOB
#define OUT5_Pin GPIO_PIN_5
#define OUT5_GPIO_Port GPIOB
#define OUT4_Pin GPIO_PIN_6
#define OUT4_GPIO_Port GPIOB
#define OUT3_Pin GPIO_PIN_7
#define OUT3_GPIO_Port GPIOB
#define OUT2_Pin GPIO_PIN_8
#define OUT2_GPIO_Port GPIOB

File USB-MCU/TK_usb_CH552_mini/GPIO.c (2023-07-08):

#include "GPIO.h"

#define GPIO_STA_FLOAT  0x0
#define GPIO_STA_PP     0x1
#define GPIO_STA_OD     0x2
#define GPIO_STA_DEF    0x3

void GPIO_SET(UINT8 Port, UINT8 IO, UINT8 STA){
  if(IO > 7)return;

  if(Port == 1){
    if(STA & 0x1)
      P1_DIR_PU |= 1<<IO;
    else
      P1_DIR_PU &= ~(1<<IO);
    
    if(STA & 0x2)
      P1_MOD_OC |= 1<<IO;
    else
      P1_MOD_OC &= ~(1<<IO);
  }
  
  if(Port == 3){
    if(STA & 0x1)
      P3_DIR_PU |= 1<<IO;
    else
      P3_DIR_PU &= ~(1<<IO);
    
    if(STA & 0x2)
      P3_MOD_OC |= 1<<IO;
    else
      P3_MOD_OC &= ~(1<<IO);
  }
}

void InitIO(void){
  
  GPIO_SET(3,2,GPIO_STA_FLOAT);
  GPIO_SET(1,4,GPIO_STA_FLOAT);
  GPIO_SET(1,5,GPIO_STA_FLOAT);
  GPIO_SET(1,6,GPIO_STA_FLOAT);
  
  IN1 = IN2 = IN3 = IN4 = 0;
  
  GPIO_SET(1,3,GPIO_STA_PP);
  
  LED_USB = 0;
  
  GPIO_SET(1,1,GPIO_STA_DEF);
  GPIO_SET(3,3,GPIO_STA_DEF);
  GPIO_SET(3,4,GPIO_STA_DEF);
  GPIO_SET(3,5,GPIO_STA_DEF);
  
  KEY1 = KEY2 = KEY3 = KEY4 = 1;
  
  
}

UINT8 READ_KEY(UINT8 ID){
	switch(ID){
// 		case 0:return (!IN1);
// 		case 1:return (!IN2);
// 		case 2:return (!IN3);
// 		case 3:return (!IN4);
    case 0:return (IN1);
    case 1:return (IN2);
    case 2:return (IN3);
    case 3:return (IN4);
	}
	return 0;
}

UINT8 READ_KEY2(UINT8 ID){
	switch(ID){
		case 0:return (!KEY1);
 		case 1:return (!KEY2);
		case 2:return (!KEY3);
 		case 3:return (!KEY4);
	}
	return 0;
}

extern UINT8 IO_ErrFlag;

#define HAND_TIME 2000
#define ERROR_TIME 20000
#define FILTER_TIME 2

UINT16 ReadIO(void){
	
	static UINT16 IO_COUNT[4] = {0};
	static UINT16 IO_COUNT_FILTER_UP[4] = {0};
	static UINT16 IO_COUNT_FILTER_DN[4] = {0};
	static UINT16 IODATA = 0;
	UINT8 i;

	for(i=0;i<4;i++){
		if(READ_KEY(i)){
			IO_COUNT_FILTER_DN[i] = 0;
			if(IO_COUNT_FILTER_UP[i] < FILTER_TIME)IO_COUNT_FILTER_UP[i]++;
			if(IO_COUNT[i] < ERROR_TIME)IO_COUNT[i]++;

			if(IO_COUNT_FILTER_UP[i] >= FILTER_TIME){
				IODATA |= 0x01<<i;
			}
			if(IO_COUNT[i] >= HAND_TIME){
				IODATA &= ~(0x01<<i);
			}
			if(IO_COUNT[i] >= ERROR_TIME){
				IO_ErrFlag |= 0x01<<i;
			}
		}
		else{
			IO_COUNT_FILTER_UP[i] = 0;
			if(IO_COUNT_FILTER_DN[i] < FILTER_TIME)IO_COUNT_FILTER_DN[i]++;

			if(IO_COUNT_FILTER_DN[i] >= FILTER_TIME){	 
				IODATA &= ~(0x01<<i);	 
				IO_ErrFlag &= ~(0x01<<i);
				IO_COUNT[i] = 0;
			}
		}
	}
  
  IODATA &= 0xFF;
  IODATA |= ReadIOSlow()<<8;
  
  return IODATA;
}


#define HAND_TIME2     6000
#define FILTER_TIME2   10

#define LONG_PRESS_TIME  2000

#define TRIGGER_TIME  (100)	//ms

UINT8 ReadIOSlow(void){
	
	static UINT16 IO_COUNT_FILTER_UP[4] = {0};
	static UINT16 IO_COUNT_FILTER_DN[4] = {0};
	static UINT8 IODATA = 0;
	static UINT8 IODATA_bak = 0;
	static KeyOut = 0;
	static UINT16 IODATA_count = 0;
	UINT8 i;

  UINT8C kEYtABLE[0x10] = {
//	#	|	1	|	2	|	3	|	4
	0x00, 
			0x01,	
			0x02,
					0x11,
			0x03,
					0x00,
					0x12,
							0x21, 
			0x04,
					0x1F,
					0x00, 
							0x00,
					0x13,
							0x00, 
		  				0x21,
				  				0x31, 
  };



	for(i=0;i<4;i++){
		if(READ_KEY2(i)){
			IO_COUNT_FILTER_DN[i] = 0;
			if(IO_COUNT_FILTER_UP[i] < FILTER_TIME2)IO_COUNT_FILTER_UP[i]++;

			if(IO_COUNT_FILTER_UP[i] >= FILTER_TIME2){
				IODATA |= 0x01<<i;
			}
		}
		else{
			IO_COUNT_FILTER_UP[i] = 0;
			if(IO_COUNT_FILTER_DN[i] < FILTER_TIME2)IO_COUNT_FILTER_DN[i]++;

			if(IO_COUNT_FILTER_DN[i] >= FILTER_TIME2){	 
				IODATA &= ~(0x01<<i);	 
			}
		}
	}
  
  if(IODATA){
    IODATA_count++;
  }
  else{
    IODATA_count = 0;
  }
  
  
//   if(KeyOut){
//     //当前有按键
//     if(IODATA == 0){
//       KeyOut = 0;
//     }
//   }
//   else{
//     if(IODATA_bak && IODATA == 0){
//       //按下并弹起
//       if(IODATA_bak == 1)KeyOut = 1;
//       else if(IODATA_bak == 2)KeyOut = 2;
//       else if(IODATA_bak == 4)KeyOut = 3;
//       else if(IODATA_bak == 8)KeyOut = 4;
//       else KeyOut = 0xFF;
//     }
//     else if(IODATA && IODATA_count > LONG_PRESS_TIME){
//       //长按
//       if(IODATA == 1)KeyOut = 0x81;
//       else if(IODATA == 2)KeyOut = 0x82;
//       else if(IODATA == 4)KeyOut = 0x83;
//       else if(IODATA == 8)KeyOut = 0x84;
//       else KeyOut = 0xFF;
//     }
//     else if(IODATA == 0x03){
//       KeyOut = 0x05;
//     }
//     else if(IODATA == 0x0C){
//       KeyOut = 0x06;
//     }
//   }

  if(KeyOut){
    //当前有按键
    if(IODATA == 0){
      KeyOut = 0;
    }
  }
  else{
    if(IODATA != 0 && IODATA_count >= TRIGGER_TIME){
      KeyOut = kEYtABLE[IODATA];
    }
  }

  IODATA_bak = IODATA;
  return KeyOut;
}



/*------------------------------data flash-----------------------------------*/

#define DEF_FLASH_OP_CHECK1     0xAA
#define DEF_FLASH_OP_CHECK2     0x55   

UINT8 Flash_Op_Check_Byte1 = 0x00;
UINT8 Flash_Op_Check_Byte2 = 0x00;
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

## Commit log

2023-06-22 update md
    [new_io.kicad_pcb]
2023-06-22 update ignore
    [BOM_Taiko_input_x4_2023-06-22.csv, PickAndPlace_Taiko_input_x4_2023-06-22.csv]
2023-06-23 Create README_EN.md
    翻译README
2023-07-08 update V201
    增加了mini版本可以關機保存當前啓動模式的功能。

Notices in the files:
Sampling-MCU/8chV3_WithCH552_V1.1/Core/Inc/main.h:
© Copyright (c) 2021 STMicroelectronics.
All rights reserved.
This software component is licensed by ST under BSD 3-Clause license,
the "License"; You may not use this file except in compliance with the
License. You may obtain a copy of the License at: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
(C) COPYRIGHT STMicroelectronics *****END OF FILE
